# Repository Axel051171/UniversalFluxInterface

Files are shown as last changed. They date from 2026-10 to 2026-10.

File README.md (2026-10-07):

# UFI – Universal Flux Interface (Headless)

Flux-Lese-/Schreibgerät für Disketten: STM32H723 (550 MHz) misst jede Flusswechsel-Zeit mit
275 MHz (3,6 ns) und streamt sie per USB an den PC. Kein Raspberry Pi, kein Betriebssystem auf
dem Gerät – das frühere CM5-/Modul-Konzept ist aufgegeben (steht in der Git-Historie).

| | |
|---|---|
| MCU | STM32H723ZGT6, 550 MHz |
| Auflösung | 275 MHz Timer-Capture (3,6 ns), Index auf derselben Zeitbasis |
| Puffer | 8 MB QSPI-PSRAM (Ringpuffer beim Streamen, bis 200 Umdrehungen) |
| USB | USB-C, Full Speed, Datenstrom ~2 Byte je Flusswechsel, sendet während die Diskette dreht |
| Laufwerke | 34-pol PC/Shugart (DENSITY, DRATE, bis 4 Laufwerke), Amiga DB23 (Header, 2 Laufwerke), Apple Disk II (20-pol, 2 Laufwerke), Commodore IEC (1541) |
| Schreiben | Timer + DMA, Precompensation, Verify, WRITE-LOCK-Jumper |
| Platine v0.7 | 110 × 97 mm, 4 Lagen, geschaltete und gemessene Laufwerksversorgung, 4 GB SD-NAND fest verbaut, Erweiterungsheader, Apple-Disk-II-Port, zweites Amiga-Laufwerk (JP3) |
| Ohne PC | Taster: ganze Diskette als SCP auf den internen Speicher (mit Qualitätsbericht) oder Disk-zu-Disk-Kopie, danach als USB-Laufwerk am PC abholen |
| Greaseweazle-kompatibel | `UFI.CFG protocol=gw`: die Greaseweazle-Werkzeuge (`gw read`, `gw write`, …) erkennen das Board direkt |
| USB-Floppy | Betriebsart-Schalter: PC-Disketten (360K–2,88 MB, DMF) erscheinen am PC als normales USB-Diskettenlaufwerk, ohne Treiber; Atari ST, Commodore 1581 und Amiga 880K als Block-Laufwerk (Sektorabbild wie ST/D81/ADF) |

## Aufbau des Repos

| Ordner | Inhalt |
|---|---|
| [`kicad/UFI_Headless/`](kicad/UFI_Headless/README.md) | Schaltplan, Layout, Fertigungsdaten (`fertigung/`), Build- und ECO-Skripte |
| [`firmware/`](firmware/) | STM32H723-Firmware (CMake, STM32Cube HAL) |
| [`software/ufi_host/`](software/ufi_host/README.md) | Python-Host (`ufi`): Lesen/Schreiben, SCP-Export, Protokollbeschreibung |
| [`docs/`](docs/) | Amiga-DB23-Adapterkabel |

## Firmware bauen

```bash
cmake -S firmware -B firmware/build -G Ninja
cmake --build firmware/build        # -> ufi_firmware.bin
```

Erwartet arm-none-eabi-gcc und STM32Cube H7 V1.11.0 unter `~/STM32Cube/Repository/STM32Cube_FW_H7_V1.11.0`
(Pfad in `firmware/CMakeLists.txt`).

Flashen per SWD oder USB-DFU (Taster A beim Einschalten halten bzw. `ufi bootloader`).

## Status

Platine v0.6 ist fertig für die Bestellung (ERC/DRC sauber, JLC-Daten in `kicad/UFI_Headless/fertigung/`) – [Bestell-Anleitung JLC](kicad/UFI_Headless/docs/Bestellung_JLC.md).
Hardware und Firmware sind noch nicht am echten Gerät getestet – Ablauf für den Prototyp: [Inbetriebnahme-Checkliste](kicad/UFI_Headless/docs/Inbetriebnahme.md).

Lizenz: siehe [LICENSE](LICENSE).

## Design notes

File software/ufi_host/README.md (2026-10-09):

# ufi – PC-Tool für die UFI Flux Engine (UFI Headless)

Kommandozeilen-Tool (Protokoll UFI v2, Rückfall auf v1) über den USB-CDC-Port (unter Windows ohne Treiber, COM-Port wird per VID/PID `1209:4F54` gefunden).
Alternativ (Firmware ≥ 1.10, `UFI.CFG` `protocol=gw`): das Gerät spricht das Greaseweazle-Protokoll (PID `1209:4F57`, „gw-compat“) und wird mit den Greaseweazle-Werkzeugen (`gw read`, `gw write`, …) benutzt – dann nicht mit `ufi`.
Liest Spuren als Flux und speichert sie als **SCP** (SuperCard Pro) – Dekodierung/Konvertierung mit vorhandenen Werkzeugen (HxC, Greaseweazle `gw convert`, FluxEngine). Schreibt SCP-Images zurück.

```bash
pip install -e software/ufi_host[dev]
ufi info
ufi select a && ufi motor on && ufi recal
ufi read 0 0 -r 3                         # Zusammenfassung (Flux-Anzahl, RPM je Umdrehung)
ufi read-disk -o disk.scp --tracks 80 --sides 2 -r 3 --drive a
ufi write-disk disk.scp --verify --drive amiga
ufi iec-reset && ufi iec-send 0x28 && ufi iec-recv
ufi bootloader                            # danach: dfu-util -a 0 -s 0x08000000:leave -D ufi_firmware.bin
```

Nur mit UFI v2 (Firmware ≥ 1.12):

```bash
ufi caps                                  # Board-Revision, Firmware, caps-Bits im Klartext
ufi files [PFAD]                          # Verzeichnis auf dem SD-NAND
ufi get DUMP0001.SCP [-o d.scp]           # Datei herunterladen (READ_FILE in 4-KB-Stücken)
ufi put lokal.bin NAME.BIN                # Datei hochladen
ufi rm NAME.BIN
ufi cfg                                   # UFI.CFG anzeigen
ufi cfg drive=amiga revs=5                # Zeilen setzen/anhängen, zurückschreiben, CFG_RELOAD
ufi events                                # alle Ereignisse einschalten und ausgeben bis Strg+C
ufi mode flux|sd|floppy|gw                # USB-Betriebsart (Gerät meldet sich neu an)
ufi dump [--drive a --tracks 80 --sides 2 -r 3] | dump-status | dump-abort | copy
ufi power [MASKE]                         # Board-Status; Maske Bit0 FDD_5V, Bit1 FDD_12V
```

Laufwerksdiagnose (Firmware ≥ 1.13, caps-Bit 11):

```bash
ufi rpm [UMDREHUNGEN]                     # Drehzahl aus den Indeximpulsen: min/mittel/max, Impulsbreite
ufi scan [pc|ds]                          # welche Laufwerke antworten (a/b/amiga/amiga2 bzw. ds0-ds3): TRK0, Diskette dreht, Schreibschutz
ufi index-sim 300|360|off [--pulse 2000]  # Indeximpulse auf J9 Pin 6 (Flippy-Disketten), ohne Argument: Abfrage
ufi index-sim 300 --internal [--no-pin]   # Firmware ≥ 1.14: Impulse gelten intern als Index (Lesen/Schreiben ohne Draht)
ufi read-disk -o d.scp --hard-sectors 16  # Firmware ≥ 1.14: hartsektoriert (10/16/32 Löcher), auch bei read/write/write-disk
ufi read 17 0 --quarter 2                 # Firmware ≥ 1.14: Apple-Viertelspur (17,5); auch seek/write --quarter 1-3
ufi read 17 0 --steps 50:17.1,100:17.2    # Firmware ≥ 1.14: Kopfschritte nach Zeitplan während des Lesens (Spiradisc); auch write
ufi analyze 0 0 -r 5                      # Firmware ≥ 1.14: Drehzahl, Abstands-Spitzen, Kodierung/Bitzelle, Spurlänge, schwache Bits, Index→erster Sektor
ufi dump --tracks 0                       # Firmware ≥ 1.14: Spurzahl automatisch (höchste erreichbare Spur); UFI.CFG track_search=1 für 40-Spur-Disketten
ufi rpm-select 360                        # Firmware ≥ 1.14: 3-Mode-Laufwerk 300/360 U/min (UFI.CFG rpm_line, rpm_360); Kontrolle: ufi rpm
ufi dump --drive iec --tracks 35          # Firmware ≥ 1.14: 1541 an J8 über den Laufwerkscontroller nach DUMPnnnn.D64 (+ .LOG mit Fehlerblöcken)
ufi iec-nib -o disk.g64 [--halftracks] [--tracks 41]   # Firmware ≥ 1.14: Rohspuren (GCR) per Laufwerkscode in eine G64, Kopierschutz/Halbspuren
```

## Protokoll UFI v2 (Standard)

`ufi` spricht **UFI v2** – Spezifikation: [docs/USB_Protokoll.md](../../docs/USB_Protokoll.md), Abschnitt 3 (Rahmen `55 AA`, type/cmd/seq/status/len, CRC-16/CCITT-FALSE, Daten-/Ende-Rahmen für Lesen und Schreiben, Ereignisse, Dateien). Implementierung: `ufi_host/protocol2.py` (`Device2`, `FrameParser`, `connect`).

- Beim Öffnen: Kanal-Reset (10000 Baud), dann `PING` als v2-Rahmen. Antwortet das Gerät nicht in v2 (alte Firmware), nimmt `ufi` das v1-Protokoll (unten) und weist auf ein Firmware-Update hin; v2-Befehle (`caps`, `files`, `cfg`, …) melden dann einen Fehler.
- Lesen: `READ` → Annahme, Daten-Rahmen mit dem Flusscode (275 MHz, wie v1-Stream), Ende-Rahmen mit Umdrehungszahl. SCP-Ausgabe identisch zum v1-Weg.
- Schreiben: `WRITE` mit `flux_count`/`byte_count`, dann Daten-Rahmen im Flusscode (≤ 4096 Byte je Rahmen), Ende-Rahmen nach dem Schreiben (bzw. Prüflesen mit `--verify`).
- `selftest` gibt es in v2 nicht (PSRAM-Test steht in `ufi info`); `rpm` nutzt ab Firmware 1.13 `DIAG_RPM` (Indeximpulse, Motor wird gestartet), davor liest es eine Umdrehung der aktuellen Spur (Motor muss laufen).

## Protokoll UFI v1 (alt, Firmware < 1.12; Stream-Lesen braucht eine Firmware mit `ufi_stream.c`)

- Host → Gerät: ein Paket ≤ 64 Byte je Befehl, `[cmd, args...]` (Codes in `ufi_host/protocol.py` = `ufi_command_t`).
- Gerät → Host: jede Nachricht beginnt mit `{u8 command, u8 status, u16 length}` + Payload. Status = Fehlercode aus `ufi_fixes.h` (Klartext in `protocol.ERRORS`).
- Lesen (`READ_TRACK` 0x20, Standard): Antwort, dann **während die Diskette dreht** `{0x2C, 0, len}`-Nachrichten mit einem fortlaufenden Bytestrom (verlustfrei, 275 MHz, ~2 Byte je Flusswechsel): `01–EF` = Delta 1 Byte, `F0–FC b` = Delta 240 + ((x−F0)<<8) + b, `FD u32` = Indexpuls (Ticks nach dem letzten Wechsel), `FE u32` = langes Delta. Zeit 0 = erster Index; Format in `firmware/src/ufi_stream.c`, Decoder `protocol.decode_stream`. Abschluss `{0x2D, status, 1}` + `[Umdrehungen]`.
- Lesen roh (`READ_TRACK_RAW` 0x21, `Device.read_track_raw`): erst nach der Aufnahme je Umdrehung `{0x2E, 0, 12}` + `{track, side, rev, flags, index_ticks, count}` + `count × u32` Zeitstempel (relativ zum Index), gleicher Abschluss.
- Lesen-Optionen (beide Lesebefehle): `[cmd, track, side, revs, flags, period_ms u16]`. `flags` Bit0 = **ohne Indexpuls** (Laufwerk/Diskette ohne Index, Flippy-Seite, hart sektoriert): Umdrehungsgrenzen alle `period_ms` (0 = 200 ms). `READ_TRACK` erlaubt bis 200 Umdrehungen (Ringpuffer), `READ_TRACK_RAW` bis 20.
- Schreiben: Antwort abwarten, dann `count × u32` Deltas als Rohdaten, Fertig-Meldung mit demselben Befehlscode.
- Schreiben kompakt (`WRITE_TRACK_C` 0x33): `[cmd, track, side, count u32, bytes u32, verify]`, dann `bytes` Bytes im Stream-Code von oben (ohne `FD`-Indexmarken), Fertig-Meldung `0x33`. Etwa halbe Upload-Menge.
- `DRIVE_TIMING` (0x17): 10 × u16 – `step_pulse_us, step_rate_us, settle_us, dir_change_us, side_settle_us, spinup_ms, select_settle_us, motor_off_s` (Motor aus nach Leerlauf, 0 = nie, Standard 30), `double_step` (1 = 40-Spur-Diskette im 80-Spur-Laufwerk), `precomp_ns` (0xFFFF = nach Datenrate, 0 = aus). Kürzere Nutzdaten überschreiben nur die vorderen Felder.
- Board v0.5: `BOARD_STATUS` (0x1B, optional `[maske]` Bit0 FDD_5V, Bit1 FDD_12V) → `{power u8, flags u8, i5_mA u16, i12_mA u16, board_id_mV u16}`, Flags: Bit0 WRITE-LOCK-Jumper, Bit1/2 Überstrom-Abschaltung 5 V/12 V, Bit3 SD-Speicher bereit, Bit4/5 Taster A/B. `PROBE_TRACKS` (0x1C) → höchste erreichbare Spur (fährt an den Endanschlag). `SD_INFO` (0x1D) → `{ready, status, card_type, bus_width, capacity_MB u32}`.
- Laufwerke (`SELECT_DRIVE` 0x10, `ufi select`): 1 `a` / 2 `b` (PC-Kabel mit Twist), 4 `amiga` (J7), 5 `iec`, ab Firmware 1.5 Shugart-Bus 6–9 `ds0`–`ds3` (gerades Kabel, Pin 10/12/14/6 – `ds3` nur mit JP1; Motor Pin 16 gemeinsam), ab Firmware 1.9 10 `amiga2` (zweites Amiga-Laufwerk an J7 Pin 9, Board v0.7 mit JP3), ab Firmware 1.11 3 `apple` / 11 `apple2` (Disk-II-Port J14/J15, Board v0.7; kein Index: Umdrehungen = 200-ms-Abschnitte). Laufwerk für Dump/USB-Floppy: `UFI.CFG` auf dem SD-NAND (`drive=…`, `tracks=`, `sides=`, `revs=`).
- Board v0.6, SD-NAND (4 GB, FAT32): `DUMP_START` (0x50, optional `[drive, tracks, sides, revs]`, Standard Laufwerk A, 80, 2, 3) liest die ganze Diskette ohne PC nach `DUMPnnnn.SCP` – dasselbe Dateiformat wie `ufi read-disk`. `DUMP_STATUS` (0x51) → `{state, error, track, side, file_no u16, fs_result, storage_ready}` (state 6 = fertig, 7 = Fehler; error 1 Speicher, 2 Laufwerk, 3 voll, 4 abgebrochen). `DUMP_ABORT` (0x52). `COPY_START` (0x54): Disk-zu-Disk-Kopie laut `UFI.CFG` (`copy_from`, `copy_to`, `tracks`, `sides`), Status über `DUMP_STATUS`. Zu jedem Dump entsteht `DUMPnnnn.LOG` (Qualitätsbericht). Während eines Dumps beantwortet das Gerät nur Status-Befehle, alles andere mit BUSY. `USB_MSC` (0x53, optional `[mode]`: 1 = SD-Laufwerk (Standard, PID 0x4F55), 2 = **USB-Floppy** (PID 0x4F56: Diskette in Laufwerk A als USB-Laufwerk, Formate: PC 360K/720K/1.2M/1.44M, DMF 1.68M, ED 2.88M (nur lesen), Atari ST 9/10 Sektoren (11: nur lesen), Commodore 1581, Amiga 880K – Nicht-PC-Formate als Sektorabbild in ST-/D81-/ADF-Reihenfolge; Spurpuffer mit Rückschreiben nach 1 s und Prüflesen)): Antwort, dann meldet sich das Gerät neu – zurück per Betriebsart-Schalter, Taster B ≥ 2 s (SD) oder Neustart. Am Gerät: Taster A ≥ 1 s = Dump, Taster B kurz = Abbruch, B ≥ 2 s = SD-Laufwerk an/aus (nur Schalter in Mitte); Betriebsart-Schalter an J13 (Pin 1 = USB-Floppy, Pin 2 = Mittelkontakt 3V3, Pin 3 = SD-Laufwerk, Mitte = Flux).
- `GET_INFO`: Firmware-Version mit Git-Revision und Build-Datum, Board inkl. Revision (BOARD_ID), MCU, PSRAM-Selbsttest.
- Diagnose: `SEEK_TEST` (0x1E) `[spur_a, spur_b, zyklen ≤ 50]` pendelt zwischen zwei Spuren (Schrittmotor/Kopf); `WRITE_PATTERN` (0x34) `[track, side, interval_ns u16, dauer_ms u16 ≤ 5000]` schreibt ein konstantes Flussintervall (Schreibkette am Oszilloskop) – nur bei laufendem Motor, ohne WRITE-LOCK-Jumper und ohne Schreibschutz. Beide antworten erst am Ende.
- Startmodi (Taster beim Einschalten halten): A = ROM-DFU-Bootloader (Rettung ohne funktionierende Firmware), B = Sicherheitsmodus, Laufwerksversorgung bleibt aus (ERR-LED an, `BOARD_STATUS` Flag Bit6), einschalten per `BOARD_STATUS [maske]`.
- Sicherheit in der Firmware: USB weg > 300 ms → Transfers abbrechen, Motor aus, Laufwerk abwählen, WGATE frei; Laufwerksversorgung > 1,5 A für 50 ms → Schiene aus.

Tests ohne Hardware (simuliertes v1- und v2-Gerät auf Byte-Ebene, inkl. geteilter Rahmen, CRC-Fehler, Dateien, Rückfall auf v1): `python -m pytest software/ufi_host/tests`.

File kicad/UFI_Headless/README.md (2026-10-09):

# UFI Headless – STM32H723 Flux Engine (ohne CM5)

Status: **Schaltplan + Layout v0.6** – ERC 0 Verstöße, alle Netze per Netlist-Export geprüft; PCB-DRC 0 Fehler, 0 Warnungen (Details unten).

| Sheet | Inhalt | Status |
|---|---|---|
| Power | USB-C (5V + Daten), 12V-Hohlstecker, TPS54202 Buck 12→5V, TPS2116 Power-Mux, AP7361C 3V3-LDO, FDD-Power-Ausgang über Polyfuses F2 (+5V, 1,1 A) / F3 (+12V, 1,1 A), Messpunkte TP1–TP4 (3V3, 5V, 12V, GND) | ✅ |
| MCU_Core | STM32H723ZGT6 (LQFP144), Entkopplung, VCAP, VDDA-Filter, HSE 25 MHz, Reset/Boot, SWD, Debug-UART, LEDs, **8 MB QSPI-PSRAM** APS6404L (U11) an OCTOSPI1 | ✅ |
| Flux_Interface | 2× SN74LS07 Open-Collector (40 mA) für 10 Ausgänge, 74LVC14A Schmitt-Inverter für 6 Eingänge, 1k Pull-ups auf 5V, Messpunkte TP5 (RDATA) / TP6 (INDEX) | ✅ |
| FDD_Connectors | 34-pol IBM-PC/Shugart, Amiga 2×12-Header (Pin n = DB23 Pin n), ESD-Arrays D9–D11 (ESDA6V1-5SC6) auf 15 Busleitungen | ✅ |
| IEC_Bus | SN74LS07 + 74LVC14A, 1k Pull-ups, 1×6-Stiftleiste J8 (Pin n = DIN-6 Pin n: 1 SRQ, 2 GND, 3 ATN, 4 CLK, 5 DATA, 6 RESET), DIN-6-Buchse extern per Kabel, ESD-Array D12 | ✅ |

v0.2 (gegenüber v0.1): PSRAM, ESD-Schutz an den externen Ports, Polyfuses in der Laufwerksversorgung, Messpunkte. Neue Teile haben feste Referenzen oberhalb der v0.1-Maxima (U11, C46, R16, F2/F3, D9–D12, TP1–TP6), alle bestehenden Referenzen sind unverändert.

v0.4: J6 Pin 6 = DRATE über den freien LS07-Kanal U7.11→U7.10 (PF11, Pull-up RN3.3) und Lötbrücke **JP1** (offen ab Werk), J6 Pin 3 über 3-fach-Lötbrücke **JP2** (ab Werk 1-2 = GND). JP1/JP2 sind Kupfer-Jumper, keine Bestückung; Funktion steht im Bestückungsdruck auf der Rückseite, vorne markiert „5V“ die +5V-Seite von JP2 (`scripts/add_silk_label.py`).

v0.5 (neue Teile mit festen Referenzen ab Q1, U12, R17, C47, D13, J9, SW3, TP7):

| Funktion | Teile | Bedienung / Firmware |
|---|---|---|
| Laufwerksversorgung schaltbar | Q1/Q3 AO3401A (High-Side), Q2/Q4 2N7002, 100k-Pull-downs | FDD_5V/FDD_12V aus, solange die MCU im Reset ist; Firmware schaltet 5 V, dann 12 V ein (`BOARD_STATUS` 0x1B) |
| Strommessung | R26/R29 0,1 Ω + U12/U13 INA180A1 (2 V/A) → PC0/PC1 | > 1,5 A für 50 ms → Schiene aus, ERR-LED |
| TVS an den Laufwerksausgängen | D13 SMF5.0CA (FDD_5V), D14 SMAJ15CA (FDD_12V) | – |
| WRITE LOCK | J11 (Jumper), U14 74LVC1G32, R33 | Jumper gesteckt = WGATE in Hardware gesperrt, Firmware meldet „write protected“ |
| Erweiterung | J9 2×5: 3V3, 5V, I²C1 (PB6/PB7, 2,2k), GPIO PE0/PE1, Taster-Leitungen | z. B. OLED-Display + Taster für Betrieb ohne PC; Pin 6 (PE1) ab Firmware 1.13 wahlweise Index-Simulation (Open-Drain, `ufi index-sim 300`/`UFI.CFG index_sim=300`) → Draht an den Indexsensor-Ausgang eines PC-Laufwerks für Flippy-Disketten; dann kein Betriebsart-Schalter an J13 |
| Taster | SW3/SW4 (PB8/PB9, aktiv low) | frei für Firmware-Funktionen |
| ~~microSD~~ | in v0.6 durch SD-NAND U15 ersetzt (s. u.) | – |
| Board-ID | R17/R18 an PA4 | 10k/10k = 1,65 V = v0.5, 10k/4,7k = 1,06 V = v0.6; steht in `GET_INFO` |
| Messpunkte | TP7 WDATA, TP8 WGATE (MCU-Seite) | – |

v0.6 (Gerät kommt in ein geschlossenes Gehäuse): microSD-Slot J10 entfällt, dafür **SD-NAND U15** fest eingelötet an denselben SDMMC2-Leitungen (Pull-ups R21–R25, C47/C48 bleiben).

| Funktion | Teile | Bedienung / Firmware |
|---|---|---|
| Speicher 4 GB | U15 CSNP32GCR01-AOW (C2841139), LGA-8 8×6,2 mm; derselbe Footprint passt für MKDV8GIL-AST (1 GB, C26159627, günstiger) | FAT32, beim ersten Start formatiert (Volume „UFI“) |
| Dump ohne PC | Taster A ≥ 1 s | ganze Diskette → `DUMPnnnn.SCP` (byte-gleich mit `ufi read-disk`); Taster B kurz = Abbruch |
| Betriebsart-Schalter (optional, extern) | Kippschalter EIN-AUS-EIN an **J13** (1×3, Belegung wie der Schalter): Pin 1 → EXP_IO1/PE0, Pin 2 = 3V3 (Mittelkontakt), Pin 3 → EXP_IO2/PE1 (parallel zu J9 Pin 5/6, die dann nicht anders belegt werden dürfen) | Mitte = Flux (Host-Tool), Pin 1 = **USB-Floppy** (Diskette in Laufwerk A als USB-Laufwerk, PC-Formate 360K/720K/1.2M/1.44M, PID 0x4F56), Pin 3 = SD-Laufwerk. Nach jedem Wechsel blinkt ACT 1×/2×/3× = Flux/Floppy/SD |
| USB-Laufwerk | Taster B ≥ 2 s (nur Schalter in Mitte; oder `USB_MSC` 0x53) | Gerät meldet sich als Massenspeicher „UFI Flux Storage“ (PID 0x4F55), USB-LED an; Taster B ≥ 2 s zurück |
| Board-ID | R18 4,7k | 1,06 V = v0.6 |
| Einstellungen ohne PC | Datei `UFI.CFG` auf dem SD-NAND (wird beim ersten Start angelegt, im SD-Laufwerk-Modus am PC bearbeiten) | `drive=a\|b\|amiga\|amiga2\|ds0…ds3` (Laufwerk für Dump und USB-Floppy), `tracks=80`, `sides=2`, `revs=3`, `button_a=dump\|copy`, `copy_from=`/`copy_to=` (Laufwerksnamen wie bei `drive`), `protocol=ufi\|gw`; Schlüssel klein schreiben |
| Greaseweazle-Modus | Firmware 1.10, `UFI.CFG` `protocol=gw`, Schalter in Mitte (ACT blinkt 4×) | Gerät meldet sich als „UFI Flux Engine (gw-compat)“ (eigene PID 0x4F57); die Greaseweazle-Werkzeuge finden es ohne `--device`: `gw info`, `gw read --drive A disk.scp`, `gw write`, `gw erase`, `gw seek`, `gw delays`. Bus IBM PC (Laufwerk A/B) und Shugart (0–3); Abtastrate 68,75 MHz. Nicht möglich: Amiga-Port J7, IEC, Firmware-Update per `gw update`, `gw bandwidth`, Flippy-Laufwerke, hartsektorierte Disketten. Das UFI-Host-Tool `ufi` braucht `protocol=ufi` |
| Qualitätsbericht | Firmware 1.8 | Zu jedem Dump `DUMPnnnn.LOG`: pro Spur gute/erwartete Sektoren, Drehzahl, Leseversuche (schwache Spuren bis zu 3× gelesen), am Ende Anzahl schlechter Spuren. Format wird auf Spur 0.0 erkannt (PC, DMF, ED, Atari, 1581, Amiga); sonst nur Drehzahl |
| Diskette kopieren | Firmware 1.8, `button_a=copy` + Taster A ≥ 1 s (oder `COPY_START` 0x54) | Flux-Kopie Spur für Spur von `copy_from` nach `copy_to` (z. B. A → B oder ds0 → ds1), mit Prüflesen; Fortschritt/Fehler über `DUMP_STATUS` und ERR-Blinkcode (2 Lesen, 3 Schreiben/Schreibschutz). Kopiergeschützte Disketten mit Spurlängen-Tricks werden nicht garantiert kopiert |
| Front-LEDs (Gehäuse) | J12 2×4 + R34–R37 330 Ω (≈ 4 mA), je LED eine Reihe: 1+/2− PWR, 3+/4− ACT, 5+/6− FDD, 7+/8− ERR | parallel zu den Board-LEDs, keine Firmware-Änderung |

Projektbibliothek für U15: `lib/UFI_Headless.kicad_sym` und `lib/UFI_Headless.pretty` (in `sym-lib-table`/`fp-lib-table`); `kisch.py` und `add_parts.py` suchen dort zuerst.

A8 (Verpolschutz 12 V) war schon vorhanden: SS54 in Reihe + SMAJ15CA. A10 (50-pol 8"-Anschluss) passt nicht auf 110×85 mm – 8"-Laufwerke über externen Adapter.

Bestellung: [docs/Bestellung_JLC.md](docs/Bestellung_JLC.md) · Inbetriebnahme des Prototyps: [docs/Inbetriebnahme.md](docs/Inbetriebnahme.md).

## Signalpolarität (wichtig für Firmware)

- **Ausgänge** (FDD_*, IEC_*_OUT): MCU **low** = Busleitung aktiv (low). MCU high bzw. Reset/High-Z = losgelassen (TTL-Eingang des LS07 floatet high).
- **Eingänge** (FDD_INDEX/TRK0/WPROT/RDATA/DSKCHG/READY, IEC_*_IN): durch den 74LVC14A **invertiert** – MCU **high** = Busleitung aktiv (low). RDATA/INDEX-Capture daher auf **steigende** Flanke.

## 34-pol Stecker (J6)

Ungerade Pins GND (Pin 3 über JP2). 2 DENSITY · 6 DRATE (nur mit JP1) · 8 INDEX · 10 MOTOR_A · 12 DRVSEL_B · 14 DRVSEL_A · 16 MOTOR_B · 18 DIR · 20 STEP · 22 WDATA · 24 WGATE · 26 TRK0 · 28 WPROT · 30 RDATA · 32 SIDE · 34 DSKCHG/READY · 4 frei.

| Lötbrücke | Ab Werk | Umbau |
|---|---|---|
| JP1 (Pin 6) | offen – Pin 6 unbeschaltet | brücken für 3-Mode-Laufwerke (DRATE, Firmware `SET_LINES` 0x1A) |
| JP2 (Pin 3) | 1-2 gebrückt = GND | Leiterbahn 1-2 auftrennen, 2-3 brücken = +5V (FDD_5V, über F2) – **nur** für PS/2-Laufwerke mit Versorgung an Pin 3; ein normales Laufwerk hat dort GND → Kurzschluss (F2 löst aus) |
**Shugart-Bus** (Firmware 1.5, gerades Kabel, Laufwerke per Jumper DS0–DS3): Pin 10 = DS0, 12 = DS1, 14 = DS2, **6 = DS3 (nur mit JP1)**, Pin 16 = MOTOR ON für alle → bis zu **4 Laufwerke**. Auswahl `ufi select ds0…ds3` bzw. `UFI.CFG` `drive=ds0…ds3`. Alle Motoren laufen gemeinsam (Strom beim Anlauf beachten); JP1 als DS3 schließt DRATE aus; ein Amiga-Laufwerk an J7 belegt DS1 (Pin 12). PC-Belegung (A/B mit Twist) und Shugart-Bus nicht an einem Kabel mischen.
Abweichungen der Shugart-Belegung (abgeglichen mit pinouts.ru „Floppy Diskdrive pinout“): **Pin 34 = READY** statt DSKCHG – die Firmware (ab 1.6) wertet ihn bei DS0–DS3 als READY; **Pin 2 = /DCD, ein Ausgang des Laufwerks** – bei uns der DENSITY-Ausgang, beide Open-Collector, also harmlos, aber nicht lesbar. Folge: am Shugart-Bus gibt es **keine Diskettenwechsel-Erkennung**. Im USB-Floppy-Modus wird der Spurpuffer verworfen, sobald der Motor stoppt (nie Daten einer Diskette auf eine andere schreiben); nach einem Diskettenwechsel den Betriebsart-Schalter kurz auf Flux und zurück, damit der PC die neue Diskette einliest.

## Amiga-Header (J7) – gegen Amiga HRM verifiziert

Belegung nach Amiga Hardware Reference Manual, Header-Pin n = DB23-Pin n:
1 /RDY · 2 /DKRD · 3–7 GND · 8 /MTRXD · 9 /SEL2B · 10 /DRESB · 11 /CHNG · 12 +5V · 13 /SIDEB · 14 /WPRO · 15 /TK0 · 16 /DKWEB · 17 /DKWDB · 18 /STEPB · 19 /DIRB · 20 /SEL3B · 21 /SEL1B · 22 /INDEX · 23 +12V · 24 GND.
SEL1B teilt sich DRVSEL_B, MTRXD teilt sich MOTOR_B mit dem 34-pol Bus → nur ein Laufwerk gleichzeitig betreiben. SEL2B/SEL3B/DRESB per 1k auf +5V inaktiv.

**v0.7: zweites Amiga-Laufwerk (DF2)** über Lötbrücke **JP3** (offen ab Werk): gebrückt treibt DRVSEL_A den Pin 9 /SEL2B (ESD über D11). Zwei externe Amiga-Laufwerke hintereinander (z. B. A1010 mit Durchschleif-Port, Pin 9 → Pin 21 des zweiten); Firmware 1.9 `ufi select amiga2` bzw. `UFI.CFG` `drive=amiga2`, Kopie `copy_from=amiga`/`copy_to=amiga2`. Jedes Amiga-Laufwerk übernimmt /MTRXD bei der fallenden Flanke seines SEL (Flipflop im Laufwerk, primrosebank.net „Floppy Disk Connection“) – die Firmware legt beim Anwählen den gespeicherten Motorzustand an, Umschalten DF1↔DF2 hält die Motoren. Mit JP3 gebrückt kein Laufwerk an J6 Pin 14 (PC-Laufwerk A / DS2) gleichzeitig betreiben.

Belegung bestätigt gegen Amiga Hardware Reference Manual, Appendix E „External Disk Interface Specification“ (alle 23 Pins). `docs/Amiga_DB23_Adapter_Cable.md` wurde entsprechend korrigiert (vorher GND auf DB23 12/15/20/23 und falsches Steckergeschlecht).

## Apple-Disk-II-Port (J14, J15) – ab v0.7

Platine dafür unten um 12 mm verlängert (110 × 97 mm, zusätzliche Befestigungslöcher H5/H6). J14 = 2×10-Wannenstecker mit der Belegung des Laufwerkssteckers der Disk-II-Controllerkarte – ein Disk-II-Laufwerk wird mit seinem Originalkabel direkt angesteckt:

1/3/5/7 GND · 2/4/6/8 PH0–PH3 · 9 −12 V · 10 /WRREQ · 11/12 +5 V · 13/15/17/19 +12 V · 14 /ENABLE · 16 RDDATA · 18 WRDATA · 20 WRPROT

- Ausgänge über SN74AHCT244 (U16) an FDD_5V: TTL-Pegel, ohne Laufwerksversorgung stromlos (keine Rückspeisung). Phasen aktiv high, /ENABLE und /WRREQ aktiv low, WRDATA wechselt je Flusswechsel den Pegel (TIM3_CH2 im Toggle-Modus). 10k auf der MCU-Seite halten beim Reset alles inaktiv (RN9/RN10).
- Eingänge RDDATA/WRPROT: 10k nach FDD_5V, 74LVC2G17 (U17) an 3V3. RDDATA auf TIM2_CH3 – gleicher Zähler wie die 34-pol Flusserfassung. Ohne Laufwerk meldet WRPROT „geschützt“.
- −12 V (Pin 9) aus FDD_12V mit ICL7662 (U18), Innenwiderstand ≈ 100 Ω – nur für die Disk-II-Analogkarte (wenige mA). Das „Apple 5.25 Drive“ (DB19) braucht keine −12 V.
- **J15** (1×2): /ENABLE eines zweiten Laufwerks (U16 Ausgang 2Y1) + GND – für ein Adapterkabel auf einen zweiten Disk-II-Stecker oder DB19 Pin 9 (/DRIVE2, Daisy-Chain wie am Apple-5.25-Controller).
- DB19-Laufwerke (Apple 5.25 Drive, UniDisk 5.25) über Adapterkabel 20-pol → DB19. **Nicht** unterstützt: Apple 3.5 Drive / UniDisk 3.5 (/EN3.5, SmartPort; DB19 Pin 4 bleibt GND), Macintosh-Laufwerke.
- ESD auf allen Signalleitungen am Stecker (D15, D16).
- **J19 Sync-Sensor** (1 +5 V FDD_5V, 2 GND, 3 SYNC; Bestückungsdruck „+5V GND SYNC“ an den Pins): für einen Sync-Sensor nach Applesauce-Art (Magnet an der Spindel, Hall-Sensor A3144, Open-Collector mit 10k Pull-up, aktiv low, ≥ 500 µs je Umdrehung; wiki.applesaucefdc.com „Sync Sensor“). SYNC liegt direkt auf der INDEX-Leitung des 34-pol Busses (Wired-OR, 1k Pull-up, ESD D11, LVC14 → TIM2_CH2) – elektrisch verhält sich der Sensor wie der Index-Ausgang eines Laufwerks. 34-pol Laufwerke treiben INDEX nur, solange sie angewählt sind. Mit `UFI.CFG apple_sync=1` liest die Firmware Apple-Laufwerke indexbasiert (echte Umdrehungen, SCP mit Index-Flag) und schreibt ab dem Sensorimpuls – Spuren bleiben zueinander ausgerichtet (Kopierschutz mit Spur-Synchronisation). Applesauce-Sensoren haben ein 3,5-mm-Klinkenkabel: Adapter auf J19, Belegung der Klinke vor dem Anschluss am Sensor durchmessen.
- **Schreibschutz**: Der WRITE-LOCK-Jumper J11 sperrt in Hardware nur WGATE des 34-pol Busses; für den Apple-Port prüft die Firmware den Jumper (kein Schreiben mit gestecktem Jumper), die Hardware nicht.
- Firmware 1.11: Laufwerke `apple` (J14) und `apple2` (J15), `ufi select apple`, `UFI.CFG drive=apple` (`tracks=35`, `sides=1`). Kein Indexloch: Umdrehungen = 200-ms-Abschnitte, SCP mit Disk-Typ Apple II ohne Index-Flag. Kopf: 4-Phasen-Schrittmotor, 2 Halbschritte je Spur, Rekalibrieren = 80 Halbschritte gegen den Anschlag (Klackern, wie beim Original). Schreiben startet sofort (kein Index), Löschen = /WRREQ ohne Pegelwechsel. Board-ID 10k/2,2k = 0,6 V → „v0.7“, nur dann sind die Apple-Laufwerke wählbar.

## Stromaufnahme +5V (Abschätzung)

3× LS07 ≈ 0,12 A · Pull-ups worst case ≈ 0,1 A · MCU über LDO ≈ 0,35 A · 3,5"-Laufwerk ≈ 0,5–1 A Spitze → ≈ 1,5 A. TPS2116 (2,5 A) und Buck (2 A) reichen; an USB-only über dem 500-mA-Default.

## Erzeugen / Prüfen

Die Schaltpläne werden per Skript generiert – **nicht** von Hand in Eeschema bearbeiten, solange das Design noch im Fluss ist (Änderungen gehen beim nächsten Lauf verloren).

```bash
PY="C:/Program Files/KiCad/10.0/bin/python.exe"
CLI="C:/Program Files/KiCad/10.0/bin/kicad-cli.exe"
cd kicad/UFI_Headless
"$PY" scripts/build_schematic.py                       # schreibt *.kicad_sch + netlist_summary.txt
"$CLI" sch erc --severity-all -o erc.rpt UFI_Headless.kicad_sch
"$CLI" sch export netlist -o headless.net UFI_Headless.kicad_sch
"$PY" scripts/verify_netlist.py headless.net           # Soll/Ist-Vergleich aller Netze
```

## Layout (v0.2, v0.1 automatisch erzeugt + inkrementelle ECO)

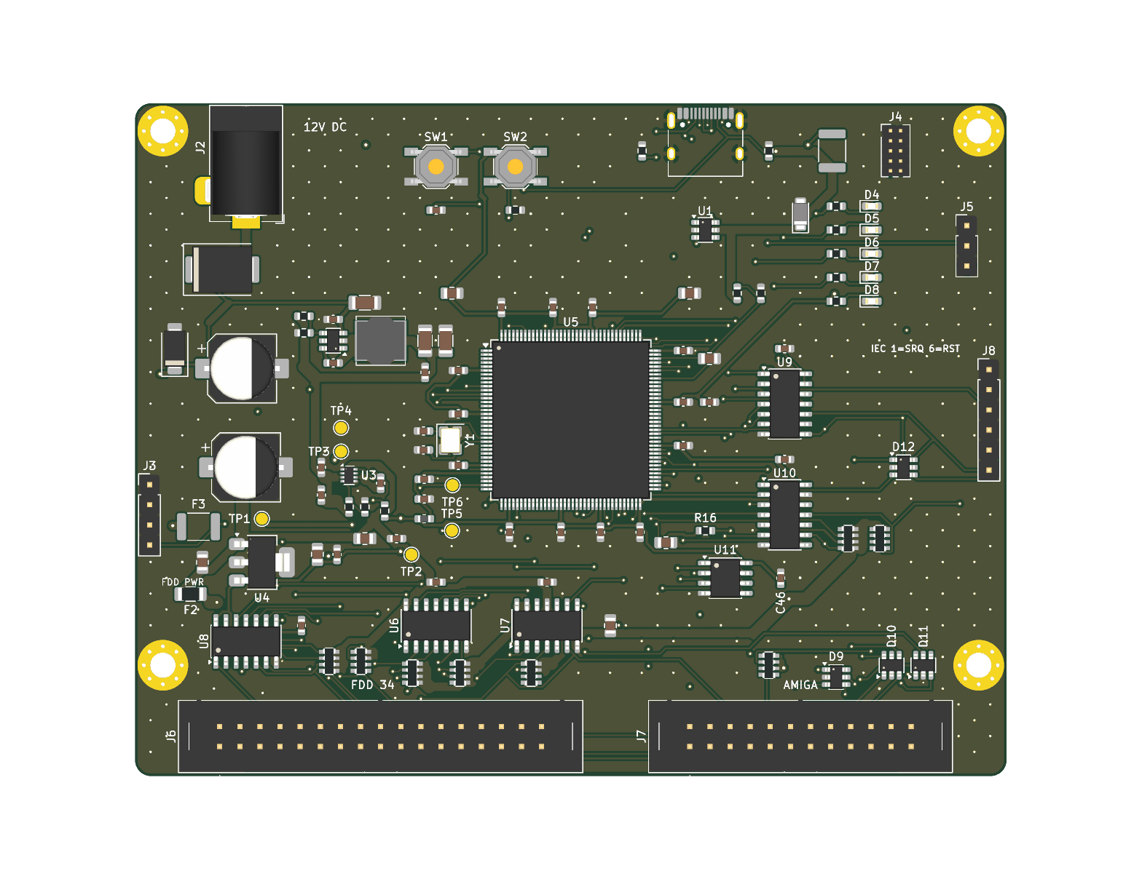
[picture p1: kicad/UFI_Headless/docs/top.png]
top


- 110 × 85 mm (v0.1–v0.6; ab v0.7 110 × 97 mm, 6× M3), 4 Lagen, 115 Bauteile (inkl. 6 Messpunkt-Pads), 4× M3
- DRC: **0 Fehler, 0 Warnungen, 0 unverbundene Elemente, Schaltplan-Parität ok**, kein Via-in-Pad. IDC-Konturen von J6/J7 ragen absichtlich über den Rand: per Regel `idc_edge_silk` in `UFI_Headless.kicad_dru` ausgenommen (Fertiger clippt), Bibliotheks-Footprints unverändert
- Fertigungsdaten in `fertigung/`: `UFI_Headless_gerber.zip` (Gerber + Excellon), `UFI_Headless-bom.csv`, `UFI_Headless-pos.csv` (KiCad) und `UFI_Headless-cpl-jlc.csv` (JLC-Spaltennamen + Gehäuse-Rotationsoffsets, `scripts/jlc_cpl.py`), `JLC_Rotation_Check.md` (Pin-1-Checkliste für den JLC-Viewer)

### Layout-Review (gemessen mit `scripts/layout_metrics.py`)

| Bereich | Ergebnis |
|---|---|
| Quarz Y1 | HSE_IN/HSE_OUT je 9,0 mm inkl. Lastkondensatoren, **keine Vias**, symmetrisch (vorgeroutet) |
| Buck TPS54202 | Eingangs-C 100 nF 1,8 mm an VIN, SW-Knoten 2,8 mm gerade zu L1 (0,6 mm), FB-Teiler direkt an Pin 4 (vorgeroutet) |
| Versorgung | Supply-Pours entlang der Routen (`power_pours.py`): +5V/+12V/VBUS ~0,85–1,8 mm effektiv, VBUS_F über In2 ~1,5 mm |
| MCU | 100 nF ~2,8 mm vor jedem VDD-Pin, alle VSS-Pins per Stich + Via direkt auf die GND-Lage |
| USB | D+/D− 43/44 mm (USB FS: Länge/Impedanz unkritisch), ESD U1 zwischen Buchse und MCU |

Handkorrekturen nach dem Autorouting (einmalig auf diesem Board, nicht Teil von `make_pcb.sh`): IEC_RESET-Sackgasse an RN8 ersetzt, PWR_SRC auf B.Cu nach y = 48 mm verlegt, GND-Vias an C33 (VDDA) und am Buck-GND (U2.1/C3.2); nach dem Tausch J8 DIN-6 → Stiftleiste (`scripts/swap_footprint.py` + inkrementelles Freerouting) IEC_SRQ U9↔U10 auf In2 bei x = 87,07 mm; CC2 an J1 links am VBUS-Via vorbei; v0.2-ECO: FD_DRVSEL_B unter D11 auf y = 74 mm verlegt (Platz für das GND-Via von D11.2), TP2/TP6 per `scripts/fix_connections.py` auf ihre Netz-Leiterbahnen gesetzt, Referenztexte per `scripts/place_refs.py`; v0.4-ECO: JP1/JP2 mit `ECO_SEARCH=4` in die Lücke U8/J6 gesetzt, die +5V-Verteilung (lief in v0.3 über U7.11) aus v0.3 übernommen bzw. per B.Cu-Brücke C40↔C41 ergänzt, zwei GND-Stitching-Vias für die Diagonale C43→RN6 entfernt, FD_DRATE U7.10→RN3.3 auf In2 von Hand verlegt; v0.5-ECO: Laufwerksversorgung rechts unten (x 85–106), J10 (microSD) mit Kartenöffnung zur Oberkante, R1 unter die USB-C-Buchse, TP8 misst WGATE hinter dem Sperr-Gatter (alte v0.4-WGATE-Kette dafür umgenetzt), +5V zu RN7/RN8 auf B.Cu, I_FDD5/SD_D1/SD_D3/+3V3/GND(J10.6) mit `scripts/eco/` von Hand bzw. per Labyrinth-Router (`maze_route.py`) verlegt, DRU-Regel für J9 Pin 1 (ein Thermal-Steg + Bahn). Ein neuer Pipeline-Lauf routet anders und kann andere Nacharbeit brauchen – **dieses Board ist der geprüfte Stand**.

### Vor einer Bestellung noch offen

1. **Bestelloptionen**: kein Via-in-Pad mehr (VBUS-Vias neben A4/A9, 0,5/0,25 mm) → „Via Covering: Tented“ reicht; kleine Vias 0,48/0,23 bzw. 0,5/0,25 mm – Aufpreis für < 0,3 mm Bohrung möglich. Alle Vias Restring ≥ 0,125 mm (DRC-Regel `min_via_annular_width`)
2. **Rotationen im JLC-Bestückungsviewer** gegen `fertigung/JLC_Rotation_Check.md` prüfen (22 gepolte Teile; Offsets nach kicad-jlcpcb-tools sind schon eingerechnet, SOT-583 U3, Y1, Dioden und J1 ohne Offset – dort besonders genau hinsehen)
3. **Handbestückung**: J2 (Hohlbuchse 5,5/2,1) und J7 (2×12 Wannenstecker) haben keine LCSC-Nummer
4. **IEC-Kabel**: J8 (1×6, 2,54 mm) auf DIN-6-Buchse, 1:1 nach Pinnummer (Lötseite der Buchse beachten)

## Layout-Pipeline (`scripts/make_pcb.sh`)

```bash
export TOOLS=<dir mit jdk-25*-jre + freerouting-2.4.1.jar>
bash scripts/make_pcb.sh eco U11:68:54 C46:77.5:57.5 ...   # Änderung am geprüften Board (Normalfall)
bash scripts/make_pcb.sh all                               # Neu-Layout von Null (place | route | all)
```

**Das geprüfte Board ist die Layout-Quelle.** Schaltplanänderungen kommen per `eco` hinein: `add_parts.py` setzt alle Pad-Netze aus der Netzliste neu, platziert neue Referenzen nahe dem angegebenen Punkt (frei von Courtyards, Löchern und gesperrten Leiterbahnen, möglichst wenige Bahnen im Weg), entfernt nur die Bahnen darunter; danach Pours entfernen, inkrementell routen (Schritte 2–6), Pours neu. Handkorrekturen bleiben dabei erhalten. `all` erzeugt ein neues Layout, das ein neues Review braucht. Netzklassen (Power/Supply) stehen in `.kicad_pro` und `build_pcb.py`.

1. `build_pcb.py` – Footprints aus der Schaltplan-Netlist (mit KIID-Pfaden → Schaltplan-Parität), Platzierung, Outline (seit v0.7 110×97 mm), M3-Löcher, In1-GND-Plane, vorgeroutete USB-C-Auffächerung (gesperrt)
2. Freerouting 2.4.1 (Java 25) – F.Cu / In2.Cu / B.Cu als Signallagen, In1.Cu GND-Plane
3. `drop_violations.py` – Freerouting-Leiterbahnen mit DRC-Verstoß löschen und neu routen (bis sauber)
4. `widen_power.py` – Versorgungsnetze auf 0,8 mm (GND/3V3 0,5 mm) verbreitern, wo DRC es erlaubt
5. `finish_pcb.py` – GND-Pours F/B, +3V3-Pour In2, GND-Stitching-Vias, Inseln anbinden, Zonen füllen, Via-Bohrungen auf Restring ≥ 0,125 mm verkleinern
6. `power_pours.py` – Versorgungs-Pours entlang der Routen

Lagenaufbau: F.Cu Signal + GND-Pour · In1.Cu GND-Plane · In2.Cu Signal + 3V3-Pour · B.Cu Signal + GND-Pour.
Hinweis Fertigung: kein Via-in-Pad. VBUS-Vias sitzen neben den A4/A9-Pads (die NPTH-Stifte direkt darunter erzwingen den Versatz nach innen), CC2 läuft links am A9-Via vorbei. D−-Vias an J1 sind 0,48/0,23 mm.

## Stromversorgung

```
USB-C / J16 VBUS ──Polyfuse 1.5A──► VBUS_F ──────────────────────────┐ VIN2 (Fallback)
12V Jack / J17 Pin 4 ──SS54──► +12V ──TPS54202──► +5V_DRV ── J18 1-2 ─┤ VIN1 = +5V_PRI
J17 Pin 1 (PSU +5V) ──F4 1.5A──► +5V_PSU_F ──────────────── J18 2-3 ─┘ (Priorität, Schwelle ≈4.3V)
                     │                             TPS2116 ──► +5V ──► AP7361C ──► +3V3
                     └─F3 1.1A─► FDD_12V           (2.5A)      └─F2 1.1A─► FDD_5V
                                 (J3 Pin 4, J7 Pin 23)                     (J3 Pin 1, J7 Pin 12)
```

**v0.7 – Einbau im PC-Gehäuse:**
- **J16** interner USB-2.0-Header (2×5, **Stift 9 nicht bestücken** = Kodierung, Pad 9 bleibt frei), Belegung wie der Mainboard-Header (Port 1): 1 +5 V, 3 D−, 5 D+, 7/8 GND, 2/4/6/10 frei → 1:1-Kabel 9-pol Buchse–Buchse zum Mainboard. **Steckrichtung:** Bestückungsdruck „1“ = Pin 1 (+5 V), darunter „5V D- D+ GND“ an der Stiftreihe 1/3/5/7, „X“ = Kodierstelle Pin 9. Das zugestopfte Loch der Kabelbuchse kommt auf „X“ – genau wie am Mainboard, wo an derselben Stelle der Stift fehlt. Liegt parallel zur USB-C-Buchse: **immer nur einen Host anschließen** (USB-C oder J16).
- **J17** Stromeingang vom PC-Netzteil, Floppy-(Berg-)Stecker: 1 +5 V, 2/3 GND, 4 +12 V. Die 12 V laufen wie die der Hohlbuchse über SS54/TVS: **J2 oder J17, nicht beide**. +5 V über eigene Polyfuse F4 und TVS D17.
- **J18** Jumper für die 5-V-Vorrangquelle des TPS2116: **1-2 = 12-V-Wandler** (ab Werk, Hohlbuchse oder Netzteil-12 V), **2-3 = Netzteil-5 V direkt** (Bestückungsdruck: „BUCK“ / „EXT“). USB bleibt in beiden Stellungen die automatische Ausweichquelle (fehlt die Vorrangquelle, übernimmt USB). Ohne Jumper läuft das Board nur über USB.

Ein Kurzschluss im Laufwerkskabel löst nur F2/F3 aus; +5V/+3V3 der Logik bleiben stehen.

- Nur USB: Logik + 3,5"-Laufwerk aus USB-C. Ohne CC-Auswertung ist offiziell nur der USB-Default-Strom (500 mA) zugesichert; 3,5"-Laufwerke laufen damit in der Praxis meist (wie bei Greaseweazle), für Spec-Konformität später CC-Spannung per ADC auswerten.
- 12V gesteckt: Laufwerks-5V aus dem Buck, 12V für 5,25"-Laufwerke.
- `PWR_SRC` (TPS2116 ST, open-drain, Pull-up auf 3V3) → PG4, Firmware kann die aktive Quelle lesen.

## GPIO-Belegung (Referenz für Firmware)

| Signal | Pin | Funktion |
|---|---|---|
| FDD_RDATA | PA5 | TIM2_CH1 (AF1) Input Capture, 32 bit |
| FDD_INDEX | PA1 | TIM2_CH2 (AF1) Input Capture, gleiche Zeitbasis wie RDATA |
| FDD_WDATA | PA6 | TIM3_CH1 (AF2) Output |
| FDD_MOTOR_A / _B | PE7 / PE8 | GPIO out |
| FDD_DRVSEL_A / _B | PE9 / PE10 | GPIO out |
| FDD_STEP / DIR / SIDE | PE11 / PE12 / PE13 | GPIO out |
| FDD_WGATE / DENSITY | PE14 / PE15 | GPIO out |
| FDD_DRATE | PF11 | GPIO out → U7.11, J6 Pin 6 nur über JP1 (v0.4) |
| APL_PH0 / PH1 / PH2 / PH3 | PF12 / PF13 / PG6 / PF15 | GPIO out → U16 (AHCT244) → J14 Pin 2/4/6/8, high = Phase an (v0.7) |
| APL_EN1 / APL_EN2 | PG5 / PB12 | GPIO out, low = /ENABLE J14 Pin 14 / J15 Pin 1 (v0.7) |
| APL_WRREQ | PB14 | GPIO out, low = /WRREQ J14 Pin 10 (v0.7) |
| APL_WRDATA | PA7 | TIM3_CH2 (AF2) Toggle → J14 Pin 18 (v0.7) |
| APL_RDDATA | PA2 | TIM2_CH3 (AF1) Input Capture ← U17 ← J14 Pin 16 (v0.7) |
| APL_WRPROT | PB15 | GPIO in ← U17 ← J14 Pin 20, high = geschützt (v0.7) |
| FDD5_EN / FDD12_EN | PE2 / PE3 | GPIO out, high = Laufwerksversorgung an (v0.5) |
| I_FDD5 / I_FDD12 | PC0 / PC1 | ADC1 INP10/INP11, INA180A1 2 V/A (v0.5) |
| WLOCK | PE4 | GPIO in, high = WRITE-LOCK-Jumper gesteckt (v0.5) |
| BOARD_ID | PA4 | ADC1 INP18, Teiler = Board-Revision (v0.5) |
| I2C_SCL / I2C_SDA | PB6 / PB7 | I2C1 (AF4) auf J9 (v0.5) |
| EXP_IO1 / EXP_IO2 | PE0 / PE1 | GPIO auf J9 (v0.5) |
| BTN_A / BTN_B | PB8 / PB9 | GPIO in, Pull-up, low = gedrückt (SW3/SW4, J9) (v0.5) |
| SD CK / CMD / D0–D3 | PD6 / PD7 / PG9–PG12 | SDMMC2 (AF11, D2/D3 AF10) (v0.5) |
| (frei) | PG13 | v0.5 Card-Detect, ab v0.6 unbenutzt |
| FDD_TRK0 / WPROT / DSKCHG / READY | PF0 / PF1 / PF2 / PF3 | GPIO in |
| IEC_{ATN,CLK,DATA,SRQ,RESET}_OUT | PD0–PD4 | GPIO out → OC-Treiber |
| IEC_{ATN,CLK,DATA,SRQ,RESET}_IN | PF4–PF8 | GPIO in |
| USB D− / D+ | PA11 / PA12 | OTG_HS mit internem FS-PHY |
| VBUS_SENSE | PA9 | Teiler 22k/33k (5V → 3,0V) |
| CC1 / CC2 | PA0 / PA3 | ADC1 INP16/INP15: Spannung an Rd 5,1k → USB-C-Quellenstrom 0,5/1,5/3 A (`ufi usb-power`), v0.3 |
| (Atari SIO, optional) | PD1 / PF6 / PD0 | UART4_TX → DATA OUT (über IEC_CLK_OUT), UART7_RX ← DATA IN (IEC_DATA_IN, RXINV wegen LVC14), COMMAND = IEC_ATN_OUT – nur Firmware + DIN-6→SIO-13-Kabel, keine Platinenänderung |
| SWDIO / SWCLK / SWO | PA13 / PA14 / PB3 | Debug |
| DBG_TX / DBG_RX | PD8 / PD9 | USART3 (AF7) |
| LED_ACT / FDD / USB / ERR | PG0–PG3 | High = an |
| PWR_SRC | PG4 | TPS2116 Status |
| HSE | PH0 / PH1 | 25 MHz |

### Firmware (`firmware/`) – an dieses Board angepasst

- Pintabelle + Polarität zentral in `firmware/include/board.h` / `src/board_headless.c`; alle Module nutzen `bus_out()` / `bus_in()` (logisch: true = Busleitung aktiv)
- Flux lesen: RDATA TIM2_CH1 (PA5) + INDEX TIM2_CH2 (PA1), steigende Flanke, gleiche 32-bit-Zeitbasis; DMA (Double-Buffer, 128-KB-Blöcke) schreibt linear in den Flux-Speicher, Umdrehungen sind Ausschnitte (Grenzen exakt per Zeitstempel)
- Flux-Speicher: 8 MB QSPI-PSRAM U11 (`ufi_psram.c`, OCTOSPI1 memory-mapped bei 0x90000000, 68,75 MHz, bis 20 Umdrehungen); antwortet das PSRAM nicht (ID-/Mustertest), Rückfall auf 224 KB AXI-SRAM
- Flux schreiben: WDATA = TIM3_CH1 (PA6), abwärtszählende PWM, ARR per DMA je Flux-Intervall, gleicher 275-MHz-Takt wie beim Lesen, Präkompensation, Schreibschutz-Prüfung
- IEC getrennt OUT (PD0–4) / IN (PF4–8), Protokoll mit Timeouts, EOI und Turnaround nach Butterfield; Amiga J7: Motor per Select-Latch (MTRXD = MOTOR_B, SEL1B = DRV_SEL_B); Apple-Code hinter `BOARD_HAS_APPLE` (hier 0)
- Build: `cmake -S firmware -B firmware/build -G Ninja -DSTM32CUBE_PATH=<STM32Cube_FW_H7_V1.11.0>` + `cmake --build firmware/build` → 0 Fehler, 0 Warnungen (Compiler + Linker, 41 KB Flash). **Auf Hardware ungetestet.**

## Sourcing-Notizen

- LCSC-Nummern: per JLCPCB-API (05.10.2026, Lagerbestand geprüft) zugeordnet, Tabelle `LCSC` in `scripts/build_schematic.py`. Extended-Teile kosten bei JLC je ~3 $ Rüstgebühr; Spule SRN6045TA-150M (C1330797) hatte nur 189 Stück Lager
- Quarz: YXC X322525MOB4SI (C9006, Basic), 25 MHz, CL 12 pF → Lastkondensatoren 2× 18 pF C0G (C1647); gm_crit ≈ 0,97 mA/V < 1,5 mA/V (H723 HSE)
- IEC: Stiftleiste 1×6 (C37208) statt DIN-6 auf der Platine; DIN-6-Buchse sitzt extern (Gehäuse)

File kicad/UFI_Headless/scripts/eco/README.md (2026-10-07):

# ECO-Handwerkzeuge (KiCad-Python, `"C:/Program Files/KiCad/10.0/bin/python.exe"`)

Für das, was Freerouting nach einer ECO offen lässt. Alle arbeiten direkt auf dem Board; vorher eine Kopie ziehen.
Netznamen mit `/` (z. B. `/MCU_Core/SD_D3`) unter Git Bash mit `MSYS_NO_PATHCONV=1` und Windows-Pfaden aufrufen.

| Skript | Zweck |
|---|---|
| `net_clusters.py board NET` | zusammenhängende Pad-Gruppen eines Netzes (Zonen werden vorher gefüllt) |
| `occupancy.py board` | ASCII-Belegungskarte 1 mm (Courtyards, Leiterbahndichte) – freien Platz finden |
| `free_map.py board NET W LAYER x0 y0 x1 y1 [step]` | wo eine Bahn der Breite W verlaufen darf (`.` frei, `v` Via passt, `+` eigenes Kupfer) |
| `maze_route.py board NET W x0 y0 x1 y1 sx,sy,L tx,ty,L [step] [via_cost]` | A*-Router F/In2/B für eine Verbindung, keine Vias in Pads; gibt eine Punktliste für `route_try.py` aus |
| `route_try.py board NET W check\|apply x,y,L ...` | Polylinie prüfen/einsetzen, Via bei Lagenwechsel (`L` = F, I2, B) |
| `via_scan.py board NET x0 y0 x1 y1` | freie Via-Punkte auf den F.Cu-Bahnen eines Netzes |
| `who_blocks.py board NET LAYER x y r` | welches Fremdkupfer einen Punkt blockiert |
| `copy_tracks.py old new NET x0 y0 x1 y1 check\|apply` | Bahnen eines Netzes aus einem früheren Board übernehmen (z. B. Versorgung nach einer ECO) |
| `drop_seg.py`, `drop_box.py`, `renet_box.py`, `move_fp.py` | Segmente/Bereiche löschen, Kupfer umnetzen, Bauteil versetzen und darunter freiräumen |
| `remove_part.py board REF[,REF] [NET ...]` | im Schaltplan entfernte Bauteile vom Board nehmen und Netze komplett aufreißen (vor `make_pcb.sh eco`) |
| `set_value.py board REF VALUE [FELD=WERT ...]` | geänderten Bauteilwert ins Layout übernehmen (Schaltplan-Parität) |
| `hide_ref.py board REF [REF ...]` | Referenz kleiner Bauteile im Bestückungsdruck ausblenden (Platzmangel), F.Fab behält sie |
| `extend_outline.py board Y_FROM DY [SRC:NEU:x:y ...]` | Platine nach unten verlängern: Umriss und flächige Ebenen unterhalb Y_FROM um DY schieben, Befestigungslöcher kopieren (v0.7: `80 12 H3:H5:3.5:93.5 H4:H6:106.5:93.5`) |
| `probe_region.py board x0 y0 x1 y1` | Courtyards und Kupfer in einem Fenster auflisten |
| `check_via_in_pad.py board` | Vias, die ein SMD-Pad berühren (muss 0 sein) |

Abstand: `ROUTE_CLR` (mm, Standard 0.2; Regel ist 0.15 – an 0,5-mm-QFP-Pads mit 0.15 routen, die DRC prüft danach).
Nach Handrouten: `scripts/route.py import <board> none` (Zonen füllen), `scripts/finish_pcb.py` (Insel-Vias), DRC.

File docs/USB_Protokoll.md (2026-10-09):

# USB-Protokoll der UFI Flux Engine (UFI Headless)

Stand: Firmware 1.12, Board v0.7. Alle Mehrbyte-Werte **little endian**.

## 1 USB-Personalitäten

| Modus | VID:PID | Produktname | Klasse | Auswahl |
|---|---|---|---|---|
| UFI-Flux | 1209:4F54 | UFI Flux Engine | CDC (virtueller COM-Port) | Schalter J13 Mitte, `UFI.CFG protocol=ufi` (Standard) |
| Greaseweazle | 1209:4F57 | UFI Flux Engine (gw-compat) | CDC | Schalter Mitte, `UFI.CFG protocol=gw` |
| SD-Laufwerk | 1209:4F55 | UFI Flux Storage | Mass Storage | Schalter Pin 3, Taster B ≥ 2 s, Befehl `USB_MODE 1` |
| USB-Floppy | 1209:4F56 | UFI USB Floppy | Mass Storage | Schalter Pin 1, Befehl `USB_MODE 2` |

Nach jedem Wechsel meldet sich das Gerät neu an (ca. 200 ms getrennt). ACT blinkt die Betriebsart: 1× Flux, 2× SD, 3× Floppy, 4× Greaseweazle. Die Baudrate des COM-Ports ist bedeutungslos, außer **10000 Baud = Kanal zurücksetzen** (Greaseweazle-Konvention, gilt auch für UFI v2).

Im UFI-Flux-Modus versteht das Gerät zwei Protokolle: das alte **UFI v1** (ein Befehl je USB-Paket, siehe `software/ufi_host/README.md`) und **UFI v2** (Abschnitt 3). Ein USB-Paket, das mit `0x55 0xAA` beginnt (also der erste v2-Rahmen in einem Schreibaufruf; nicht innerhalb laufender v1-Schreibdaten), schaltet die Sitzung auf v2 um; sie bleibt v2 bis zum Kanal-Reset (10000 Baud) oder zur Neuanmeldung. Neue Software sollte nur v2 benutzen.

---

## 2 Greaseweazle-Modus (`protocol=gw`)

Unabhängige Umsetzung des Greaseweazle-Protokolls (Keir Fraser, `cdc_acm_protocol.h`, public domain). Die Greaseweazle-Werkzeuge (`gw info`, `gw read`, `gw write`, `gw erase`, `gw seek`, `gw delays`, `gw reset`) erkennen das Gerät am Produktnamen „gw-compat“ auch ohne `--device`.

### 2.1 Rahmen
- Befehl: `[cmd, len, args…]`, `len` = Gesamtlänge inkl. der zwei Kopfbytes. Befehle dürfen beliebig über USB-Pakete verteilt sein; nicht pipelinen.
- Antwort: `[cmd, ack]` + befehlsabhängige Daten. `ack` 0 = OK.
- Kanal-Reset: SET_LINE_CODING mit 10000 Baud verwirft Teilbefehle und bricht einen laufenden Lesevorgang ab.

| ack | Bedeutung |
|---|---|
| 0 | OK |
| 1 | unbekannter/ungültiger Befehl |
| 2 | kein Indeximpuls |
| 3 | Spur 0 nicht gefunden |
| 4 | Flux-Überlauf (Lesen) |
| 5 | Flux-Unterlauf (Schreiben) |
| 6 | schreibgeschützt (Diskette oder WRITE-LOCK-Jumper) |
| 7 | kein Laufwerk angewählt |
| 8 | kein Bus-Typ gesetzt |
| 9 | ungültige Laufwerksnummer |
| 10 | ungültiger Pin |
| 11 | ungültiger Zylinder |
| 12 | Speicher voll |

### 2.2 Befehle

| Code | Name | Argumente | Antwortdaten |
|---|---|---|---|
| 0 | GET_INFO | `idx` u8 | 32 Byte (siehe unten) |
| 2 | SEEK | `cyl` s8 oder s16 | – (Zylinder 0…83, negativ = ungültig) |
| 3 | HEAD | `head` u8 (0/1) | – |
| 4 | SET_PARAMS | `idx`=0, bis 8 × u16 | – |
| 5 | GET_PARAMS | `idx`=0, `n` u8 | `n` Byte |
| 6 | MOTOR | `unit` u8, `on` u8 | – |
| 7 | READ_FLUX | `ticks` u32, `max_index` u16, [`linger` u32] | Flussdaten bis Byte 0 |
| 8 | WRITE_FLUX | `cue_at_index` u8, `terminate_at_index` u8, [`hard_sector_ticks` u32 = 0] | nach den Daten: 1 Statusbyte |
| 9 | GET_FLUX_STATUS | – | (Status steht im ack) |
| 12 | SELECT | `unit` u8 | – |
| 13 | DESELECT | – | – |
| 14 | SET_BUS_TYPE | 0 keiner, 1 IBM-PC, 2 Shugart | – |
| 15 | SET_PIN | `pin` u8 (nur 2 = DENSITY), `level` u8 | – |
| 16 | RESET | – | – (Einschaltzustand) |
| 17 | ERASE_FLUX | `ticks` u32 | nach dem Löschen: 1 Statusbyte |
| 20 | GET_PIN | `pin` u8 (8 INDEX, 26 TRK0, 28 WRPROT, 34 DSKCHG/READY) | `level` u8 (0 = low = aktiv) |

Nicht unterstützt (ack 1): 1 UPDATE, 11 SWITCH_FW_MODE, 18/19 SOURCE/SINK_BYTES (`gw bandwidth`), 21 TEST_MODE, 22 NOCLICK_STEP (Flippy).

**GET_INFO idx 0:** `fw_major, fw_minor` (= UFI-Firmware, z. B. 1.12), `is_main=1`, `max_cmd=22`, `sample_freq` u32 = **68 750 000**, `hw_model=0x55`, `hw_submodel=1` (gw zeigt „Unknown (0x5501)“), `usb_speed=0` (Full Speed), `mcu_id=0`, `mcu_mhz` u16 = 550, `sram_kb` u16 = 564, `usb_buf_kb` u16 = 8, Rest 0. **idx 1:** Bandbreite (fester Nennwert). **idx 7 / 8+n:** Laufwerk aktuell / Einheit n: `flags` u32 (Bit0 Zylinder gültig, Bit1 Motor an), `cyl` s32.

**Bus/Einheiten:** IBM-PC: 0 = Laufwerk A, 1 = B (Kabel mit Twist). Shugart: 0–3 = DS0–DS3 (gerades Kabel, DS3 nur mit JP1). Amiga-Port, IEC und Apple-Port sind im Greaseweazle-Modus nicht erreichbar.

**Parameter (idx 0, je u16):** select_delay µs, step_delay µs, seek_settle ms, motor_delay ms, watchdog ms (Standard 10000: ohne Befehl Motoren aus, abwählen), pre_write µs, post_write µs, index_mask µs (die letzten drei werden gespeichert, nicht ausgewertet).

### 2.3 Flusscode (Abtastrate 68,75 MHz = 275 MHz / 4)
| Bytes | Bedeutung |
|---|---|
| `1…249` | Flusswechsel, Abstand = Wert |
| `250…254, b` | Abstand = 250 + (Wert − 250) × 255 + b − 1 |
| `0xFF 1 N28` | Indeximpuls, N = Ticks ab dem letzten Wechsel (Cursor unverändert) |
| `0xFF 2 N28` | Lücke: N Ticks zum nächsten Wechsel addieren |
| `0xFF 3 N28` | (nur Schreiben) Lücke vorher mit Wechseln im Abstand N füllen |
| `0` | Ende des Datenstroms |

N28 = 4 Byte: `1|(N<<1)`, `1|(N>>6)`, `1|(N>>13)`, `1|(N>>20)`.

Lesen liefert `max_index − 1` volle Umdrehungen ab einem Indeximpuls (der erste Impuls kommt als Index mit N = 0). Schreiben beginnt immer am Index und endet am nächsten; die Vorkompensation macht `gw` selbst.

---

## 3 UFI v2

### 3.1 Rahmen (beide Richtungen)

```
Offset 0  0x55
       1  0xAA
       2  type     1 = Anfrage (Host)   2 = Antwort   3 = Ereignis   4 = Daten   5 = Ende
       3  cmd      Befehlscode (Antwort/Daten/Ende tragen den Code der Anfrage)
       4  seq      Laufnummer: Antwort/Daten/Ende wiederholen die seq der Anfrage; Ereignisse zählen selbst
       5  status   Anfrage: 0; sonst Statuscode (3.3)
       6  len      u16, Länge der Nutzdaten (0…4096)
       8  payload  len Byte
   8+len  crc      u16, CRC-16/CCITT-FALSE (Polynom 0x1021, Start 0xFFFF) über Byte 2 … 7+len
```

- Rahmen sind unabhängig von USB-Paketgrenzen. Der Empfänger sucht `55 AA`, liest den Kopf und prüft die CRC; bei Fehler verwirft er bis zum nächsten `55 AA`.
- Fehlerhafte Anfrage (CRC, Länge): Antwort `type=2, cmd=0xFF, seq=0, status=14`.
- Pro Anfrage genau **eine Antwort**. Lang laufende Befehle (Lesen, Schreiben) antworten sofort mit dem Annahmestatus und schließen mit einem **Ende-Rahmen** (type 5) ab; dazwischen kommen **Daten-Rahmen** (type 4).
- Flusskontrolle: Das Gerät hält den USB-Endpunkt an, wenn sein Empfangspuffer voll ist (NAK) – der Host schreibt einfach weiter.
- Ereignisse (type 3) kommen nur nach `EVENTS` und nie mitten in einem Rahmen.

### 3.2 Befehle

Laufwerksnummern (`drive`): 0 keins, 1 A, 2 B (PC-Kabel mit Twist), 3 apple (J14), 4 amiga (J7 DF1), 5 iec, 6–9 ds0–ds3 (Shugart), 10 amiga2 (J7 DF2, JP3), 11 apple2 (J15). Spuren immer physisch.

| Code | Name | Anfrage | Antwort-Nutzdaten |
|---|---|---|---|
| **System** | | | |
| 0x00 | PING | beliebig | dieselben Bytes |
| 0x01 | INFO | – | `proto` u8 = 2, `fw_major` u8, `fw_minor` u8, `board_rev` u8 (5/6/7, 0 = unbekannt), `caps` u32, `sample_hz` u32 = 275 000 000, `store_bytes` u32, `max_payload` u16 = 4096, dann ASCII-Text (Firmware, Git-Rev., Datum, PSRAM-Test) |
| 0x02 | STATUS | – | `drive, motor, wprot, track0, disk_changed, ready, track, side` (je u8), dann `board_status` (8 Byte, wie v1 0x1B) |
| 0x03 | RESET | – | Antwort, danach Neustart |
| 0x04 | BOOTLOADER | – | Antwort, danach ROM-DFU |
| 0x05 | USB_MODE | `mode` u8 (0 Flux, 1 SD-Laufwerk, 2 USB-Floppy, 3 Greaseweazle) | Antwort, danach Neuanmeldung |
| 0x06 | EVENTS | `mask` u32 (Bits = Ereigniscodes − 0x80) | – |
| **Laufwerk** | | | |
| 0x10 | SELECT | `drive` u8 | – |
| 0x11 | MOTOR | `on` u8 | – (wartet die Anlaufzeit ab) |
| 0x12 | SEEK | `track` u8 [, `quarter` u8 0–3 (Apple-Viertelspur, 1.14)] | – |
| 0x13 | RECAL | – | – |
| 0x14 | SIDE | `side` u8 | – |
| 0x15 | TIMING | – oder 10 × u16 (wie v1 0x17) | aktuelle 10 × u16 |
| 0x16 | LINES | `density` u8, `drate` u8 | – |
| 0x17 | CHECK_DISK | – | `changed` u8, `present` u8 |
| 0x18 | PROBE_TRACKS | – | höchste erreichbare Spur u8 |
| 0x19 | SEEK_TEST | `a` u8, `b` u8, `cycles` u8 | – |
| 0x1A | AMIGA_ID | – | ID u32 |
| 0x1B | DIAG_RPM (1.13) | `revs` u8 (0 = 5, max 50) | `revs` u8, `period_min` u32, `period_avg` u32, `period_max` u32, `pulse` u32 (Ticks 275 MHz), `rpm_x100` u16 |
| 0x1C | DRIVE_SCAN (1.13) | `flags` u8 (Bit0 = Shugart-Bus DS0–DS3 statt a/b/amiga/amiga2) | 4 × (`drive` u8, `found` u8: Bit0 TRK0 gefunden, Bit1 Indeximpulse, Bit2 schreibgeschützt) |
| 0x1D | INDEX_SIM (1.13) | – (Abfrage) oder `rpm` u16 (0 = aus, 200–400), `pulse_us` u16 (0 = 2000), `mode` u8 (1.14: Bit0 Ausgang J9 Pin 6, Bit1 intern; 0 = Bit0) | `rpm` u16, `mode` u8 (1.14) aktueller Zustand |
| 0x1E | SET_RPM (1.14) | – (Abfrage) oder `rpm` u16 (300/360, 0 = Abfrage) | `rpm` u16 (0 = nicht gesetzt), `line` u8 (0 keine, 1 DENSITY, 2 DRATE) |
| 0x25 | ANALYZE (1.14) | `track, side` u8, `revs` u8 (0 = 3, max 8) | `revs` u8, `encoding` u8 (0 ?, 1 FM, 2 MFM, 3 GCR), `bitcell_ns` u16, `rpm_x100` u16, `peak_ns` 4 × u16, `index_ticks` u32, `transitions` u32, `bitcells` u32, `sectors` u8, `weak_count` u8, `first_sector_us` u32, `weak_mask` u64 (40 Byte) |
| 0x1F | STEP_SCHEDULE (1.14) | `flags` u8 (Bit0 Positionen in Viertelspuren), `n` u8 (≤ 32), n × (`at_ms` u16, `pos` u8) | – |
| **Fluss** | | | |
| 0x20 | READ | `track, side, revs` u8, `flags` u8 (Bit0 ohne Index, Bit1 hartsektoriert, Bit2 `track` in Viertelspuren), `period_ms` u16, bei Bit1 `sectors` u8 (1.14) | Annahme; dann Daten-Rahmen, Ende-Rahmen mit `revs` u8 |
| 0x21 | ABORT | – | – (bricht Lesen/Schreiben ab; der laufende Vorgang endet mit Ende-Rahmen Status 4) |
| 0x22 | WRITE | `track, side` u8, `flags` u8 (Bit0 Prüflesen, Bit1 hartsektoriert, Bit2 `track` in Viertelspuren), `flux_count` u32, `byte_count` u32, bei Bit1 `sectors` u8 (1.14) | Annahme; dann sendet der Host Daten-Rahmen (type 4, cmd 0x22) mit zusammen `byte_count` Byte; Ende-Rahmen nach dem Schreiben |
| 0x23 | ERASE | `track, side` u8 | – (eine Umdrehung) |
| 0x24 | PATTERN | `track, side` u8, `interval_ns` u16, `duration_ms` u16 | – |
| **Commodore IEC** | | | |
| 0x30 | IEC_RESET | – | – |
| 0x31 | IEC_SEND | `byte` u8, `eoi` u8 | – |
| 0x32 | IEC_RECV | – | `byte` u8, `eoi` u8 |
| 0x33 | IEC_MEM (1.14) | `op` u8 (0 M-W, 1 M-R, 2 M-E, 3 DOS-Befehl), `addr` u16, dann Daten (M-W ≤ 32 Byte, DOS-Befehl: Text) bzw. `n` u8 (M-R) | M-R: `n` Byte |
| 0x34 | IEC_NIB (1.14) | `halftrack` u8 (2–84), `sync` u8, `mode` u8 (0 Stück ab Sync, 1 roh, 2 nur positionieren), `flags` u8 (Bit0 Laufwerkscode neu laden, Bit1 Stepper-Richtung umgekehrt), `device` u8 (0 = `iec_device`) | `status` u8 (0 ok, 1 kein Sync/keine Bytes, 2 Ursprung nicht gefunden, 3 roh), `synclen` u8 (≈ 11 µs), `maxlen` u16, `halftrack` u8, 512 Rohbytes |
| **Board** | | | |
| 0x40 | POWER | – oder `mask` u8 (Bit0 FDD_5V, Bit1 FDD_12V) | `board_status` 8 Byte |
| 0x41 | USB_POWER | – | `cc1_mv` u16, `cc2_mv` u16, `current_ma` u16 |
| 0x42 | SD_INFO | – | `present, status, card_type, bus_width` u8, `capacity_mb` u32 |
| **Dateien (SD-NAND, FAT32)** | | | |
| 0x50 | DIR | `start` u16, Pfad (ASCII, leer = Wurzel) | `count` u8, `more` u8, dann je Eintrag `size` u32, `attr` u8 (0x10 = Ordner), `nlen` u8, Name |
| 0x51 | READ_FILE | `offset` u32, `len` u16 (≤ 4096), Name | Dateiinhalt (kürzer am Dateiende) |
| 0x52 | WRITE_FILE | `offset` u32, `flags` u8 (Bit0 neu anlegen/kürzen), `nlen` u8, Name, Daten | geschriebene Bytes u16 |
| 0x53 | DELETE | Name | – |
| 0x54 | CFG_RELOAD | – | – (UFI.CFG neu einlesen) |
| **Ohne PC** | | | |
| 0x60 | DUMP_START | – oder `drive, tracks, sides, revs` u8 | – |
| 0x61 | DUMP_STATUS | – | `state, error, track, side` u8, `file_no` u16, `fs_result` u8, `storage_ready` u8 |
| 0x62 | DUMP_ABORT | – | – |
| 0x63 | COPY_START | – | – |

**caps (INFO):** Bit0 PSRAM ok, Bit1 SD-NAND bereit, Bit2 IEC, Bit3 Amiga, Bit4 Amiga2/JP3-fähig (v0.7), Bit5 Shugart-Bus, Bit6 Apple-Port (v0.7), Bit7 Sync-Sensor aktiviert (`apple_sync=1`), Bit8 Greaseweazle-Modus verfügbar, Bit9 Dateizugriff, Bit10 Ereignisse, Bit11 Laufwerksdiagnose und Indexsimulation (DIAG_RPM, DRIVE_SCAN, INDEX_SIM; Firmware 1.13).

**Beschäftigt (Status 1):** Während eines Dumps/einer Kopie werden nur PING, INFO, STATUS, EVENTS, POWER, USB_POWER, SD_INFO, DUMP_STATUS und DUMP_ABORT ausgeführt; während READ/WRITE (bis zum Ende-Rahmen) werden Laufwerks- und Flussbefehle (0x10–0x1C, 0x1E, 0x20, 0x22–0x24, DUMP_START, COPY_START) abgewiesen; INDEX_SIM (0x1D) ist jederzeit erlaubt. WRITE wartet höchstens 1 s auf den Indeximpuls (sonst Ende-Status 4); schlägt das Positionieren vor dem Schreiben fehl, endet WRITE mit Status 3.

### 3.3 Statuscodes

| Status | Bedeutung |
|---|---|
| 0 | OK |
| 1 | beschäftigt (Dump läuft, Vorgang aktiv) |
| 2 | kein Laufwerk angewählt / Laufwerk fehlt |
| 3 | Positionieren fehlgeschlagen (Spur 0) |
| 4 | kein Indeximpuls / abgebrochen |
| 5 | Zeitüberschreitung |
| 6 | DMA-/Prüflese-Fehler |
| 7 | USB-Fehler |
| 8 | IEC: kein Gerät |
| 9 | IEC: keine Quittung |
| 10 | Puffer voll / Überlauf |
| 11 | nicht unterstützt (auf diesem Board) |
| 12 | schreibgeschützt |
| 13 | Speicher (SD-NAND/Dateisystem) |
| 14 | Rahmenfehler (CRC/Länge) |
| 15 | unbekannter Befehl |
| 16 | ungültige Argumente |
| 17 | Datei nicht gefunden |

### 3.4 Flusscode (READ-Daten, WRITE-Daten), 275 MHz
Gleich dem v1-Stream (`ufi_stream.c`): Zeit 0 = erster Indeximpuls (bzw. Start ohne Index).

| Bytes | Bedeutung |
|---|---|
| `01…EF` | Flusswechsel, Abstand = Wert (Ticks à 3,64 ns) |
| `F0…FC b` | Abstand = 240 + ((Wert − 0xF0) << 8) + b |
| `FD u32` | Indeximpuls, u32 = Ticks nach dem letzten Wechsel (nur Lesen) |
| `FE u32` | Abstand = u32 |
| `00`, `FF` | reserviert |

Lesen endet nach `revs` Indeximpulsen (bzw. Zeitabschnitten); der Ende-Rahmen meldet die Zahl der gesendeten vollen Umdrehungen. Ohne Index (Apple ohne Sync-Sensor, `flags` Bit0) markieren `FD`-Einträge die Abschnittsgrenzen (`period_ms`, 0 = 200 ms).

**Apple mit Sync-Sensor** (J19, Hall-Sensor nach Applesauce-Art, `UFI.CFG apple_sync=1`, caps Bit7): Der Sensor liegt auf der INDEX-Leitung; READ liefert dann echte Umdrehungen ab dem Sensorimpuls (`FD` = Sensorimpuls), WRITE beginnt am Sensorimpuls – Spuren bleiben zueinander ausgerichtet. Ohne `apple_sync=1` arbeitet das Apple-Laufwerk mit Zeitabschnitten, auch wenn ein Sensor steckt.

### 3.5 Ereignisse (type 3, nach EVENTS)

| cmd | Ereignis | Nutzdaten |
|---|---|---|
| 0x80 | Diskette gewechselt | `drive` u8 |
| 0x81 | Taster | `button` u8 (0 A, 1 B), `long` u8 |
| 0x82 | Dump/Kopie-Fortschritt | wie DUMP_STATUS |
| 0x83 | Laufwerksversorgung abgeschaltet (Überstrom) | `board_status` |
| 0x84 | Betriebsart-Schalter bewegt | neuer `mode` u8 (vor der Neuanmeldung) |

### 3.6 Festlegungen im Detail

- **seq:** Der Host nummeriert Anfragen 1…255 (danach wieder 1); 0 ist der Rahmenfehler-Antwort vorbehalten. Höchstens **eine Anfrage gleichzeitig** offen. Ereignisse zählen ihre eigene seq ab 0 (Überlauf 255 → 0).
- **Zeitüberschreitung:** Kommt eine Antwort nicht (z. B. wegen CRC-Fehler verworfen), wartet der Host 1 s (Lesen/Schreiben: bis zum Ende-Rahmen, Zeitlimit großzügig) und setzt dann den Kanal zurück (10000 Baud). Eine Antwort mit `cmd=0xFF, seq=0, status=14` gehört zur gerade offenen Anfrage.
- **INFO:** `store_bytes` = Größe des Flussspeichers (8 MB PSRAM, sonst interner Ersatzpuffer), nicht der SD-NAND (dafür SD_INFO). Der Text danach ist ASCII, Zeilen durch `\n` getrennt, ohne abschließendes Nullbyte.
- **board_status (8 Byte):** `power` u8 (Bit0 FDD_5V an, Bit1 FDD_12V an), `flags` u8 (Bit0 WRITE-LOCK gesteckt, Bit1/2 Überstrom 5 V/12 V ausgelöst, Bit3 SD-NAND bereit, Bit4/5 Taster A/B gedrückt, Bit6 Sicherheitsmodus), `i5_ma` u16, `i12_ma` u16, `board_id_mv` u16.
- **READ:** `revs` 1…200. Der Ende-Rahmen ist maßgeblich: Nur so viele Umdrehungen gelten, wie er meldet (bei Überlauf können `FD`-Marken fehlen oder überzählig sein). Ende-Status 4 = kein Index **oder** per ABORT abgebrochen; 10 = Überlauf (Host las zu langsam).
- **WRITE:** Der Host wartet die Annahme-Antwort ab und sendet erst dann die Daten-Rahmen (je ≤ 4096 Byte Nutzdaten, beliebig aufgeteilt, zusammen genau `byte_count`). Ende-Status: 0 OK, 12 schreibgeschützt, 4 kein Index (Laufwerk mit Index), 6 Prüflesen fehlgeschlagen (`flags` Bit0), 10 Daten fehlerhaft/zu viele Wechsel.
- **Dateinamen:** FAT 8.3 (keine langen Namen), Großbuchstaben, Pfadtrenner `/` erlaubt (z. B. `DUMPS/DUMP0001.SCP`), höchstens 64 Zeichen.
- **READ_FILE:** Weniger Bytes als angefordert (auch 0) = Dateiende.
- **WRITE_FILE:** `flags` Bit0 legt die Datei neu an bzw. kürzt sie auf 0 (auch mit 0 Datenbytes). Weniger geschriebene als gesendete Bytes = Speicher voll; die Antwort trägt dann Status 13.
- **EVENTS:** Unbekannte Bits in `mask` werden ignoriert; `mask = 0` schaltet alle Ereignisse ab.
- **DUMP_START:** Nutzdaten leer (Werte aus UFI.CFG) oder genau 4 Byte.
- **UFI.CFG:** Textdatei, Zeilen `schlüssel=wert` (Schlüssel klein), `#` beginnt einen Kommentar, CRLF; unbekannte Schlüssel werden ignoriert. Schlüssel: `drive, tracks, sides, revs, button_a, copy_from, copy_to, protocol, apple_sync, index_sim, index_sim_mode` (`index_sim=300|360` schaltet die Indexsimulation beim Start ein, 1.13; `index_sim_mode=pin|internal|both`, 1.14), `rpm_line, rpm_360, rpm` (3-Mode-Laufwerke, 1.14), `iec_device`, `track_search` (1.14); `tracks=0` = automatisch.
- **IEC_NIB (1.14, 1541-Rohspuren):** Die Firmware lädt beim ersten Aufruf (oder mit Bit0) ein 6502-Programm (`firmware/tools/iec_nib.s`, 6 + 32 Byte je M-W) nach $0310 im Laufwerk, schreibt die Parameter nach $0300 (Halbspur, Sync-Index, Modus, Phasenrichtung), startet es mit M-E und wartet bis zu 6 s, bis das Laufwerk wieder auf ATN antwortet (es läuft mit gesperrten Interrupts). Das Programm fährt den Kopf in Halbschritten (eigener Positionszähler $0308, den der Host nach der Kalibrierung setzt; 0 = nicht bewegen), setzt die Dichte-Bits der Spur, sucht den Spurursprung (Sync nach der längsten Strecke ohne Sync, also der Header-Sync von Sektor 0), überspringt `sync` Syncs, misst die Sync-Länge und liest 512 Bytes; während eines Syncs liefert es je Bytezeit ein $FF, Syncs erscheinen also als $FF-Folgen mit ungefährer Länge. Modus 1 liest 512 Bytes ohne Bezug (unformatierte Spuren), Modus 2 positioniert nur. Die Antwort kommt aus $0304 (Status, Sync-Länge, längste Strecke, Zähler) und $0600–$07FF; $0700 ist der BAM-Puffer des DOS, der Host sendet zum Schluss `I0`. Das Zusammensetzen der Stücke (alle 2 Syncs eines, Ausrichtung an den $FF-Folgen, Ende beim Wiederauftauchen des Ursprungs) und die G64-Ausgabe macht `ufi iec-nib`; Dauer etwa 10–20 s je Spur. Kein Bitzellen-Timing, schwache Bits nur über Mehrfachlesen.
- **IEC-Dump (1.14):** DUMP_START mit `drive` = 5 (iec), per UFI.CFG `drive=iec` oder Taster A, liest eine 1541/1571-Diskette über den Laufwerkscontroller (Kanal 2 „#“, `U1`-Blocklesen, Gerät `iec_device`, Standard 8) nach `DUMPnnnn.D64`: `tracks` 35 (683 Blöcke, 174 848 Byte) oder 40 (768 Blöcke); andere Werte gelten als 35, `sides`/`revs` werden ignoriert. Nicht lesbare Blöcke stehen als Nullen in der Datei und mit Spur/Sektor in `DUMPnnnn.LOG`. DUMP_STATUS meldet in `track` die 1541-Spur (1–40), `side` 0. Dauer einige Minuten (seriell, etwa 0,3–0,6 s je Block); Abbruch wie gewohnt (DUMP_ABORT, Taster B). Kein Flux: Kopierschutz und schwache Bits sind so nicht erfassbar.
- **ANALYZE (1.14):** liest `revs` Umdrehungen blockierend (kein Datenstrom, bis 4 s) und wertet aus: Umdrehungszeit/Drehzahl, Flusswechsel, Histogramm der Abstände in 100-ns-Klassen mit bis zu vier Spitzen (lokale Maxima über 2 % der Wechsel), daraus Kodierung und Bitzelle: Verhältnis 1:1,5 (4/6/8 µs) = MFM bzw. an Apple-Laufwerken GCR, Bitzelle = halbe erste Spitze; 1:2 mit dritter Spitze ≈ 3 = C64-GCR, Bitzelle = erste Spitze; 1:2 ohne = FM, Bitzelle = doppelte erste Spitze. `bitcells` = Umdrehungszeit / Bitzelle (Long-Track-Erkennung). Schwache Bits: die Umdrehung wird in 64 Zeitfenster geteilt; weicht die Zahl der Flusswechsel eines Fensters zwischen den Umdrehungen um ≥ 3 ab, gilt es als schwach (`weak_mask` Bit w). Für MFM werden die Sektoren von Umdrehung 0 dekodiert (`sectors` = gültige CRC) und die Zeit vom Index bis zur ersten gültigen Sektor-ID gemeldet (Spurausrichtung, radialer Versatz des Laufwerks). Status 2 ohne Laufwerk, 4 ohne Index, 5 bei Zeitüberschreitung. `ufi analyze 0 0 -r 5`.
- **Dump (1.14):** `tracks=0` ermittelt vor dem Dump die höchste erreichbare Spur (PROBE_TRACKS) und liest bis dahin (max. 84); `UFI.CFG track_search=1` liest bei `double_step` (40-Spur-Diskette im 80-Spur-Laufwerk) eine schwache Spur zusätzlich eine physische Spur weiter außen und innen und behält die beste Position.
- **STEP_SCHEDULE (1.14, Spiradisc-artige Spuren):** Kopfbewegungen während des nächsten READ oder WRITE: `at_ms` zählt ab dem Startereignis der Operation (Indeximpuls, der Umdrehung 0 bzw. das Schreiben beginnt; ohne Index der Beginn der Aufnahme), `pos` ist die Zielposition in Spuren oder, mit Bit0, in Viertelspuren (Spur × 4 + Viertel, Apple). Die Einträge müssen zeitlich geordnet sein (sonst Status 16), die Hauptschleife führt sie bei Fälligkeit mit dem normalen Positionieren aus (Shugart: Schritt + Einschwingzeit, Apple: Phasen; Genauigkeit etwa 1–2 ms, die Aufnahme läuft dabei weiter). Der Plan gilt einmalig für die nächste Operation und verfällt, wenn sie vorher endet. `ufi read 17 0 --steps 50:17.1,100:17.2,150:17.3`.
- **SET_RPM (1.14, 3-Mode-Laufwerke mit 300/360 U/min):** Die Firmware schaltet die in `UFI.CFG rpm_line=density|drate` gewählte Busleitung (DENSITY = Pin 2, DRATE = Pin 6 über JP1 – dort auch DS3 des Shugart-Busses) auf den Pegel, der laut `rpm_360=low|high` 360 U/min bedeutet (Laufwerksjumper beachten), und wartet bei laufendem Motor die Hochlaufzeit (`spinup_ms`) ab. Ohne konfigurierte Leitung Status 11, andere Werte als 300/360 Status 16; die Antwort enthält immer den aktuellen Zustand. `rpm=300|360` setzt die Drehzahl beim Start. Mit `rpm_line=density` überschreibt LINES (0x16) die Wahl. Kontrolle mit DIAG_RPM.
- **Hartsektoriert (READ/WRITE Bit1, 1.14):** `sectors` = Zahl der Sektorlöcher (10, 16, 32; ≥ 2, sonst Status 16, ebenso ohne das Byte). Die Firmware zählt alle Löcher auf INDEX und nimmt nur das Indexloch als Index: den Impuls, der nach weniger als ¾ des vorigen Abstands kommt (das Indexloch liegt in der Mitte zwischen zwei Sektorlöchern; das folgende Sektorloch hat denselben kurzen Abstand, davor war der Abstand aber bereits kurz). Umdrehungen und `FD`-Marken zählen also von Indexloch zu Indexloch, WRITE beginnt und endet am Indexloch. Bis zur Erkennung vergehen bis zu einer Umdrehung plus zwei Löcher; die Einstellung gilt nur für den jeweiligen Befehl (Dump, Kopie und Greaseweazle-Modus arbeiten weichsektoriert).
- **Viertelspuren (Apple Disk II, 1.14):** SEEK mit `quarter` 1–3 bzw. READ/WRITE mit Bit2 (`track` = Spur × 4 + Viertel, 0–156) setzen den Kopf zwischen die Halbspuren: gerade Viertel = eine Phase, ungerade Viertel = beide Nachbarphasen gleichzeitig bestromt (bleiben bis zum nächsten Positionieren an). Bei anderen Laufwerken antwortet die Firmware mit Status 16; Spur × 4 + Viertel > 156 mit Status 3. Nach Abwahl des Laufwerks (Phasen stromlos) gilt eine Viertelposition als unbekannt, der nächste Seek rekalibriert. STATUS meldet weiterhin die ganze Spur. Kopierschutz-Spuren (z. B. Spur 17,5) liest man mit `ufi read 17 0 --quarter 2`.
- **DIAG_RPM (1.13):** misst am gewählten Laufwerk `revs` Umdrehungen über die INDEX-Leitung (Motor wird gestartet und läuft weiter); Status 2 ohne Laufwerk oder bei IEC, Status 4 ohne Indeximpuls (auch Apple ohne `apple_sync=1`), Status 5 bei Abbruch der Impulsfolge. `rpm_x100` = 6000 × 275 000 000 / `period_avg`, gerundet; `pulse` ist die mittlere Impulsbreite (Low-Zeit auf dem Kabel).
- **DRIVE_SCAN (1.13):** wählt nacheinander jedes der vier Laufwerke, startet den Motor, rekalibriert (TRK0 = Laufwerk antwortet), wartet bis 600 ms auf zwei Indeximpulse (= Diskette eingelegt und dreht) und liest den Schreibschutz; anschließend ist wieder das zuvor gewählte Laufwerk aktiv. Dauert bis zu einigen Sekunden je Laufwerk, bewegt die Köpfe.
- **INDEX_SIM (1.13):** Open-Drain-Ausgang auf J9 Pin 6 (PE1) mit `rpm` Impulsen je Minute, Impuls = Low für `pulse_us`. Für Flippy-Disketten: Draht an den Indexsensor-Ausgang eines PC-Laufwerks, das ohne Index nicht schreibt. Derselbe Pin ist die SD-Stellung des Betriebsart-Schalters an J13: steht der Schalter auf SD, antwortet INDEX_SIM mit Status 1; solange die Simulation läuft, wird der Schalter dort als „nicht SD“ gelesen. Die Antwort enthält immer den aktuellen Zustand (auch bei Status 16 für `rpm` außerhalb 200–400, `pulse_us` ≥ halbe Umdrehung oder unbekannte `mode`-Bits). **`mode` Bit1 intern (1.14):** Der Impulsbeginn gilt im Lese- und Schreibpfad als Indeximpuls (READ-Umdrehungen, WRITE-Start und -Ende, ERASE, DIAG_RPM); die INDEX-Leitung des Laufwerks wird solange ignoriert, damit ein über den Draht zurückgespiegelter Impuls nicht doppelt zählt. Ohne Bit0 bleibt J9 Pin 6 Eingang (Betriebsart-Schalter weiter nutzbar). `UFI.CFG index_sim_mode=pin|internal|both`.
- **Nicht in v2:** Selbsttest und Timer-/GPIO-Diagnose gibt es nur in v1; die Drehzahl berechnet der Host aus den Indexabständen eines READ.

### 3.7 Beispiel: Spur lesen

```
Host:  55 AA 01 10 01 00 01 00  01               crc   SELECT drive=1 (A)
Gerät: 55 AA 02 10 01 00 00 00                   crc   OK
Host:  55 AA 01 11 02 00 01 00  01               crc   MOTOR on
Gerät: 55 AA 02 11 02 00 00 00                   crc
Host:  55 AA 01 20 03 00 06 00  00 00 03 00 00 00 crc  READ track 0, side 0, 3 revs
Gerät: 55 AA 02 20 03 00 00 00                   crc   angenommen
Gerät: 55 AA 04 20 03 00 00 10  <4096 Byte Fluss> crc  Daten …
Gerät: 55 AA 05 20 03 00 01 00  03               crc   Ende, 3 Umdrehungen
```

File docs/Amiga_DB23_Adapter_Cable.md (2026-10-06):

# Amiga DB-23 Adapter-Kabel Spezifikation

## Übersicht

Adapterkabel zum Anschluss von Amiga-externen Laufwerken (A1010, A1011, Cumana CAX354) an UFI.

```
┌─────────────────────────────────────────────────────────────────────────────────────────┐
│                                                                                          │
│   UFI Board                              Amiga External Drive                            │
│   ┌─────────────┐                        ┌─────────────────────┐                        │
│   │             │                        │                     │                        │
│   │  J4         │     Adapter-Kabel      │        DB-23        │                        │
│   │  2x12 HDR   │◄────────────────────►│     DB-23 Male      │                        │
│   │             │                        │                     │                        │
│   └─────────────┘                        └─────────────────────┘                        │
│                                                                                          │
└─────────────────────────────────────────────────────────────────────────────────────────┘
```

---

## UFI J4 Pinout (2x12 Header, 2.54mm)

```
                  ┌──────────────────┐
         GND   1  │ ●              ● │  2   +5V
       RDATA   3  │ ●              ● │  4   +5V
        SIDE   5  │ ●              ● │  6   DKCHG
         DIR   7  │ ●              ● │  8   WPROT
        STEP   9  │ ●              ● │  10  TRK0
        WDAT  11  │ ●              ● │  12  WGATE
       INDEX  13  │ ●              ● │  14  READY
         SEL  15  │ ●              ● │  16  DKRD
        MTRX  17  │ ●              ● │  18  /SEL1
         GND  19  │ ●              ● │  20  GND
         +5V  21  │ ●              ● │  22  +5V
        N.C.  23  │ ●              ● │  24  +12V
                  └──────────────────┘
```

---

## Amiga DB-23 Pinout (Amiga Hardware Reference Manual, Appendix E)

Quelle: Amiga HRM, Appendix E „External Disk Interface Specification“, Pin Assignment (J7).
Am Amiga ist der Floppy-Port eine **DB-23-Buchse**; externe Laufwerke (A1010 …) haben einen **DB-23-Stecker** am Kabel.
Das Adapterkabel braucht daher eine **DB-23-Buchse** (wie der Amiga).

```
Pin  Signal        Dir*   Beschreibung
───────────────────────────────────────────────
 1   /RDY          ◄──    Ready (bzw. ID-Datenstrom im Identification Mode)
 2   /DKRD         ◄──    MFM Read Data
 3   GND           ───    Ground
 4   GND           ───    Ground
 5   GND           ───    Ground
 6   GND           ───    Ground
 7   GND           ───    Ground
 8   /MTRXD        ──►    Motor-on Data (wird mit /SELxB ins Laufwerk getaktet)
 9   /SEL2B        ──►    Select Drive 2
10   /DRESB        ──►    Reset (Laufwerk setzt Motor-FF zurück)
11   /CHNG         ◄──    Disk Change
12   +5V           ───    Power +5V (270 mA max, 410 mA Anlauf)
13   /SIDEB        ──►    Side Select
14   /WPRO         ◄──    Write Protect
15   /TK0          ◄──    Track 0
16   /DKWEB        ──►    Write Gate
17   /DKWDB        ──►    MFM Write Data
18   /STEPB        ──►    Step
19   DIRB          ──►    Direction (inaktiv = Richtung Mitte)
20   /SEL3B        ──►    Select Drive 3
21   /SEL1B        ──►    Select Drive 1 (erstes externes Laufwerk)
22   /INDEX        ◄──    Index
23   +12V          ───    Power +12V (160 mA max, 540 mA Anlauf)

* Richtung aus Sicht des Hosts (UFI): ──► Ausgang, ◄── Eingang
```

---

## Verdrahtung (UFI J4 ↔ DB-23)

| UFI J4 Pin | Signal | DB-23 Pin | Signal |
|---|---|---|---|
| 1, 19, 20 | GND | 3, 4, 5, 6, 7 | GND |
| 2, 4, 21, 22 | +5V | 12 | +5V |
| 3 | RDATA | 2 | /DKRD |
| 5 | SIDE | 13 | /SIDEB |
| 6 | DKCHG | 11 | /CHNG |
| 7 | DIR | 19 | DIRB |
| 8 | WPROT | 14 | /WPRO |
| 9 | STEP | 18 | /STEPB |
| 10 | TRK0 | 15 | /TK0 |
| 11 | WDAT | 17 | /DKWDB |
| 12 | WGATE | 16 | /DKWEB |
| 13 | INDEX | 22 | /INDEX |
| 14 | READY | 1 | /RDY |
| 15 | SEL | 21 | /SEL1B |
| 17 | MTRX | 8 | /MTRXD |
| 24 | +12V | 23 | +12V |
| – | – | 9, 10, 20 | /SEL2B, /DRESB, /SEL3B: im Stecker je 1 kΩ nach +5V (inaktiv) oder offen lassen |

> ⚠ Die J4-Belegung der Modular-Platine führt RDATA doppelt (Pin 3 und 16 „DKRD“) und SEL doppelt (Pin 15 und 18 „/SEL1“).
> Pin 16 und 18 hier **nicht** verdrahten, bis die J4-Belegung im Modular-Schaltplan geklärt ist.
>
> **UFI Headless (J7):** Header-Pin n = DB-23-Pin n (Pin 24 = GND), SEL2B/SEL3B/DRESB sind auf der Platine bereits per 1 kΩ inaktiv – das Kabel ist dort 1:1.

---

## Kabel-Konstruktion

### Benötigte Teile

| Teil | Bezeichnung | Menge |
|---|---|---|
| Stecker | 2x12 IDC Header Male | 1 |
| Buchse | DB-23 Female (wie am Amiga; Laufwerkskabel hat Stecker) | 1 |
| Kabel | 26-adriges Flachbandkabel | ~30cm |
| Gehäuse | DB-23 Kunststoffgehäuse | 1 |

### Aufbau

```
┌─────────────────────────────────────────────────────────────────────────────────────────┐
│                                                                                          │
│   IDC 2x12                    Flachbandkabel                    DB-23 Female            │
│   ┌─────┐                     ════════════════                  ┌─────────────┐         │
│   │█████│────────────────────────────────────────────────────►│             │         │
│   │█████│                     ~30cm                             │  ●●●●●●●●●  │         │
│   └─────┘                                                       │   ●●●●●●●●  │         │
│                                                                 │    ●●●●●●   │         │
│                                                                 └─────────────┘         │
│                                                                                          │
└─────────────────────────────────────────────────────────────────────────────────────────┘
```

### Lötplan DB-23

```
          ┌─────────────────────────────────────┐
          │  1   2   3   4   5   6   7   8   9  │
          │  RDY RD GND GND GND GND GND MTR S2  │
          │                                     │
          │   10  11  12  13  14  15  16  17    │
          │   RES CHG +5V SID WPR TK0 WG  WD    │
          │                                     │
          │     18  19  20  21  22  23          │
          │     STP DIR S3  S1  IDX +12         │
          └─────────────────────────────────────┘
```

---

## Signalpegel

Alle Signale sind Active-Low (0V = Aktiv, 5V = Inaktiv).

UFI Headless: Ausgänge über SN74LS07 (Open Collector, 40 mA), Eingänge über 74LVC14A mit 1 kΩ Pull-ups auf +5V (siehe `kicad/UFI_Headless/README.md`).

---

## Kompatible Laufwerke

| Laufwerk | Typ | getestet |
|---|-----|---|
| A1010 | 3.5" 880K | ☐ |
| A1011 | 3.5" 880K | ☐ |
| Cumana CAX354 | 3.5" 880K | ☐ |
| Externe PC-Laufwerke (mit Adapter) | 3.5" | ☐ |

---

## Hinweise

1. **Stromversorgung:** Das Laufwerk wird über das Kabel mit +5V und +12V versorgt. Sicherstellen dass das UFI-Netzteil ausreichend Leistung liefert. UFI Headless v0.2: J7 Pin 12/23 sind über Polyfuses (1,1 A) abgesichert, die Busleitungen per ESD-Arrays geschützt.

2. **Drive Select:** Standard ist /SEL1 (Pin 13). Bei mehreren Laufwerken /SEL2 oder /SEL3 verwenden.

3. **Kein Daisy-Chain:** Im Gegensatz zum Original-Amiga kein Daisy-Chain möglich. Ein Kabel pro Laufwerk.

4. **Motor Control:** /MTRX muss LOW sein damit der Motor dreht.

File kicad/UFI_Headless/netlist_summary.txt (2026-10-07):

== Power
+12V             C1.1 C2.1 C3.1 D2.1 D3.1 F3.1 TP3.1 U2.3
+12V_IN          D2.2 J17.4 J2.1
+3V3             C15.1 C16.1 C49.1 C50.1 R7.1 TP1.1 U12.5 U13.5 U4.3
+5V              C11.1 C12.1 C13.1 C14.1 F2.1 TP2.1 U3.2 U3.7 U4.1
+5V_DRV          C5.1 C6.1 C7.1 J18.1 L1.2 R3.1
+5V_PRI          C8.1 C9.1 J18.2 R5.1 U3.3 U3.5
+5V_PSU          F4.1 J17.1
+5V_PSU_F        D17.1 F4.2 J18.3
BUCK_BST         C4.1 U2.6
BUCK_FB          R3.2 R4.1 U2.4
BUCK_SW          C4.2 L1.1 U2.2
CC1              J1.A5 R1.1
CC2              J1.B5 R2.1
FDD12_EN         Q4.1 R31.1
FDD12_F          F3.2 R29.1 U13.3
FDD12_G          Q3.1 R30.2 R32.1
FDD12_GD         Q4.3 R32.2
FDD12_S          Q3.2 R29.2 R30.1 U13.4
FDD5_EN          Q2.1 R28.1
FDD5_F           F2.2 R26.1 U12.3
FDD5_G           Q1.1 Q2.3 R27.2
FDD5_S           Q1.2 R26.2 R27.1 U12.4
FDD_12V          D14.1 J3.4 Q3.3
FDD_5V           D13.1 J3.1 Q1.3
GND              C1.2 C10.2 C11.2 C12.2 C13.2 C14.2 C15.2 C16.2 C2.2 C3.2 C49.2 C5.2 C50.2 C6.2 C7.2 C8.2 C9.2 D1.2 D13.2 D14.2 D17.2 D3.2 J1.A1 J1.A12 J1.B1 J1.B12 J1.SH J16.7 J16.8 J17.2 J17.3 J2.2 J3.2 J3.3 Q2.2 Q4.2 R1.2 R2.2 R28.2 R31.2 R4.2 R6.2 TP4.1 U1.2 U12.2 U13.2 U2.1 U3.1 U4.2
I_FDD12          U13.1
I_FDD5           U12.1
MUX_PR1          R5.2 R6.1 U3.4
PWR_SRC          R7.2 U3.8
USB_DM           J1.A7 J1.B7 J16.3 U1.3 U1.4
USB_DP           J1.A6 J1.B6 J16.5 U1.1 U1.6
VBUS             D1.1 F1.1 J1.A4 J1.A9 J1.B4 J1.B9 J16.1 U1.5
VBUS_F           C10.1 F1.2 U3.6
== MCU_Core
+3V3             C17.1 C18.1 C19.1 C20.1 C21.1 C22.1 C23.1 C24.1 C25.1 C26.1 C27.1 C28.1 C29.1 C30.1 C31.1 C32.1 C46.1 C47.1 C48.1 FB1.1 J13.2 J4.1 J9.1 R15.1 R16.1 R17.1 R19.1 R20.1 R21.1 R22.1 R23.1 R24.1 R25.1 R34.1 SW2.1 U11.8 U15.8 U5.108 U5.121 U5.131 U5.143 U5.144 U5.17 U5.30 U5.39 U5.52 U5.6 U5.62 U5.72 U5.84 U5.95
+5V              J9.2
APL_EN1          U5.90
APL_EN2          U5.73
APL_PH0          U5.50
APL_PH1          U5.53
APL_PH2          U5.91
APL_PH3          U5.55
APL_RDDATA       U5.36
APL_WRDATA       U5.43
APL_WRPROT       U5.76
APL_WRREQ        U5.75
BOARD_ID         R17.2 R18.1 U5.40
BOOT0            R8.1 SW2.2 U5.138
BTN_A            J9.7 SW3.1 U5.139
BTN_B            J9.8 SW4.1 U5.140
CC1              U5.34
CC2              U5.37
DBG_RX           J5.2 U5.78
DBG_TX           J5.1 U5.77
EXP_IO1          J13.1 J9.5 U5.141
EXP_IO2          J13.3 J9.6 U5.142
FDD12_EN         U5.2
FDD5_EN          U5.1
FDD_DENSITY      U5.68
FDD_DIR          U5.65
FDD_DRATE        U5.49
FDD_DRVSEL_A     U5.60
FDD_DRVSEL_B     U5.63
FDD_DSKCHG       U5.12
FDD_INDEX        U5.35
FDD_MOTOR_A      U5.58
FDD_MOTOR_B      U5.59
FDD_RDATA        U5.41
FDD_READY        U5.13
FDD_SIDE         U5.66
FDD_STEP         U5.64
FDD_TRK0         U5.10
FDD_WDATA        U5.42
FDD_WGATE        U5.67
FDD_WPROT        U5.11
FRONT_ACT        J12.3 R35.2
FRONT_ERR        J12.7 R37.2
FRONT_FDD        J12.5 R36.2
FRONT_PWR        J12.1 R34.2
GND              C17.2 C18.2 C19.2 C20.2 C21.2 C22.2 C23.2 C24.2 C25.2 C26.2 C27.2 C28.2 C29.2 C30.2 C31.2 C32.2 C33.2 C34.2 C35.2 C36.2 C37.2 C38.2 C39.2 C46.2 C47.2 C48.2 D4.1 D5.1 D6.1 D7.1 D8.1 J12.2 J12.4 J12.6 J12.8 J4.3 J4.5 J4.9 J5.3 J9.10 J9.9 R10.2 R18.2 R8.2 SW1.2 SW3.2 SW4.2 U11.4 U15.4 U5.107 U5.120 U5.130 U5.16 U5.31 U5.38 U5.51 U5.61 U5.83 U5.94 Y1.2 Y1.4
HSE_IN           C38.1 U5.23 Y1.1
HSE_OUT          C39.1 U5.24 Y1.3
I2C_SCL          J9.3 R19.2 U5.136
I2C_SDA          J9.4 R20.2 U5.137
IEC_ATN_IN       U5.14
IEC_ATN_OUT      U5.114
IEC_CLK_IN       U5.15
IEC_CLK_OUT      U5.115
IEC_DATA_IN      U5.18
IEC_DATA_OUT     U5.116
IEC_RESET_IN     U5.20
IEC_RESET_OUT    U5.118
IEC_SRQ_IN       U5.19
IEC_SRQ_OUT      U5.117
I_FDD12          U5.27
I_FDD5           U5.26
LED_ACT          R11.1 R35.1 U5.56
LED_ACT_A        D4.2 R11.2
LED_ERR          R14.1 R37.1 U5.88
LED_ERR_A        D7.2 R14.2
LED_FDD          R12.1 R36.1 U5.57
LED_FDD_A        D5.2 R12.2
LED_PWR_A        D8.2 R15.2
LED_USB          R13.1 U5.87
LED_USB_A        D6.2 R13.2
NRST             C37.1 J4.10 SW1.1 U5.25
PSRAM_CLK        U11.6 U5.48
PSRAM_CS         R16.2 U11.1 U5.69
PSRAM_IO0        U11.5 U5.80
PSRAM_IO1        U11.2 U5.81
PSRAM_IO2        U11.3 U5.74
PSRAM_IO3        U11.7 U5.82
PWR_SRC          U5.89
SD_CLK           U15.3 U5.122
SD_CMD           R21.2 U15.5 U5.123
SD_D0            R22.2 U15.6 U5.124
SD_D1            R23.2 U15.7 U5.125
SD_D2            R24.2 U15.1 U5.126
SD_D3            R25.2 U15.2 U5.127
SWCLK            J4.4 U5.109
SWDIO            J4.2 U5.105
SWO              J4.6 U5.133
USB_DM           U5.103
USB_DP           U5.104
VBUS             R9.1
VBUS_SENSE       R10.1 R9.2 U5.101
VCAP1            C35.1 U5.71
VCAP2            C36.1 U5.106
VDDA             C33.1 C34.1 FB1.2 U5.32 U5.33
WLOCK            U5.3
== Flux_Interface
+3V3             C42.1 C51.1 J11.1 U14.5 U8.14
+5V              C40.1 C41.1 C43.1 RN1.5 RN1.6 RN1.7 RN1.8 RN2.5 RN2.6 RN2.7 RN2.8 RN3.6 RN3.7 RN3.8 RN4.5 RN4.6 RN4.7 RN4.8 RN5.7 RN5.8 U6.14 U7.13 U7.14
FDD_DENSITY      U7.9
FDD_DIR          U6.13
FDD_DRATE        U7.11
FDD_DRVSEL_A     U6.5
FDD_DRVSEL_B     U6.9
FDD_DSKCHG       U8.10
FDD_INDEX        TP6.1 U8.2
FDD_MOTOR_A      U6.1
FDD_MOTOR_B      U6.3
FDD_RDATA        TP5.1 U8.8
FDD_READY        U8.12
FDD_SIDE         U7.1
FDD_STEP         U6.11
FDD_TRK0         U8.4
FDD_WDATA        TP7.1 U7.5
FDD_WGATE        U14.1
FDD_WGATE_G      TP8.1 U14.4 U7.3
FDD_WPROT        U8.6
FD_DENSITY       RN3.2 U7.8
FD_DIR           RN2.2 U6.12
FD_DRATE         RN3.3 U7.10
FD_DRVSEL_A      RN1.3 U6.6
FD_DRVSEL_B      RN1.4 U6.8
FD_DSKCHG        RN5.1 U8.11
FD_INDEX         RN4.1 U8.1
FD_MOTOR_A       RN1.1 U6.2
FD_MOTOR_B       RN1.2 U6.4
FD_RDATA         RN4.4 U8.9
FD_READY         RN5.2 U8.13
FD_SIDE          RN2.3 U7.2
FD_STEP          RN2.1 U6.10
FD_TRK0          RN4.2 U8.3
FD_WDATA         RN3.1 U7.6
FD_WGATE         RN2.4 U7.4
FD_WPROT         RN4.3 U8.5
GND              C40.2 C41.2 C42.2 C43.2 C51.2 R33.2 U14.3 U6.7 U7.7 U8.7
WLOCK            J11.2 R33.1 U14.2
== FDD_Connectors
+5V              RN6.6 RN6.7 RN6.8
AMI_DRES         J7.10 RN6.3
AMI_SEL2         J7.9 JP3.2 RN6.1
AMI_SEL3         J7.20 RN6.2
FDD_12V          J7.23
FDD_5V           J7.12 JP2.3
FD_DENSITY       J6.2
FD_DIR           D11.1 J6.18 J7.19
FD_DRATE         JP1.1
FD_DRVSEL_A      D11.6 J6.14 JP3.1
FD_DRVSEL_B      D11.3 J6.12 J7.21
FD_DSKCHG        D9.5 J6.34 J7.11
FD_INDEX         D11.4 J6.8 J7.22
FD_MOTOR_A       D11.5 J6.10
FD_MOTOR_B       D9.4 J6.16 J7.8
FD_PIN3          J6.3 JP2.2
FD_PIN6          J6.6 JP1.2
FD_RDATA         D9.3 J6.30 J7.2
FD_READY         D9.1 J7.1
FD_SIDE          D9.6 J6.32 J7.13
FD_STEP          D10.6 J6.20 J7.18
FD_TRK0          D10.3 J6.26 J7.15
FD_WDATA         D10.5 J6.22 J7.17
FD_WGATE         D10.4 J6.24 J7.16
FD_WPROT         D10.1 J6.28 J7.14
GND              D10.2 D11.2 D9.2 J6.1 J6.11 J6.13 J6.15 J6.17 J6.19 J6.21 J6.23 J6.25 J6.27 J6.29 J6.31 J6.33 J6.5 J6.7 J6.9 J7.24 J7.3 J7.4 J7.5 J7.6 J7.7 JP2.1
== IEC_Bus
+3V3             C45.1 U10.14
+5V              C44.1 RN7.5 RN7.6 RN7.7 RN7.8 RN8.8 U9.13 U9.14
GND              C44.2 C45.2 D12.2 J8.2 U10.13 U10.7 U9.7
IEC_ATN          D12.1 J8.3 RN7.1 U10.1 U9.2
IEC_ATN_IN       U10.2
IEC_ATN_OUT      U9.1
IEC_CLK          D12.3 J8.4 RN7.2 U10.3 U9.4
IEC_CLK_IN       U10.4
IEC_CLK_OUT      U9.3
IEC_DATA         D12.4 J8.5 RN7.3 U10.5 U9.6
IEC_DATA_IN      U10.6
IEC_DATA_OUT     U9.5
IEC_RESET        D12.6 J8.6 RN8.1 U10.11 U9.10
IEC_RESET_IN     U10.10
IEC_RESET_OUT    U9.11
IEC_SRQ          D12.5 J8.1 RN7.4 U10.9 U9.8
IEC_SRQ_IN       U10.8
IEC_SRQ_OUT      U9.9
== Apple_Port
+3V3             C53.1 RN10.6 RN10.7 RN10.8 U17.5
APL_EN1          RN10.1 U16.17
APL_EN2          RN10.2 U16.15
APL_PH0          RN9.1 U16.2
APL_PH1          RN9.2 U16.4
APL_PH2          RN9.3 U16.6
APL_PH3          RN9.4 U16.8
APL_RDDATA       U17.6
APL_WRDATA       U16.11
APL_WRPROT       U17.4
APL_WRREQ        RN10.3 U16.13
AP_EN1           D15.6 J14.14 U16.3
AP_EN2           D16.1 J15.1 U16.5
AP_M12V          C56.2 J14.9 U18.5
AP_PH0           D15.1 J14.2 U16.18
AP_PH1           D15.3 J14.4 U16.16
AP_PH2           D15.4 J14.6 U16.14
AP_PH3           D15.5 J14.8 U16.12
AP_RDDATA        D16.5 J14.16 R38.2 U17.1
AP_WRDATA        D16.4 J14.18 U16.9
AP_WRPROT        D16.6 J14.20 R39.2 U17.3
AP_WRREQ         D16.3 J14.10 U16.7
FDD_12V          C54.1 J14.13 J14.15 J14.17 J14.19 U18.8
FDD_5V           C52.1 J14.11 J14.12 J19.1 R38.1 R39.1 U16.20
FD_INDEX         J19.3
GND              C52.2 C53.2 C54.2 C56.1 D15.2 D16.2 J14.1 J14.3 J14.5 J14.7 J15.2 J19.2 RN9.5 RN9.6 RN9.7 RN9.8 U16.1 U16.10 U16.19 U17.2 U18.3
M12_CN           C55.2 U18.4
M12_CP           C55.1 U18.2

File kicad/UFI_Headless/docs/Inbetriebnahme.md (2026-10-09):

# Inbetriebnahme UFI Headless v0.6

Reihenfolge einhalten: jede Stufe erst, wenn die vorige passt. Ergebnisse in die Spalte ✔ eintragen.
Messpunkte: **TP1** 3V3 · **TP2** 5V · **TP3** 12V · **TP4** GND · **TP5** RDATA · **TP6** INDEX · **TP7** WDATA · **TP8** WGATE (hinter der Schreibsperre).
LEDs: PWR (grün, 3V3) · ACT · FDD · USB · ERR (rot).

Werkzeug: Labornetzteil mit Strombegrenzung, Multimeter, Oszilloskop (≥ 50 MHz), ST-Link (SWD) oder USB-DFU,
ein **Schrott-Laufwerk** und **Schrott-Disketten** für alle Schreibtests.

## 1 Sichtprüfung (ohne Strom)

| # | Prüfung | Soll | ✔ |
|---|---|---|---|
| 1.1 | Pin-1-Markierungen U5 (MCU), U6/U7/U9 (LS07), U8/U10 (LVC14), U11 (PSRAM), U12/U13 (INA180), U14, U15 (SD-NAND) | Punkt am Pin 1 | |
| 1.2 | Polarität D-TVS/Schottky (SS54), Elkos, LEDs | laut Bestückungsdruck | |
| 1.3 | Lötbrücken, v. a. QFP-144 (U5) und SOT-353 (U14) | keine Brücken (Lupe) | |
| 1.4 | JP1 offen, JP2 auf 1-2 (GND), Jumper J11 (WRITE LOCK) **gesteckt** | Auslieferungszustand + Schreibschutz | |
| 1.5 | Widerstand gegen GND (TP4): TP1 3V3, TP2 5V, TP3 12V, FDD_5V/12V an J3 | > 100 Ω, kein Kurzschluss | |

## 2 Versorgung (ohne Firmware, ohne Laufwerk)

| # | Prüfung | Soll | ✔ |
|---|---|---|---|
| 2.1 | 12 V an J2, Netzteil auf **150 mA** begrenzt (J18 auf 1-2) | Strom < 100 mA, PWR-LED an | |
| 2.1a | v0.7 PC-Einbau: J17 am Labornetzteil (Pin 1 5 V, Pin 4 12 V, je 150 mA), J18 auf 2-3, J2 frei | TP2 ≈ 5 V; J18 auf 1-2 umstecken: 5 V weiter aus dem 12-V-Wandler | |
| 2.1b | v0.7: USB über J16 (Header-Kabel vom Mainboard), USB-C frei, kein 12 V | Gerät meldet sich am PC, läuft aus USB-5 V (PWR_SRC = USB) | |
| 2.2 | TP3 / TP2 / TP1 | 11,5–12,5 V / 4,9–5,2 V / 3,25–3,35 V | |
| 2.3 | Verpolung kurz testen (12 V falsch herum, 150 mA) | kein Strom (SS54), nichts warm | |
| 2.4 | Nur USB-C am PC (ohne 12 V) | TP2 ≈ 5 V über den TPS2116, TP1 3,3 V | |
| 2.5 | FDD_5V / FDD_12V an J3 (Pins 1 / 4) | **0 V** – Schalter aus, solange keine Firmware läuft | |
| 2.6 | Temperatur nach 2 min (Finger/IR): Buck U2, LDO U4, MCU | handwarm | |

## 3 Firmware flashen

| # | Schritt | Soll | ✔ |
|---|---|---|---|
| 3.1 | `cmake -S firmware -B firmware/build -G Ninja && cmake --build firmware/build` | `ufi_firmware.bin`, keine Warnungen | |
| 3.2 | Flashen: ST-Link an J4 (SWD) **oder** BOOT-Taster (SW2) halten + RESET (SW1) → `dfu-util -a 0 -s 0x08000000:leave -D ufi_firmware.bin` | erfolgreich | |
| 3.3 | Nach dem Start (12 V an, Netzteil 500 mA) | 3 ERR-Blinker = PSRAM-Fehler; sonst keine ERR-LED | |
| 3.4 | `ufi info` | `UFI Flux Engine v1.11 <rev> <datum>` · `UFI Headless v0.7` · `STM32H723` · `PSRAM 8 MB ok` | |
| 3.5 | Bei „rev ?“: Spannung an PA4 (R17/R18) messen | 0,60 V (v0.7, R18 = 2,2k) | |
| 3.6 | `ufi selftest`, `ufi status` | keine Fehler | |

Neue v0.5-Befehle (Host-Tool hat dafür noch keine Kommandos) – in Python:

```python
import struct
from ufi_host import protocol as P
d = P.Device(P.open_serial())
st = lambda: struct.unpack("<BBHHH", d.command(0x1B))   # power, flags, i5_mA, i12_mA, board_id_mV
print(st())                       # Laufwerksversorgung ein/aus: d.command(0x1B, maske)
print(d.command(0x1D))            # SD_INFO: ready, status, type, bus, capacity_MB (u32)
```

## 4 Board-Funktionen v0.5

| # | Prüfung | Soll | ✔ |
|---|---|---|---|
| 4.1 | `st()` nach dem Start | power = 3 (beide an), FDD_5V/12V an J3 ≈ 5 / 12 V | |
| 4.2 | Ohne Laufwerk: i5_mA / i12_mA | < 20 mA (Offset INA180) | |
| 4.3 | Taster **B** beim Einschalten halten | ERR-LED an, power = 0, Flag Bit6; `d.command(0x1B, 3)` schaltet ein | |
| 4.4 | J11 gesteckt / gezogen | Flag Bit0 = 1 / 0 | |
| 4.5 | Taster A/B während des Betriebs gedrückt | Flag Bit4 / Bit5 | |
| 4.6 | Last 10 Ω/5 W an FDD_5V (≈ 0,5 A), dann 3,3 Ω (≈ 1,5 A) | i5_mA ≈ 500; bei > 1,5 A nach 50 ms aus, Flag Bit1, ERR-LED | |
| 4.6a | Front-LEDs an J12 (1+/2− PWR, 3+/4− ACT, 5+/6− FDD, 7+/8− ERR), LED-Test `d.command(0xD0, 2)` | grün dauerhaft, gelbe LEDs leuchten mit ACT/FDD/ERR mit; zu dunkel → R34–R37 kleiner (min. 150 Ω) | |
| 4.7 | `st()` Flag Bit3 | 1 = SD-NAND U15 initialisiert | |
| 4.8 | `SD_INFO` | ready 1, status 0, bus 4, capacity 3500–4000 MB (4 GB) bzw. 900–1000 MB (1 GB) | |
| 4.9 | Taster **A** beim Einschalten | DFU-Gerät erscheint (`dfu-util -l`) | |

## 5 Laufwerk lesen (nur lesen, J11 gesteckt lassen)

| # | Prüfung | Soll | ✔ |
|---|---|---|---|
| 5.1 | 3,5"-Laufwerk an J6 + Strom an J3, `ufi select a`, `ufi motor on` | Motor läuft, Strom i5/i12 plausibel (Anlauf kurz höher) | |
| 5.2 | `ufi recal`, `ufi seek 79`, `ufi seek 0` | Kopf fährt, TRK0 erkannt | |
| 5.3 | `ufi rpm` (Firmware ≥ 1.13: aus den Indeximpulsen, mit min/max und Impulsbreite) | 300 ± 3 (bzw. 360 bei HD-5,25"), Schwankung < ±1 ms, Impuls 1–8 ms | |
| 5.3a | `ufi scan` (Firmware ≥ 1.13; Köpfe bewegen sich) | Zeile `a`: answers yes, spins, Schreibschutz passend zur Diskette; b/amiga/amiga2 ohne Laufwerk `-` | |
| 5.4 | Oszi TP6 (INDEX) | ein Puls je Umdrehung, 200 ms, saubere Flanken | |
| 5.5 | Oszi TP5 (RDATA) während `ufi read 0 0 -r 3` | Abstände der Pulse 4/6/8 µs (DD) bzw. 2/3/4 µs (HD), keine Prellungen | |
| 5.6 | `ufi read 0 0 -r 3` mit bekannter Diskette | 3 Umdrehungen, Flusswechsel/Umdrehung plausibel (DD ≈ 35k, HD ≈ 70k) | |
| 5.7 | Ganze Diskette `ufi read-disk -o test.scp --tracks 80 --sides 2 -r 3`, Zeit stoppen | Image in HxC/Greaseweazle-Tools lesbar; **Dauer notieren** (USB-Durchsatz) | |
| 5.8 | Amiga-Laufwerk an J7: `ufi select amiga`, `ufi amiga-id` | ID wie im README | |
| 5.9 | USB-Kabel während `ufi motor on` ziehen | nach < 0,3 s Motor aus, Laufwerk abgewählt | |
| 5.10 | Motor an lassen, 30 s nichts tun | Motor geht selbst aus | |
| 5.11 | Dump ohne PC: USB ab, 12 V an, Diskette rein, Taster A ≥ 1 s | FDD-LED je Spur, ACT blinkt; danach ACT dauerhaft an. ERR-Blinkcode: 1 Speicher, 2 Laufwerk/Lesen, 3 voll/Schreibfehler, 4 abgebrochen | |
| 5.12 | Während eines Dumps Taster B kurz | Abbruch, ERR blinkt 4× | |
| 5.13 | Taster B ≥ 2 s (USB am PC) | USB-LED an, Laufwerk „UFI“ erscheint; `DUMP0001.SCP` kopieren und mit dem Image aus 5.7 vergleichen (gleiche Diskette: Spurdaten ähnlich, Format identisch) | |
| 5.14 | Taster B ≥ 2 s erneut | USB-LED aus, `ufi info` geht wieder | |
| 5.15 | Betriebsart-Schalter an J13 (Kabel 1:1, Mittelkontakt = Pin 2), auf „USB-Floppy“ (Pin 1) | ACT blinkt 2×, USB-LED an, am PC erscheint „UFI USB Floppy“ | |
| 5.16 | Formatierte 1,44-MB-Diskette rein, Explorer öffnen, Datei kopieren/lesen | Inhalt sichtbar, Datei lesbar; nach dem Schreiben läuft der Motor ~1 s nach (Rückschreiben + Prüflesen) | |
| 5.17 | Dasselbe mit 720K (und, falls 5,25"-Laufwerk, 1,2M / 360K) | Größe stimmt im Explorer | |
| 5.18 | Diskette wechseln, Explorer F5 | neuer Inhalt; ohne Diskette „kein Datenträger“ | |
| 5.19 | Schalter zurück in die Mitte | ACT blinkt 1×, `ufi info` geht wieder | |

## 6 Schreiben (Schrott-Diskette, J11 ziehen)

| # | Prüfung | Soll | ✔ |
|---|---|---|---|
| 6.1 | J11 gesteckt, Schreibversuch | Fehler „write protected“, TP8 bleibt high | |
| 6.2 | J11 gezogen, `WRITE_PATTERN` 2 µs, 1 s: `d.command(0x34, 0, 0, 0xD0, 0x07, 0xE8, 0x03)` (Motor an) | TP8 low für 1 s, TP7: 400-ns-Pulse alle 2 µs | |
| 6.3 | `ufi write` / `write-disk --verify` mit dem Image aus 5.7 | Verify ok, zurückgelesen identisch decodierbar | |
| 6.4 | Schreibgeschützte Diskette | Fehler „write protected“ | |

## 7 Sonstiges

| # | Prüfung | Soll | ✔ |
|---|---|---|---|
| 7.1 | 3-Mode-Laufwerk: JP1 brücken, `SET_LINES` DRATE an/aus, HD-Diskette lesen | **DRATE-Polarität festhalten** | |
| 7.2 | 1541 an J8 (DIN-6-Kabel): `ufi iec-reset`, `ufi iec-send 0x28`, `ufi iec-recv` | Laufwerk antwortet | |
| 7.2a | Shugart-Bus: gerades Kabel, Laufwerke auf DS0/DS1/DS2 (DS3 nur mit JP1) gejumpert; `ufi select ds0` … `ds3`, `ufi motor on`, `ufi recal`, `ufi read 0 0` | jeweils nur das gewählte Laufwerk reagiert (Kopf fährt, LED), alle Motoren laufen gemeinsam | |
| 7.2b | `UFI.CFG` im SD-Laufwerk-Modus auf `drive=ds1` ändern, Neustart, Dump mit Taster A | Dump läuft auf dem DS1-Laufwerk | |
| 7.2c | Nach einem Dump `DUMPnnnn.LOG` im SD-Laufwerk-Modus öffnen | Format erkannt, gute Disketten: alle Spuren voll, Drehzahl ≈ 300 | |
| 7.2d | Zwei Laufwerke, `button_a=copy`, `copy_from=a`, `copy_to=b`, Neustart, Schrott-Diskette in B, Taster A | Kopie läuft, ACT dauerhaft an; Kopie im PC lesbar | |
| 7.2e | `UFI.CFG` `protocol=gw`, Neustart (Schalter Mitte), Greaseweazle-Werkzeuge installiert: `gw info`, `gw read --drive A --revs 3 t.scp`, `gw write --drive B t.scp` auf eine Schrott-Diskette | ACT blinkt 4×; `gw info` zeigt Firmware 1.11, Modell „Unknown (0x5501)“; Lesen/Schreiben fehlerfrei, Kopie im PC lesbar | |
| 7.2f | Apple-Port **ohne** Laufwerk: Laufwerksversorgung an, J14 Pin 9 gegen GND, Pin 11/12 und 13 | −11…−12 V, +5 V, +12 V | |
| 7.2g | Oszi an J14 Pin 2/4/6/8 bei `ufi select apple`, `ufi motor on`, `ufi recal` | Phasen nacheinander 0→3 rückwärts (80 Halbschritte), danach alle low; Pin 14 (/ENABLE) low solange Motor an | |
| 7.2h | Disk II an J14 (Originalkabel, rote Ader = Pin 1), `ufi select apple`, `ufi motor on`, `ufi recal`, `ufi read 0 0 -r 2` (Firmware nimmt bei Apple automatisch 200-ms-Abschnitte statt Index) | Kopf klackert an Spur 0, Fluss 4-µs-Raster (GCR), ~50 000 Wechsel je 200 ms | |
| 7.2i | `UFI.CFG` `drive=apple`, `tracks=35`, `sides=1`, Dump mit Taster A, SCP am PC mit `a2r`/Applesauce-Tools bzw. HxC öffnen | DOS-3.3/ProDOS-Diskette dekodierbar | |
| 7.2j | Schreiben (J11 ziehen, Schrott-Diskette): eine gelesene Spur zurückschreiben, erneut lesen | gleiche Flussanzahl ±5 %; WRDATA an Pin 18 wechselt je Flusswechsel den Pegel | |
| 7.2k | Sync-Sensor an J19, Magnet an der Disk-II-Spindel, `UFI.CFG apple_sync=1`, `ufi select apple`, `ufi motor on`, `ufi read 0 0 -r 3` | Oszi TP6 (INDEX): ein Puls je Umdrehung ≥ 500 µs; `ufi read` zeigt ≈ 300 U/min je Umdrehung (echte Index-Umdrehungen) | |
| 7.3 | 40-Spur-Diskette im 80-Spur-Laufwerk: `ufi timing double_step=1` | Spuren lesbar | |
| 7.4 | `SEEK_TEST`: `d.command(0x1E, 0, 79, 5, timeout=60)` | Kopf pendelt 5×, kein Schrittverlust (danach `recal`) | |

## Ergebnisse, die zurück in Firmware/Doku müssen

- SD-NAND-Schreibrate (5.11: Dauer eines Dumps) → ggf. SDMMC-Takt 25 → 50 MHz in `firmware/src/ufi_sd.c`
- DRATE-Polarität (7.1) → Doku `SET_LINES`
- USB-Durchsatz (5.7) → entscheidet, ob USB High Speed (v0.7) nötig ist
- Strommessung: Offset/Steigung (4.2/4.6) → ggf. Kalibrierung in `ufi_board.c`

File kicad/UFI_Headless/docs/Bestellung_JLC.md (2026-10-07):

# Bestellung bei JLCPCB – UFI Headless v0.7

Dateien: `kicad/UFI_Headless/fertigung/` bzw. Anhang des GitHub-Release **v0.7** (dort mit `_v0.7` im Namen: `UFI_Headless_v0.7_gerber.zip`, `…_bom-jlc.csv`, `…_cpl-jlc.csv`).

## 1 Leiterplatte

Auf jlcpcb.com → *Order now* → `UFI_Headless_gerber.zip` hochladen. Größe (110 × 97 mm) und Lagen erkennt JLC selbst.

| Option | Einstellung | Warum |
|---|---|---|
| Layers | **4** | GND-Fläche In1, Signale/+3V3 In2 |
| Dimensions | 110 × 97 mm | aus Gerber |
| PCB Qty | 5 (Minimum) | |
| PCB Thickness | **1.6 mm** | Board-Aufbau in KiCad |
| Impedance Control | **No** / Standard-Lagenaufbau | USB Full Speed, keine kontrollierte Impedanz nötig |
| Via Covering | **Tented** | Vias liegen u. a. dicht an Bauteilen; Board ist so ausgelegt |
| Surface Finish | **ENIG** (empfohlen) | ebene Pads für QFP-144 (0,5 mm) und SOT-353; HASL geht, ist aber uneben |
| Min via hole / Track | Standard (0,3 mm / 0,2 mm genügen) | Board nutzt 0,3-mm-Bohrung, 0,2-mm-Bahnen, 0,15 mm Abstand |
| Mark on PCB / Order number | „Remove“ (Aufpreis) oder egal | Bestückungsdruck ist voll, Nummer landet sonst irgendwo |
| Gold fingers, Castellated | No | |

## 2 Bestückung (PCB Assembly)

| Option | Einstellung |
|---|---|
| PCBA Type | **Standard** (Economic geht nur, wenn für 4 Lagen angeboten; Standard ist sicher) |
| Assembly Side | **Top Side** (alle Bauteile oben) |
| PCBA Qty | 2 (reicht für Inbetriebnahme + Ersatz) |
| Tooling holes | Added by JLCPCB |
| Confirm Parts Placement | **Yes** – Platzierung im Viewer selbst prüfen |

Upload: **BOM** `UFI_Headless-bom-jlc.csv`, **CPL** `UFI_Headless-cpl-jlc.csv`.

### Teileprüfung (BOM-Schritt)
- Alle LCSC-Nummern sind gesetzt und wurden am 05.–07.10.2026 auf Lager geprüft. Bei „out of stock“: gleiches Bauteil mit anderer LCSC-Nummer wählen (Wert/Gehäuse identisch).
- **Extended Parts** kosten je ~3 $ Rüstgebühr (STM32H723, PSRAM, TPS54202, TPS2116, INA180, 74LVC1G32, SD-NAND u. a.) – normal.
- **U15 SD-NAND** ist das teuerste Einzelteil: CSNP32GCR01-AOW (4 GB, C2841139) ca. 45 $/Stück (Stand 07.10.2026). Günstiger auf demselben Footprint: **MKDV8GIL-AST** (1 GB, C26159627, ca. 29 $) – reicht für ~14 DD- bzw. ~7 HD-Images. Tausch im BOM-Schritt per „Change Part“.
- **Durchsteckteile (THT)** – günstiger von Hand löten, bei der Teileauswahl abwählen („do not place“):
  J3 (FDD-Power), J4 (SWD), J5 (Debug-UART), J6 (34-pol), J8 (IEC), ab v0.7 auch J14 (Disk II 2×10), J17 (Netzteil), J18 (5-V-Jumper), J19 (Sync-Sensor). Wer sie bestücken lassen will: THT-Assembly zuwählen (Aufpreis).
- **Ohne LCSC-Nummer – selbst besorgen und einlöten:**

| Ref | Teil | Hinweis |
|---|---|---|
| J2 | Hohlstecker 5,5/2,1 mm, liegend | Footprint `BarrelJack_Horizontal` |
| J7 | Wannenstecker 2×12, 2,54 mm | Amiga-Header (Adapterkabel: `docs/Amiga_DB23_Adapter_Cable.md` im Repo-Hauptordner) |
| J9 | Stiftleiste 2×5, 2,54 mm | Erweiterung, optional |
| J11 | Stiftleiste 1×2 + Jumper | WRITE LOCK |
| J12 | Stiftleiste 2×4, 2,54 mm | Front-LEDs im Gehäuse (je LED eine Reihe: ungerade Pin = +, gerade = −) |
| J13 | Stiftleiste 1×3, 2,54 mm | Betriebsart-Schalter im Gehäuse (Kippschalter EIN-AUS-EIN, Kabel 1:1, Mitte = Pin 2) |
| J15 | Stiftleiste 1×2, 2,54 mm | /ENABLE zweites Apple-Laufwerk, optional |
| J16 | Stiftleiste 2×5, 2,54 mm | interner USB-Header, **Stift 9 vor dem Einlöten herausziehen** (im Druck „X“) |

- Testpunkte TP1–TP8 und Lötbrücken JP1/JP2 sind blankes Kupfer – nichts zu bestücken.

### Platzierung prüfen (Viewer-Schritt)
Die Liste `JLC_Rotation_Check.md` nennt alle Teile, deren Drehung im JLC-Viewer kontrolliert werden muss (Pin-1-Punkt am Footprint-Pin-1). Besonders: U5 (MCU), U6–U10, U11 (PSRAM), U12–U14, Q1–Q4, D-Arrays D9–D12, U15 (SD-NAND, LGA-8: Pin-1-Punkt oben links), ab v0.7 U16 (AHCT244), U17, U18 (ICL7662) und D15/D16.
Falsch gedrehte Teile im Viewer per Klick drehen; nichts in KiCad ändern.

## 3 Danach

- Lieferung: [Inbetriebnahme.md](Inbetriebnahme.md) Schritt für Schritt.
- Für die ersten Tests: Schrott-Laufwerk und Schrott-Disketten bereithalten, Labornetzteil mit Strombegrenzung.

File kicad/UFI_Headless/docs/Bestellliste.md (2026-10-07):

# Bestellliste UFI Headless v0.7

Alles, was für ein fertiges Gerät bestellt werden muss. Preise und Lagerbestand: JLCPCB-Teileliste, abgefragt am **07.10.2026** für **2 bestückte Platinen** – vor der Bestellung im JLC-Konfigurator gegenprüfen.
Ablauf der JLC-Bestellung selbst: [Bestellung_JLC.md](Bestellung_JLC.md).

## 1 JLCPCB: Leiterplatte + SMD-Bestückung

Dateien aus dem Release **v0.7**: `UFI_Headless_gerber.zip`, `UFI_Headless-bom-jlc.csv`, `UFI_Headless-cpl-jlc.csv`.

| Posten | Menge | ca. Kosten |
|---|---|---|
| Leiterplatte 4 Lagen, 110 × 97 mm, 1,6 mm, ENIG | 5 (Minimum) | laut Konfigurator |
| SMD-Bestückung „Standard“, eine Seite (156 Bauteile je Platine) | 2 | Setup + Schablone + Lötstellen laut Konfigurator |
| SMD-Bauteile (57 Sorten, davon 32 „Extended“) | für 2 Platinen | **≈ 155 $** |
| Rüstgebühr Extended Parts (≈ 3 $ je Sorte) | 32 Sorten | **≈ 96 $** |

Die teuersten Bauteile (für 2 Platinen):

| Teil | Ref | LCSC | Stück | Einzelpreis | Summe | Lager |
|---|---|---|---|---|---|---|
| SD-NAND 4 GB CSNP32GCR01-AOW | U15 | C2841139 | 2 | 45,64 $ | 91,27 $ | 466 |
| STM32H723ZGT6 | U5 | C730146 | 2 | 11,03 $ | 22,05 $ | 353 |
| PSRAM APS6404L-3SQR-SN | U11 | C5333729 | 2 | 3,97 $ | 7,93 $ | 4573 |
| Taster TL3342F160QG | SW1–SW4 | C2886898 | 8 | 1,04 $ | 8,30 $ | 1786 |
| LDO AP7361C-33E | U4 | C500795 | 2 | 0,81 $ | 1,62 $ | 3492 |

**Sparoption:** U15 durch **MKDV8GIL-AST** (1 GB, C26159627, ≈ 29 $) ersetzen – gleicher Footprint, spart ≈ 33 $ für 2 Platinen, Platz für ≈ 14 DD- bzw. 7 HD-Images.

Knappe Lagerbestände (bei Bestellung prüfen): STM32H723ZGT6 (353), Spule SRN6045TA-150M L1 (189), SD-NAND (466), Elko C5337554 (791).

## 2 Durchsteckteile – bei LCSC mitbestellen, selbst einlöten

In der BOM vorhanden, beim JLC-BOM-Schritt aber **abwählen** („do not place“) und von Hand löten. Bei der Leiterplatte als LCSC-Bestellung mitordern (je 2–5 Stück Reserve).

| Ref | Teil | LCSC | je Platine | ca. Preis |
|---|---|---|---|---|
| J3 | Stiftleiste 1×4, 2,54 mm (Laufwerksstrom) | C32713270 | 1 | 0,03 $ |
| J4 | Stiftleiste 2×5, **1,27 mm** (SWD) | C22438120 | 1 | 0,08 $ |
| J5 | Stiftleiste 1×3, 2,54 mm (Debug-UART) | C49257 | 1 | 0,03 $ |
| J6 | Wannenstecker 2×17, 2,54 mm (34-pol Laufwerk) | C20920 | 1 | 0,28 $ |
| J8 | Stiftleiste 1×6, 2,54 mm (IEC) | C37208 | 1 | 0,04 $ |
| J14 | Wannenstecker 2×10, 2,54 mm (Apple Disk II, v0.7) | C2977593 | 1 | 0,12 $ |
| J17 | Stiftleiste 1×4, 2,54 mm (Netzteil-Eingang, v0.7) | C32713270 | 1 | 0,03 $ |
| J18 | Stiftleiste 1×3, 2,54 mm + **Jumper** (5-V-Quelle, v0.7) | C49257 | 1 | 0,03 $ |
| J19 | Stiftleiste 1×3, 2,54 mm (Disk-II-Sync-Sensor, v0.7) | C49257 | 1 | 0,03 $ |

## 3 Ohne LCSC-Nummer – selbst besorgen

| Ref | Teil | je Platine | Hinweis |
|---|---|---|---|
| J2 | Hohlbuchse 5,5/2,1 mm, liegend, Printmontage | 1 | Footprint `BarrelJack_Horizontal` (Bauform CUI PJ-102A) |
| J7 | Wannenstecker 2×12, 2,54 mm | 1 | Amiga-Anschluss |
| J9 | Stiftleiste 2×5, 2,54 mm | 1 | Erweiterung, optional |
| J11 | Stiftleiste 1×2, 2,54 mm + **Jumper** | 1 | WRITE LOCK – Jumper gesteckt = Schreibschutz |
| J12 | Stiftleiste 2×4, 2,54 mm | 1 | Front-LEDs |
| J13 | Stiftleiste 1×3, 2,54 mm | 1 | Betriebsart-Schalter |
| J15 | Stiftleiste 1×2, 2,54 mm | 1 | /ENABLE zweites Apple-Laufwerk, nur bei Bedarf |
| J16 | Stiftleiste 2×5, 2,54 mm, **Stift 9 vor dem Einlöten herausziehen** | 1 | interner USB-Header; Stift 9 ist die Kodierung des Mainboard-Kabels (Pad 9 bleibt frei) |

Am einfachsten: eine Leiste 2×40 und eine 1×40 (2,54 mm) zum Ablängen, dazu ein paar Jumper.
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

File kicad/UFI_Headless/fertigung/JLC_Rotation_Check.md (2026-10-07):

# JLC-Bestückungsviewer: Orientierung prüfen

Im JLC-Viewer (Schritt *Component Placement*) muss Pin 1 des Bauteilmodells dort liegen, wo er auf der Platine liegt (Draufsicht). Falls nicht: Rotation im Viewer korrigieren und den Offset unten in `scripts/jlc_cpl.py` nachtragen.

| Ref | Wert | Gehäuse | KiCad ° | Offset ° | JLC ° | Pin 1 auf der Platine |
|---|---|---|---|---|---|---|
| C1 | 100uF/25V | CP_Elec_8x10.5 | 0 | +180 | 180 | links |
| C13 | 100uF/25V | CP_Elec_8x10.5 | 0 | +180 | 180 | links |
| D1 | SMF5.0CA | D_SMF | 90 | +0 | 90 | unten |
| D2 | SS54 | D_SMC | 0 | +0 | 0 | links |
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

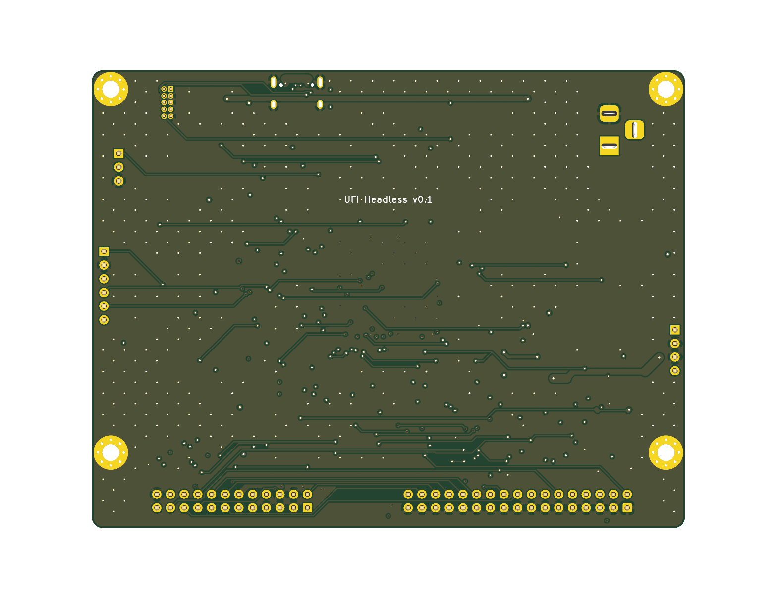
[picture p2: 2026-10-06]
kicad/UFI_Headless/docs/bottom.png

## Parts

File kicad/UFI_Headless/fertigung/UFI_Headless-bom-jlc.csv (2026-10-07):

Comment | Designator | Footprint | LCSC Part #
100uF/25V | C1,C13 | Capacitor_SMD:CP_Elec_8x10.5 | C5337554
10uF/35V | C2 | Capacitor_SMD:C_1206_3216Metric | C454102
100nF/50V | C3 | Capacitor_SMD:C_0603_1608Metric | C14663
100nF | C4,C7,C12,C16-C30,C34,C37,C40-C42,C44-C47,C49-C54 | Capacitor_SMD:C_0603_1608Metric | C14663
22uF/16V | C5,C6 | Capacitor_SMD:C_1206_3216Metric | C90146
1uF | C8-C10,C33 | Capacitor_SMD:C_0603_1608Metric | C15849
22uF/10V | C11 | Capacitor_SMD:C_0805_2012Metric | C45783
10uF | C14,C15,C43,C48 | Capacitor_SMD:C_0805_2012Metric | C15850
4.7uF | C31 | Capacitor_SMD:C_0805_2012Metric | C1779
1uF | C32 | Capacitor_SMD:C_0805_2012Metric | C28323
2.2uF | C35,C36 | Capacitor_SMD:C_0805_2012Metric | C87994
18pF C0G | C38,C39 | Capacitor_SMD:C_0603_1608Metric | C1647
10uF/25V | C55,C56 | Capacitor_SMD:C_1206_3216Metric | C14860
SMF5.0CA | D1,D13,D17 | Diode_SMD:D_SMF | C2980402
SS54 | D2 | Diode_SMD:D_SMC | C16103
SMAJ15CA | D3,D14 | Diode_SMD:D_SMA | C110044
green | D4-D6 | LED_SMD:LED_0603_1608Metric | C12624
red | D7 | LED_SMD:LED_0603_1608Metric | C2286
green PWR | D8 | LED_SMD:LED_0603_1608Metric | C12624
ESDA6V1-5SC6 | D9-D12,D15,D16 | Package_TO_SOT_SMD:SOT-23-6 | C6650
1.5A hold | F1,F4 | Fuse:Fuse_1812_4532Metric | C32404
1.1A hold 6V | F2 | Fuse:Fuse_1206_3216Metric | C20801
1.1A hold 24V | F3 | Fuse:Fuse_1812_4532Metric | C20999
600R@100MHz | FB1 | Inductor_SMD:L_0603_1608Metric | C1002
USB-C | J1 | Connector_USB:USB_C_Receptacle_HRO_TYPE-C-31-M-12 | C165948
12V DC 5.5/2.1 | J2 | Connector_BarrelJack:BarrelJack_Horizontal
FDD_PWR | J3 | Connector_PinHeader_2.54mm:PinHeader_1x04_P2.54mm_Vertical | C32713270
SWD | J4 | Connector_PinHeader_1.27mm:PinHeader_2x05_P1.27mm_Vertical | C22438120
DBG_UART | J5 | Connector_PinHeader_2.54mm:PinHeader_1x03_P2.54mm_Vertical | C49257
FDD_34PIN | J6 | Connector_IDC:IDC-Header_2x17_P2.54mm_Vertical | C20920
AMIGA_FDD | J7 | Connector_IDC:IDC-Header_2x12_P2.54mm_Vertical
IEC_HDR | J8 | Connector_PinHeader_2.54mm:PinHeader_1x06_P2.54mm_Vertical | C37208
EXPANSION | J9 | Connector_PinHeader_2.54mm:PinHeader_2x05_P2.54mm_Vertical
WRITE_LOCK | J11 | Connector_PinHeader_2.54mm:PinHeader_1x02_P2.54mm_Vertical
FRONT_LED | J12 | Connector_PinHeader_2.54mm:PinHeader_2x04_P2.54mm_Vertical
MODE_SW | J13 | Connector_PinHeader_2.54mm:PinHeader_1x03_P2.54mm_Vertical
DISK_II | J14 | UFI_Headless:IDC-Header_2x10_P2.54mm_Vertical_UFI | C2977593
APPLE_EN2 | J15 | Connector_PinHeader_2.54mm:PinHeader_1x02_P2.54mm_Vertical
USB_HDR | J16 | Connector_PinHeader_2.54mm:PinHeader_2x05_P2.54mm_Vertical
PSU_IN | J17 | Connector_PinHeader_2.54mm:PinHeader_1x04_P2.54mm_Vertical | C32713270
5V_SEL | J18 | Connector_PinHeader_2.54mm:PinHeader_1x03_P2.54mm_Vertical | C49257
SYNC_SENSOR | J19 | Connector_PinHeader_2.54mm:PinHeader_1x03_P2.54mm_Vertical | C49257
15uH 3A | L1 | Inductor_SMD:L_Bourns_SRN6045TA | C1330797
AO3401A | Q1,Q3 | Package_TO_SOT_SMD:SOT-23 | C15127
2N7002 | Q2,Q4 | Package_TO_SOT_SMD:SOT-23 | C8545
5.1k | R1,R2 | Resistor_SMD:R_0603_1608Metric | C23186
100k 1% | R3 | Resistor_SMD:R_0603_1608Metric | C25803
13.3k 1% | R4 | Resistor_SMD:R_0603_1608Metric | C25952
33k 1% | R5 | Resistor_SMD:R_0603_1608Metric | C4216
10k 1% | R6 | Resistor_SMD:R_0603_1608Metric | C25804
10k | R7,R8,R16,R17,R30,R32,R38,R39 | Resistor_SMD:R_0603_1608Metric | C25804
22k | R9 | Resistor_SMD:R_0603_1608Metric | C31850
33k | R10 | Resistor_SMD:R_0603_1608Metric | C4216
1k | R11-R14 | Resistor_SMD:R_0603_1608Metric | C21190
2.2k | R15,R18-R20 | Resistor_SMD:R_0603_1608Metric | C4190
47k | R21-R25 | Resistor_SMD:R_0603_1608Metric | C25819
0.1R 1% | R26,R29 | Resistor_SMD:R_1206_3216Metric | C25334
100k | R27,R28,R31,R33 | Resistor_SMD:R_0603_1608Metric | C25803
330 | R34-R37 | Resistor_SMD:R_0603_1608Metric | C23138
1k | RN1-RN8 | Resistor_SMD:R_Array_Convex_4x0603 | C20197
10k | RN9,RN10 | Resistor_SMD:R_Array_Convex_4x0603 | C29718
RESET | SW1 | Button_Switch_SMD:SW_SPST_TL3342 | C2886898
BOOT | SW2 | Button_Switch_SMD:SW_SPST_TL3342 | C2886898
BTN_A | SW3 | Button_Switch_SMD:SW_SPST_TL3342 | C2886898
BTN_B | SW4 | Button_Switch_SMD:SW_SPST_TL3342 | C2886898
USBLC6-2SC6 | U1 | Package_TO_SOT_SMD:SOT-23-6 | C7519
TPS54202DDC | U2 | Package_TO_SOT_SMD:SOT-23-6 | C191884
TPS2116DRL | U3 | Package_TO_SOT_SMD:SOT-583-8 | C3235557
AP7361C-33E | U4 | Package_TO_SOT_SMD:SOT-223-3_TabPin2 | C500795
STM32H723ZGT6 | U5 | Package_QFP:LQFP-144_20x20mm_P0.5mm | C730146
SN74LS07D | U6,U7,U9 | Package_SO:SOIC-14_3.9x8.7mm_P1.27mm | C371970
74LVC14AD | U8,U10 | Package_SO:SOIC-14_3.9x8.7mm_P1.27mm | C133541
APS6404L-3SQR-SN | U11 | Package_SO:SOIC-8_3.9x4.9mm_P1.27mm | C5333729
INA180A1 | U12,U13 | Package_TO_SOT_SMD:SOT-23-5 | C122228
74LVC1G32GW | U14 | Package_TO_SOT_SMD:SOT-353_SC-70-5 | C12516
CSNP32GCR01-AOW | U15 | UFI_Headless:SD_NAND_LGA-8_6x8mm_P1.27mm | C2841139
SN74AHCT244PWR | U16 | Package_SO:TSSOP-20_4.4x6.5mm_P0.65mm | C484743
74LVC2G17GW | U17 | Package_TO_SOT_SMD:SOT-363_SC-70-6 | C19829576
ICL7662EBA+T | U18 | Package_SO:SOIC-8_3.9x4.9mm_P1.27mm | C28595
25MHz CL=12pF | Y1 | Crystal:Crystal_SMD_3225-4Pin_3.2x2.5mm | C9006

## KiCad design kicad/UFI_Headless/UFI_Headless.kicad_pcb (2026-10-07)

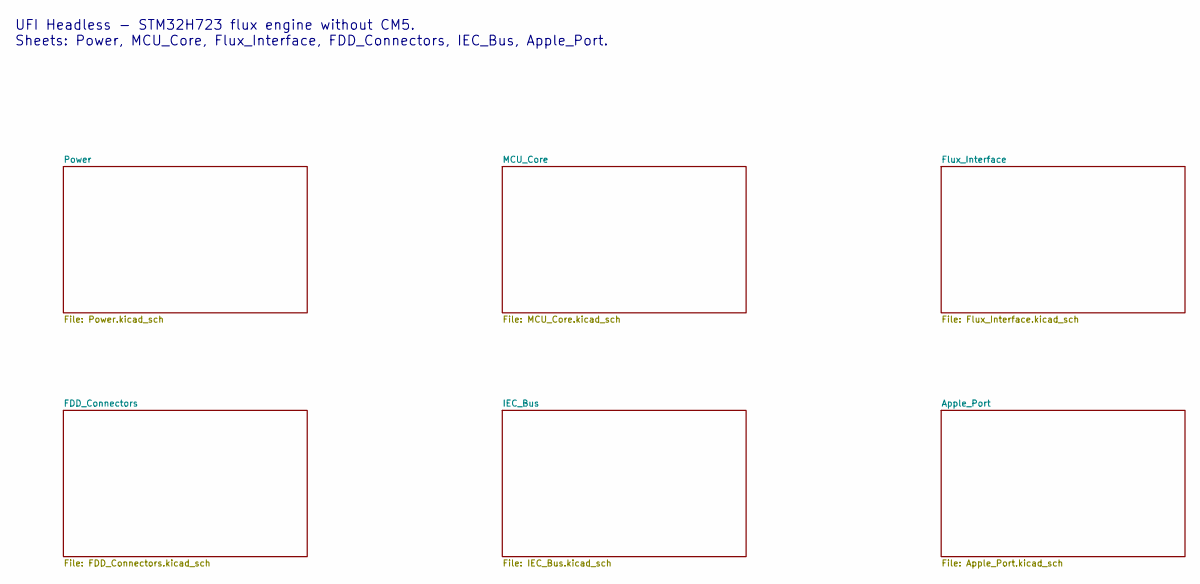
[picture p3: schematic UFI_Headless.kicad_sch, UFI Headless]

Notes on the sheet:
UFI Headless - STM32H723 flux engine without CM5. Sheets: Power, MCU_Core, Flux_Interface, FDD_Connectors, IEC_Bus, Apple_Port.

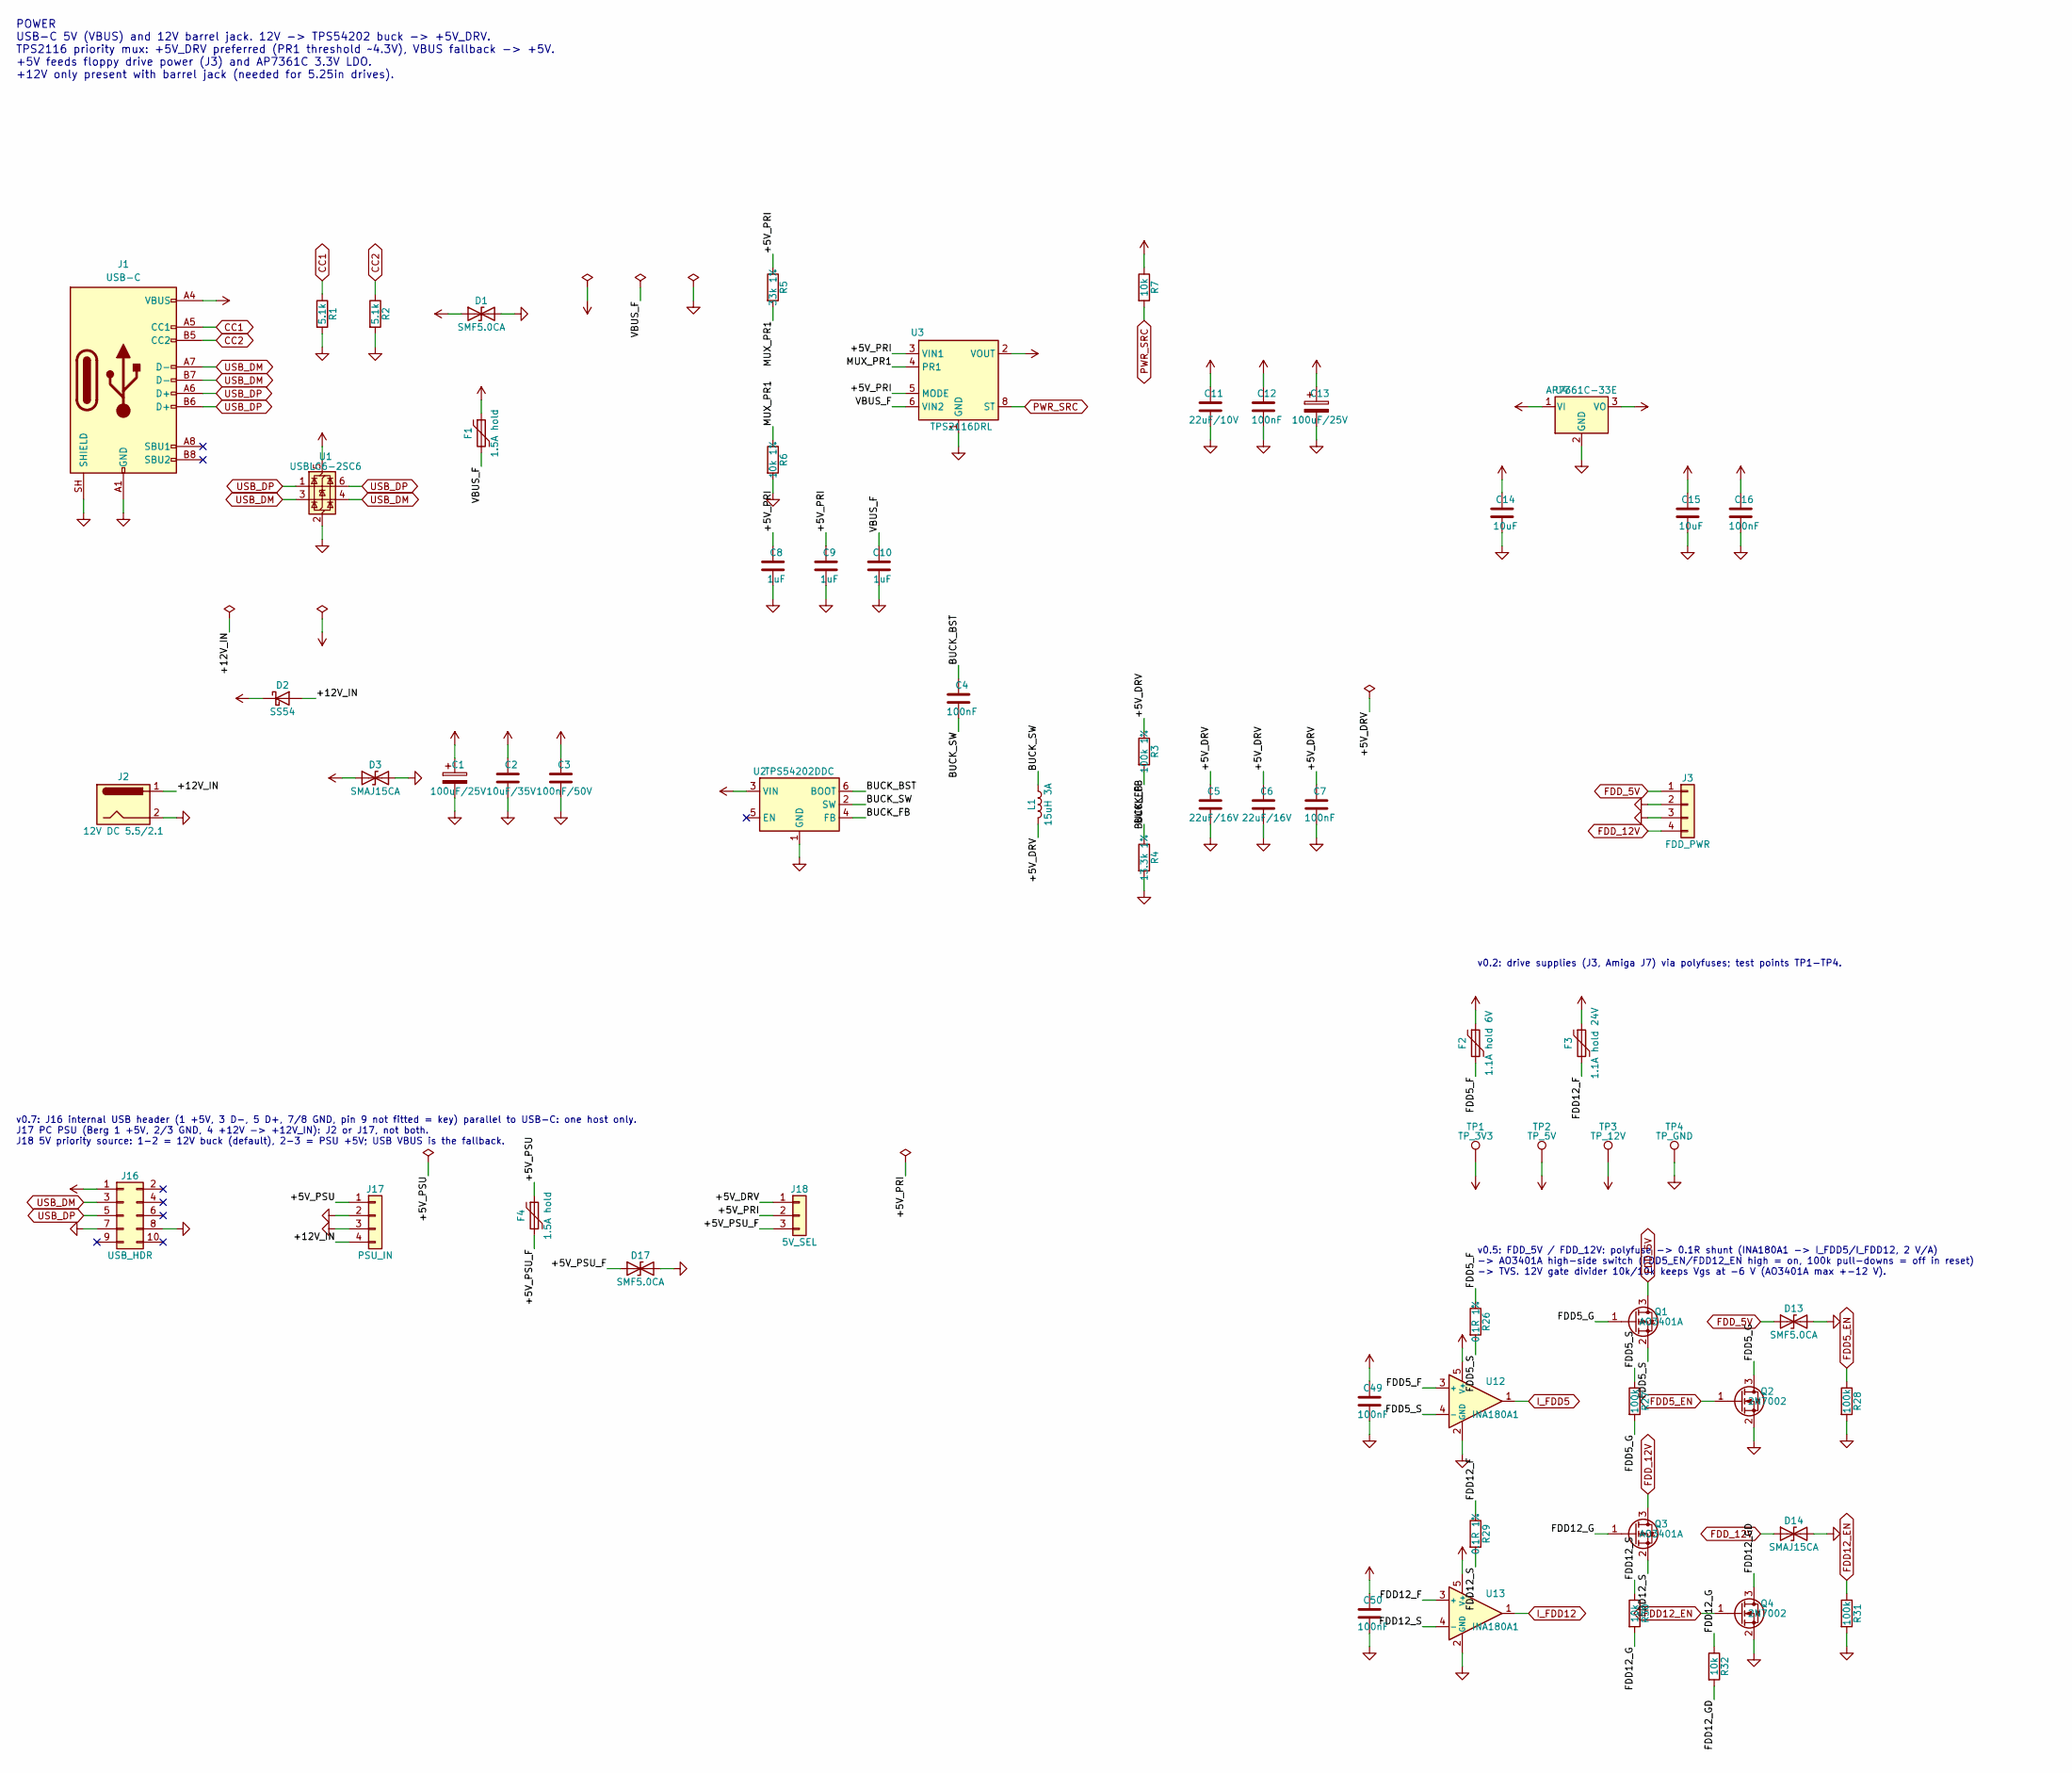
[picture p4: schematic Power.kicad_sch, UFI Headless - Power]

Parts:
C1, C13: 100uF/25V; CP_Elec_8x10.5; LCSC C5337554
C2: 10uF/35V; C_1206_3216Metric; LCSC C454102
C3: 100nF/50V; C_0603_1608Metric; LCSC C14663
C4, C7, C12, C16, C49, C50: 100nF; C_0603_1608Metric; LCSC C14663
C5, C6: 22uF/16V; C_1206_3216Metric; LCSC C90146
C8, C9, C10: 1uF; C_0603_1608Metric; LCSC C15849
C11: 22uF/10V; C_0805_2012Metric; LCSC C45783
C14, C15: 10uF; C_0805_2012Metric; LCSC C15850
D1, D13, D17: SMF5.0CA; D_SMF; MPN SMF5.0CA; LCSC C2980402
D2: SS54; D_SMC; MPN SS54C (40V/5A); LCSC C16103
D3, D14: SMAJ15CA; D_SMA; MPN SMAJ15CA; LCSC C110044
F1, F4: 1.5A hold; Fuse_1812_4532Metric; MPN SMD1812P150TF/24 (1.5A hold); LCSC C32404
F2: 1.1A hold 6V; Fuse_1206_3216Metric; MPN SMD1206P110TF (1.1A hold, 6V); LCSC C20801
F3: 1.1A hold 24V; Fuse_1812_4532Metric; MPN SMD1812P110TF/24 (1.1A hold, 24V); LCSC C20999
J1: USB-C; USB_C_Receptacle_HRO_TYPE-C-31-M-12; MPN HRO TYPE-C-31-M-12; LCSC C165948
J2: 12V DC 5.5/2.1; BarrelJack_Horizontal
J3: FDD_PWR; PinHeader_1x04_P2.54mm_Vertical; LCSC C32713270
J16: USB_HDR; PinHeader_2x05_P2.54mm_Vertical
J17: PSU_IN; PinHeader_1x04_P2.54mm_Vertical; LCSC C32713270
J18: 5V_SEL; PinHeader_1x03_P2.54mm_Vertical; LCSC C49257
L1: 15uH 3A; L_Bourns_SRN6045TA; MPN Bourns SRN6045TA-150M; LCSC C1330797
Q1, Q3: AO3401A; SOT-23; LCSC C15127
Q2, Q4: 2N7002; SOT-23; LCSC C8545
R1, R2: 5.1k; R_0603_1608Metric; LCSC C23186
R3: 100k 1%; R_0603_1608Metric; LCSC C25803
R4: 13.3k 1%; R_0603_1608Metric; LCSC C25952
R5: 33k 1%; R_0603_1608Metric; LCSC C4216
R6: 10k 1%; R_0603_1608Metric; LCSC C25804
R7, R30, R32: 10k; R_0603_1608Metric; LCSC C25804
R26, R29: 0.1R 1%; R_1206_3216Metric; MPN 1206W4F100LT5E (0.1R 1% 1/4W); LCSC C25334
R27, R28, R31: 100k; R_0603_1608Metric; LCSC C25803
TP1: TP_3V3; TestPoint_Pad_D1.5mm
TP2: TP_5V; TestPoint_Pad_D1.5mm
TP3: TP_12V; TestPoint_Pad_D1.5mm
TP4: TP_GND; TestPoint_Pad_D1.5mm
U1: USBLC6-2SC6; SOT-23-6; MPN USBLC6-2SC6; LCSC C7519
U2: TPS54202DDC; SOT-23-6; MPN TPS54202DDCR; LCSC C191884
U3: TPS2116DRL; SOT-583-8; MPN TPS2116DRLR; LCSC C3235557
U4: AP7361C-33E; SOT-223-3_TabPin2; MPN AP7361C-33E-13; LCSC C500795
U12, U13: INA180A1; SOT-23-5; MPN INA180A1IDBVR; LCSC C122228

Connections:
+3V3: C15.1, C16.1, C49.1, C50.1, R7.1, TP1.1, U4.3 (VO), U12.5 (V+), U13.5 (V+); also elsewhere on the board
+5V: C11.1, C12.1, C13.1, C14.1, F2.1, TP2.1, U3.2 (VOUT), U3.7 (VOUT), U4.1 (VI); also elsewhere on the board
+12V: C1.1, C2.1, C3.1, D2.1 (K), D3.1 (A1), F3.1, TP3.1, U2.3 (VIN)
/Power/+5V_DRV: C5.1, C6.1, C7.1, J18.1, L1.2, R3.1
/Power/+5V_PRI: C8.1, C9.1, J18.2, R5.1, U3.3 (VIN1), U3.5 (MODE)
/Power/+5V_PSU: F4.1, J17.1
/Power/+5V_PSU_F: D17.1 (A1), F4.2, J18.3
/Power/+12V_IN: D2.2 (A), J2.1, J17.4
/Power/BUCK_BST: C4.1, U2.6 (BOOT)
/Power/BUCK_FB: R3.2, R4.1, U2.4 (FB)
/Power/BUCK_SW: C4.2, L1.1, U2.2 (SW)
/Power/FDD5_F: F2.2, R26.1, U12.3 (+)
/Power/FDD5_G: Q1.1 (G), Q2.3 (D), R27.2
/Power/FDD5_S: Q1.2 (S), R26.2, R27.1, U12.4 (-)
/Power/FDD12_F: F3.2, R29.1, U13.3 (+)
/Power/FDD12_G: Q3.1 (G), R30.2, R32.1
/Power/FDD12_GD: Q4.3 (D), R32.2
/Power/FDD12_S: Q3.2 (S), R29.2, R30.1, U13.4 (-)
/Power/MUX_PR1: R5.2, R6.1, U3.4 (PR1)
/Power/VBUS_F: C10.1, F1.2, U3.6 (VIN2)
CC1: J1.A5 (CC1), R1.1; also elsewhere on the board
CC2: J1.B5 (CC2), R2.1; also elsewhere on the board
FDD5_EN: Q2.1 (G), R28.1; also elsewhere on the board
FDD12_EN: Q4.1 (G), R31.1; also elsewhere on the board
FDD_5V: D13.1 (A1), J3.1, Q1.3 (D); also elsewhere on the board
FDD_12V: D14.1 (A1), J3.4, Q3.3 (D); also elsewhere on the board
GND: C1.2, C2.2, C3.2, C5.2, C6.2, C7.2, C8.2, C9.2, C10.2, C11.2, C12.2, C13.2, C14.2, C15.2, C16.2, C49.2, C50.2, D1.2 (A2), D3.2 (A2), D13.2 (A2), D14.2 (A2), D17.2 (A2), J1.A1 (GND), J1.A12 (GND), J1.B1 (GND), J1.B12 (GND), J1.SH (SHIELD), J2.2, J3.2, J3.3, J16.7, J16.8, J17.2, J17.3, Q2.2 (S), Q4.2 (S), R1.2, R2.2, R4.2, R6.2, R28.2, R31.2, TP4.1, U1.2 (GND), U2.1 (GND), U3.1 (GND), U4.2 (GND), U12.2 (GND), U13.2 (GND); also elsewhere on the board
I_FDD5: U12.1; also elsewhere on the board
I_FDD12: U13.1; also elsewhere on the board
PWR_SRC: R7.2, U3.8 (ST); also elsewhere on the board
USB_DM: J1.A7 (D-), J1.B7 (D-), J16.3, U1.3 (I/O2), U1.4 (I/O2); also elsewhere on the board
USB_DP: J1.A6 (D+), J1.B6 (D+), J16.5, U1.1 (I/O1), U1.6 (I/O1); also elsewhere on the board
VBUS: D1.1 (A1), F1.1, J1.A4 (VBUS), J1.A9 (VBUS), J1.B4 (VBUS), J1.B9 (VBUS), J16.1, U1.5 (VBUS); also elsewhere on the board

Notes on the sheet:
POWER USB-C 5V (VBUS) and 12V barrel jack. 12V -> TPS54202 buck -> +5V_DRV. TPS2116 priority mux: +5V_DRV preferred (PR1 threshold ~4.3V), VBUS fallback -> +5V. +5V feeds floppy drive power (J3) and AP7361C 3.3V LDO. +12V only present with barrel jack (needed for 5.25in drives).
v0.7: J16 internal USB header (1 +5V, 3 D-, 5 D+, 7/8 GND, pin 9 not fitted = key) parallel to USB-C: one host only. J17 PC PSU (Berg 1 +5V, 2/3 GND, 4 +12V -> +12V_IN): J2 or J17, not both. J18 5V priority source: 1-2 = 12V buck (default), 2-3 = PSU +5V; USB VBUS is the fallback.
v0.2: drive supplies (J3, Amiga J7) via polyfuses; test points TP1-TP4.
v0.5: FDD_5V / FDD_12V: polyfuse -> 0.1R shunt (INA180A1 -> I_FDD5/I_FDD12, 2 V/A) -> AO3401A high-side switch (FDD5_EN/FDD12_EN high = on, 100k pull-downs = off in reset) -> TVS. 12V gate divider 10k/10k keeps Vgs at -6 V (AO3401A max +-12 V).

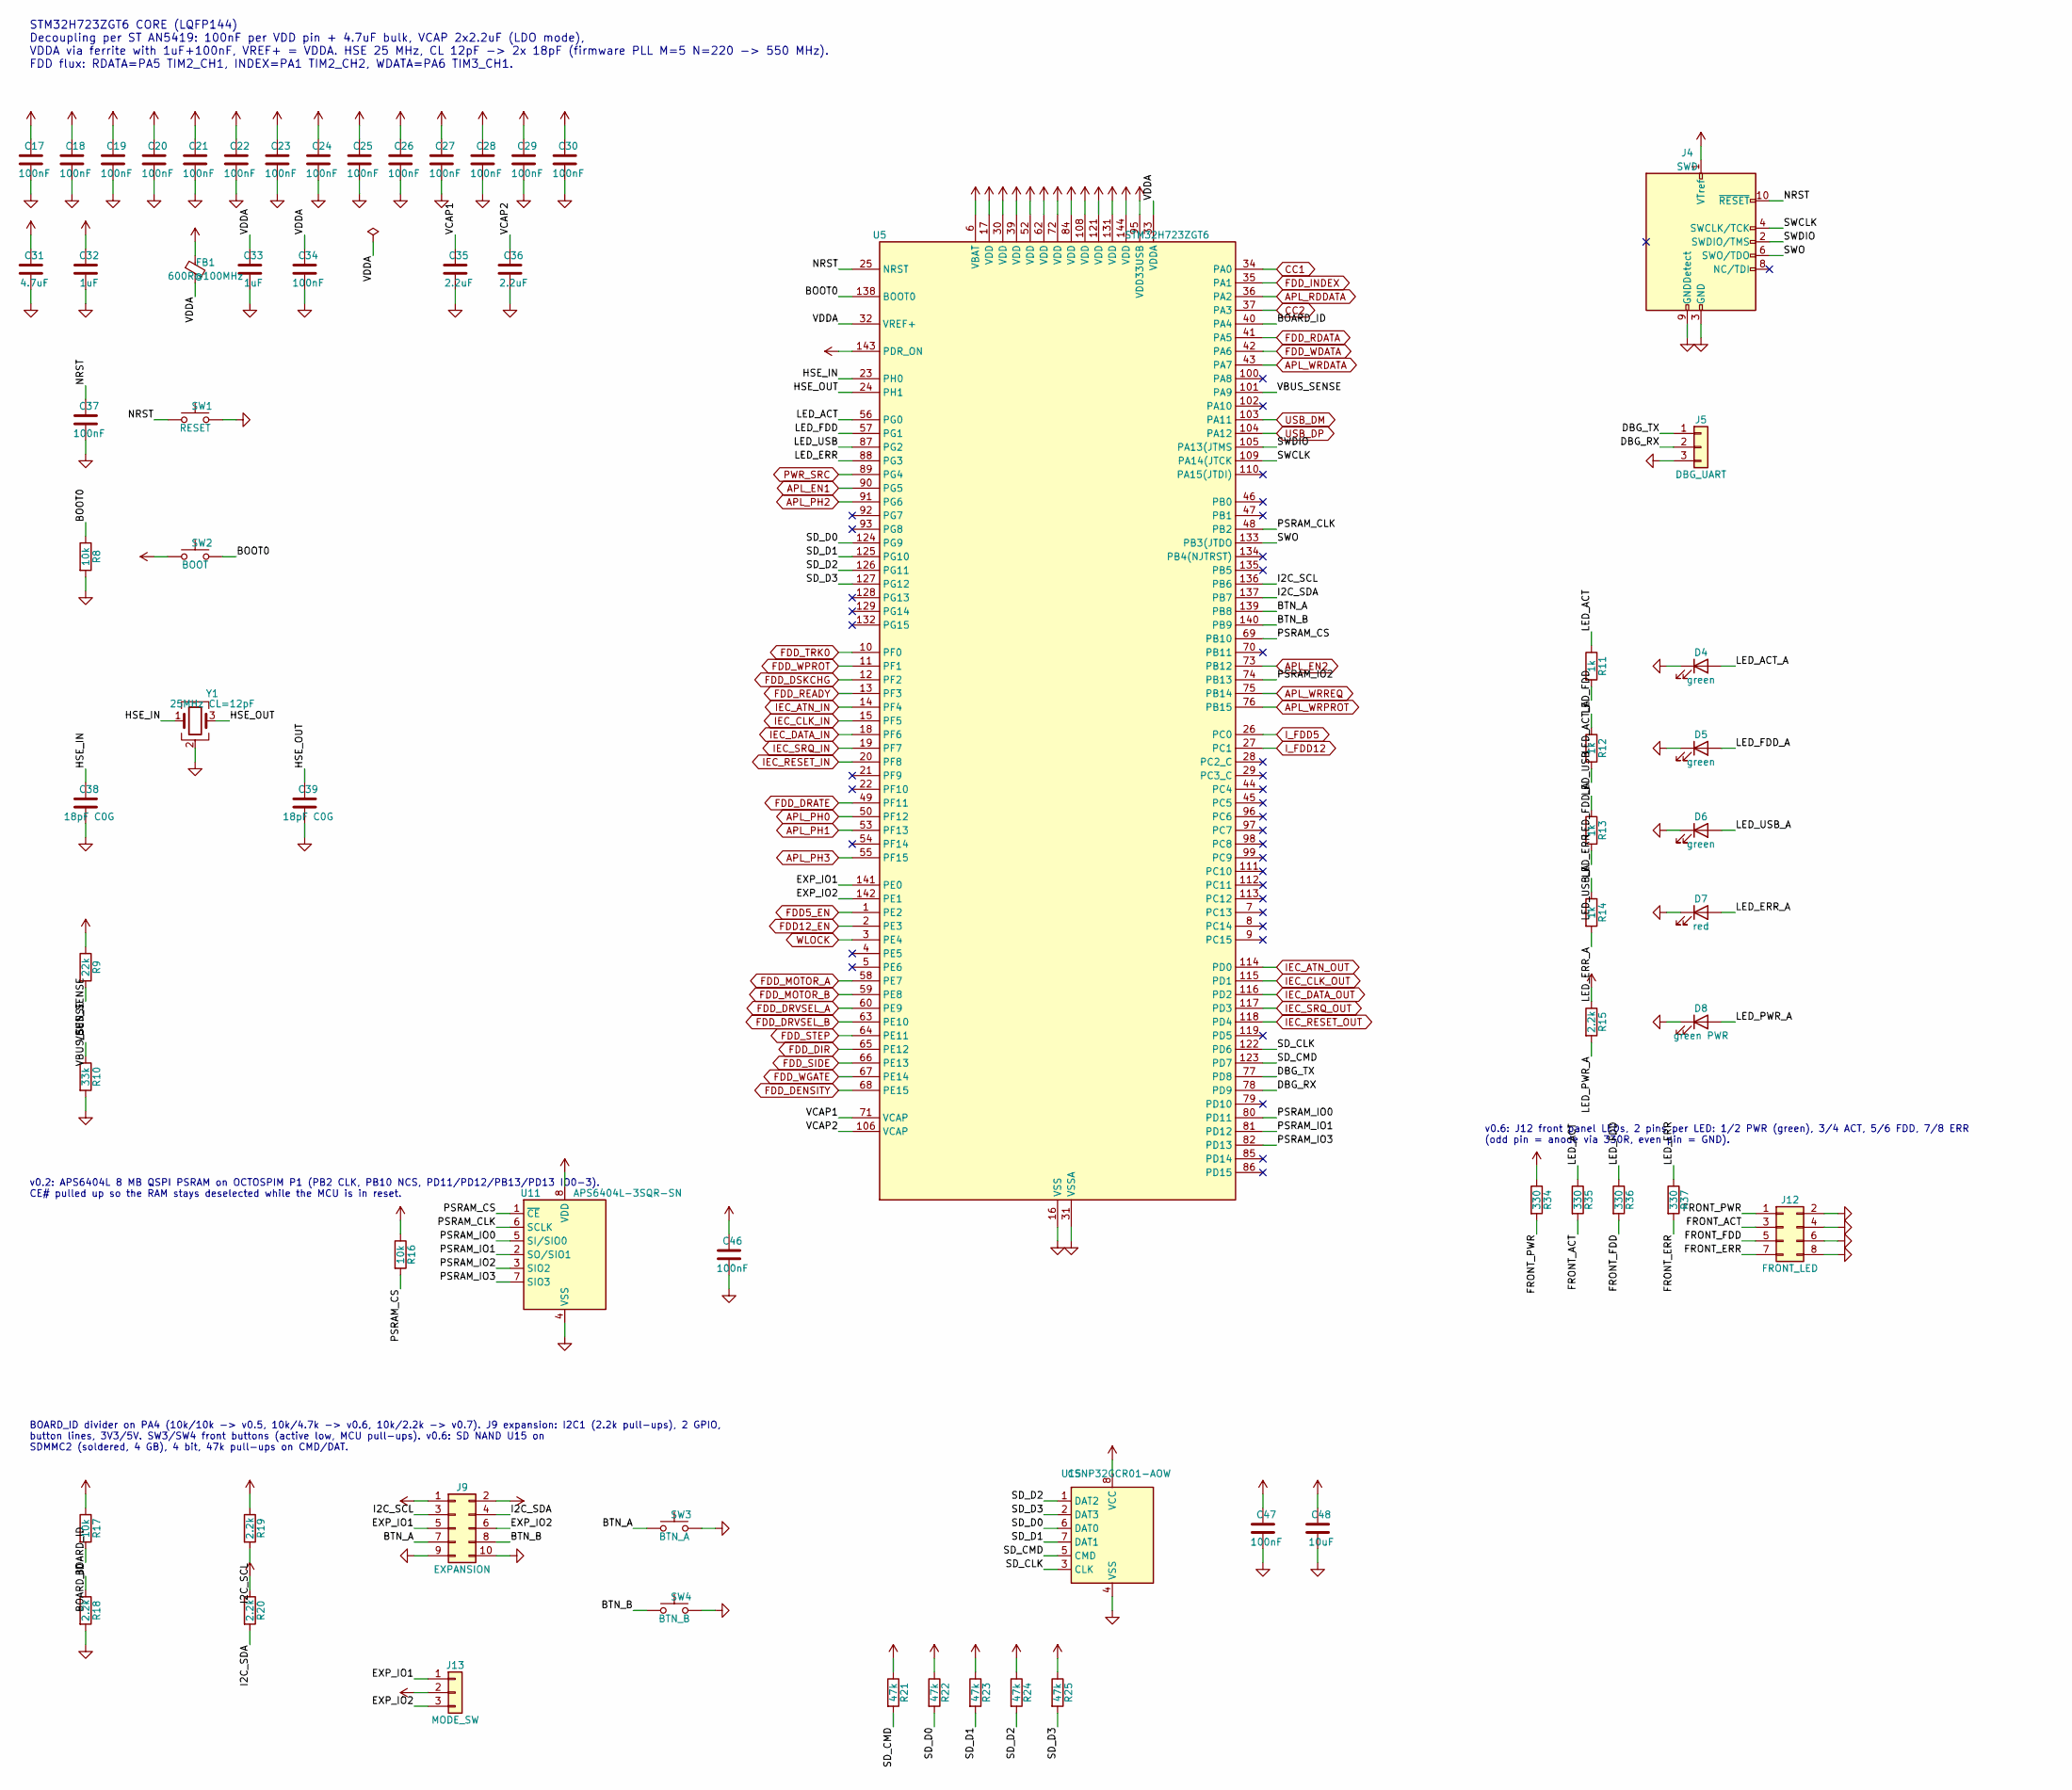
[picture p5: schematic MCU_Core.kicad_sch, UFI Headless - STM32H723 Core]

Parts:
C17, C18, C19, C20, C21, C22, C23, C24, C25, C26, C27, C28, C29, C30, C34, C37, C46, C47: 100nF; C_0603_1608Metric; LCSC C14663
C31: 4.7uF; C_0805_2012Metric; LCSC C1779
C32: 1uF; C_0805_2012Metric; LCSC C28323
C33: 1uF; C_0603_1608Metric; LCSC C15849
C35, C36: 2.2uF; C_0805_2012Metric; LCSC C87994
C38, C39: 18pF C0G; C_0603_1608Metric; LCSC C1647
C48: 10uF; C_0805_2012Metric; LCSC C15850
D4, D5, D6: green; LED_0603_1608Metric; LCSC C12624
D7: red; LED_0603_1608Metric; LCSC C2286
D8: green PWR; LED_0603_1608Metric; LCSC C12624
FB1: 600R@100MHz; L_0603_1608Metric; LCSC C1002
J4: SWD; PinHeader_2x05_P1.27mm_Vertical; LCSC C22438120
J5: DBG_UART; PinHeader_1x03_P2.54mm_Vertical; LCSC C49257
J9: EXPANSION; PinHeader_2x05_P2.54mm_Vertical
J12: FRONT_LED; PinHeader_2x04_P2.54mm_Vertical
J13: MODE_SW; PinHeader_1x03_P2.54mm_Vertical
R8, R16, R17: 10k; R_0603_1608Metric; LCSC C25804
R9: 22k; R_0603_1608Metric; LCSC C31850
R10: 33k; R_0603_1608Metric; LCSC C4216
R11, R12, R13, R14: 1k; R_0603_1608Metric; LCSC C21190
R15, R18, R19, R20: 2.2k; R_0603_1608Metric; LCSC C4190
R21, R22, R23, R24, R25: 47k; R_0603_1608Metric; LCSC C25819
R34, R35, R36, R37: 330; R_0603_1608Metric; LCSC C23138
SW1: RESET; SW_SPST_TL3342; LCSC C2886898
SW2: BOOT; SW_SPST_TL3342; LCSC C2886898
SW3: BTN_A; SW_SPST_TL3342; LCSC C2886898
SW4: BTN_B; SW_SPST_TL3342; LCSC C2886898
U5: STM32H723ZGT6; LQFP-144_20x20mm_P0.5mm; MPN STM32H723ZGT6; LCSC C730146
U11: APS6404L-3SQR-SN; SOIC-8_3.9x4.9mm_P1.27mm; MPN APS6404L-3SQR-SN; LCSC C5333729
U15: CSNP32GCR01-AOW; SD_NAND_LGA-8_6x8mm_P1.27mm; MPN CSNP32GCR01-AOW; LCSC C2841139
Y1: 25MHz CL=12pF; Crystal_SMD_3225-4Pin_3.2x2.5mm; MPN YXC X322525MOB4SI (25MHz, CL 12pF, +-10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; LCSC C9006

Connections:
+3V3: C17.1, C18.1, C19.1, C20.1, C21.1, C22.1, C23.1, C24.1, C25.1, C26.1, C27.1, C28.1, C29.1, C30.1, C31.1, C32.1, C46.1, C47.1, C48.1, FB1.1, J4.1 (VTref), J9.1, J13.2, R15.1, R16.1, R17.1, R19.1, R20.1, R21.1, R22.1, R23.1, R24.1, R25.1, R34.1, SW2.1, U5.6 (VBAT), U5.17 (VDD), U5.30 (VDD), U5.39 (VDD), U5.52 (VDD), U5.62 (VDD), U5.72 (VDD), U5.84 (VDD), U5.95 (VDD33USB), U5.108 (VDD), U5.121 (VDD), U5.131 (VDD), U5.143 (PDR_ON), U5.144 (VDD), U11.8 (VDD), U15.8 (VCC); also elsewhere on the board
+5V: J9.2; also elsewhere on the board
/MCU_Core/BOARD_ID: R17.2, R18.1, U5.40 (PA4)
/MCU_Core/BOOT0: R8.1, SW2.2, U5.138 (BOOT0)
/MCU_Core/BTN_A: J9.7, SW3.1, U5.139 (PB8)
/MCU_Core/BTN_B: J9.8, SW4.1, U5.140 (PB9)
/MCU_Core/DBG_RX: J5.2, U5.78 (PD9)
/MCU_Core/DBG_TX: J5.1, U5.77 (PD8)
/MCU_Core/EXP_IO1: J9.5, J13.1, U5.141 (PE0)
/MCU_Core/EXP_IO2: J9.6, J13.3, U5.142 (PE1)
/MCU_Core/FRONT_ACT: J12.3, R35.2
/MCU_Core/FRONT_ERR: J12.7, R37.2
/MCU_Core/FRONT_FDD: J12.5, R36.2
/MCU_Core/FRONT_PWR: J12.1, R34.2
/MCU_Core/HSE_IN: C38.1, U5.23 (PH0), Y1.1
/MCU_Core/HSE_OUT: C39.1, U5.24 (PH1), Y1.3
/MCU_Core/I2C_SCL: J9.3, R19.2, U5.136 (PB6)
/MCU_Core/I2C_SDA: J9.4, R20.2, U5.137 (PB7)
/MCU_Core/LED_ACT: R11.1, R35.1, U5.56 (PG0)
/MCU_Core/LED_ACT_A: D4.2 (A), R11.2
/MCU_Core/LED_ERR: R14.1, R37.1, U5.88 (PG3)
/MCU_Core/LED_ERR_A: D7.2 (A), R14.2
/MCU_Core/LED_FDD: R12.1, R36.1, U5.57 (PG1)
/MCU_Core/LED_FDD_A: D5.2 (A), R12.2
/MCU_Core/LED_PWR_A: D8.2 (A), R15.2
/MCU_Core/LED_USB: R13.1, U5.87 (PG2)
/MCU_Core/LED_USB_A: D6.2 (A), R13.2
/MCU_Core/NRST: C37.1, J4.10 (~RESET), SW1.1, U5.25 (NRST)
/MCU_Core/PSRAM_CLK: U5.48 (PB2), U11.6 (SCLK)
/MCU_Core/PSRAM_CS: R16.2, U5.69 (PB10), U11.1 (~CE)
/MCU_Core/PSRAM_IO0: U5.80 (PD11), U11.5 (SI/SIO0)
/MCU_Core/PSRAM_IO1: U5.81 (PD12), U11.2 (SO/SIO1)
/MCU_Core/PSRAM_IO2: U5.74 (PB13), U11.3 (SIO2)
/MCU_Core/PSRAM_IO3: U5.82 (PD13), U11.7 (SIO3)
/MCU_Core/SD_CLK: U5.122 (PD6), U15.3 (CLK)
/MCU_Core/SD_CMD: R21.2, U5.123 (PD7), U15.5 (CMD)
/MCU_Core/SD_D0: R22.2, U5.124 (PG9), U15.6 (DAT0)
/MCU_Core/SD_D1: R23.2, U5.125 (PG10), U15.7 (DAT1)
/MCU_Core/SD_D2: R24.2, U5.126 (PG11), U15.1 (DAT2)
/MCU_Core/SD_D3: R25.2, U5.127 (PG12), U15.2 (DAT3)
/MCU_Core/SWCLK: J4.4 (SWCLK/TCK), U5.109 (PA14(JTCK)
/MCU_Core/SWDIO: J4.2 (SWDIO/TMS), U5.105 (PA13(JTMS)
/MCU_Core/SWO: J4.6 (SWO/TDO), U5.133 (PB3(JTDO)
/MCU_Core/VBUS_SENSE: R9.2, R10.1, U5.101 (PA9)
/MCU_Core/VCAP1: C35.1, U5.71 (VCAP)
/MCU_Core/VCAP2: C36.1, U5.106 (VCAP)
/MCU_Core/VDDA: C33.1, C34.1, FB1.2, U5.32 (VREF+), U5.33 (VDDA)
APL_EN1: U5.90 (PG5); also elsewhere on the board
APL_EN2: U5.73 (PB12); also elsewhere on the board
APL_PH0: U5.50 (PF12); also elsewhere on the board
APL_PH1: U5.53 (PF13); also elsewhere on the board
APL_PH2: U5.91 (PG6); also elsewhere on the board
APL_PH3: U5.55 (PF15); also elsewhere on the board
APL_RDDATA: U5.36 (PA2); also elsewhere on the board
APL_WRDATA: U5.43 (PA7); also elsewhere on the board
APL_WRPROT: U5.76 (PB15); also elsewhere on the board
APL_WRREQ: U5.75 (PB14); also elsewhere on the board
CC1: U5.34 (PA0); also elsewhere on the board
CC2: U5.37 (PA3); also elsewhere on the board
FDD5_EN: U5.1 (PE2); also elsewhere on the board
FDD12_EN: U5.2 (PE3); also elsewhere on the board
FDD_DENSITY: U5.68 (PE15); also elsewhere on the board
FDD_DIR: U5.65 (PE12); also elsewhere on the board
FDD_DRATE: U5.49 (PF11); also elsewhere on the board
FDD_DRVSEL_A: U5.60 (PE9); also elsewhere on the board
FDD_DRVSEL_B: U5.63 (PE10); also elsewhere on the board
FDD_DSKCHG: U5.12 (PF2); also elsewhere on the board
FDD_INDEX: U5.35 (PA1); also elsewhere on the board
FDD_MOTOR_A: U5.58 (PE7); also elsewhere on the board
FDD_MOTOR_B: U5.59 (PE8); also elsewhere on the board
FDD_RDATA: U5.41 (PA5); also elsewhere on the board
FDD_READY: U5.13 (PF3); also elsewhere on the board
FDD_SIDE: U5.66 (PE13); also elsewhere on the board
FDD_STEP: U5.64 (PE11); also elsewhere on the board
FDD_TRK0: U5.10 (PF0); also elsewhere on the board
FDD_WDATA: U5.42 (PA6); also elsewhere on the board
FDD_WGATE: U5.67 (PE14); also elsewhere on the board
FDD_WPROT: U5.11 (PF1); also elsewhere on the board
GND: C17.2, C18.2, C19.2, C20.2, C21.2, C22.2, C23.2, C24.2, C25.2, C26.2, C27.2, C28.2, C29.2, C30.2, C31.2, C32.2, C33.2, C34.2, C35.2, C36.2, C37.2, C38.2, C39.2, C46.2, C47.2, C48.2, D4.1 (K), D5.1 (K), D6.1 (K), D7.1 (K), D8.1 (K), J4.3 (GND), J4.5 (GND), J4.9 (GNDDetect), J5.3, J9.9, J9.10, J12.2, J12.4, J12.6, J12.8, R8.2, R10.2, R18.2, SW1.2, SW3.2, SW4.2, U5.16 (VSS), U5.31 (VSSA), U5.38 (VSS), U5.51 (VSS), U5.61 (VSS), U5.83 (VSS), U5.94 (VSS), U5.107 (VSS), U5.120 (VSS), U5.130 (VSS), U11.4 (VSS), U15.4 (VSS), Y1.2 (G), Y1.4 (G); also elsewhere on the board
IEC_ATN_IN: U5.14 (PF4); also elsewhere on the board
IEC_ATN_OUT: U5.114 (PD0); also elsewhere on the board
IEC_CLK_IN: U5.15 (PF5); also elsewhere on the board
IEC_CLK_OUT: U5.115 (PD1); also elsewhere on the board
IEC_DATA_IN: U5.18 (PF6); also elsewhere on the board
IEC_DATA_OUT: U5.116 (PD2); also elsewhere on the board
IEC_RESET_IN: U5.20 (PF8); also elsewhere on the board
IEC_RESET_OUT: U5.118 (PD4); also elsewhere on the board
IEC_SRQ_IN: U5.19 (PF7); also elsewhere on the board
IEC_SRQ_OUT: U5.117 (PD3); also elsewhere on the board
I_FDD5: U5.26 (PC0); also elsewhere on the board
I_FDD12: U5.27 (PC1); also elsewhere on the board
PWR_SRC: U5.89 (PG4); also elsewhere on the board
USB_DM: U5.103 (PA11); also elsewhere on the board
USB_DP: U5.104 (PA12); also elsewhere on the board
VBUS: R9.1; also elsewhere on the board
WLOCK: U5.3 (PE4); also elsewhere on the board

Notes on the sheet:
STM32H723ZGT6 CORE (LQFP144) Decoupling per ST AN5419: 100nF per VDD pin + 4.7uF bulk, VCAP 2x2.2uF (LDO mode), VDDA via ferrite with 1uF+100nF, VREF+ = VDDA. HSE 25 MHz, CL 12pF -> 2x 18pF (firmware PLL M=5 N=220 -> 550 MHz). FDD flux: RDATA=PA5 TIM2_CH1, INDEX=PA1 TIM2_CH2, WDATA=PA6 TIM3_CH1.
v0.6: J12 front panel LEDs, 2 pins per LED: 1/2 PWR (green), 3/4 ACT, 5/6 FDD, 7/8 ERR (odd pin = anode via 330R, even pin = GND).
v0.2: APS6404L 8 MB QSPI PSRAM on OCTOSPIM P1 (PB2 CLK, PB10 NCS, PD11/PD12/PB13/PD13 IO0-3). CE# pulled up so the RAM stays deselected while the MCU is in reset.
BOARD_ID divider on PA4 (10k/10k -> v0.5, 10k/4.7k -> v0.6, 10k/2.2k -> v0.7). J9 expansion: I2C1 (2.2k pull-ups), 2 GPIO, button lines, 3V3/5V. SW3/SW4 front buttons (active low, MCU pull-ups). v0.6: SD NAND U15 on SDMMC2 (soldered, 4 GB), 4 bit, 47k pull-ups on CMD/DAT.

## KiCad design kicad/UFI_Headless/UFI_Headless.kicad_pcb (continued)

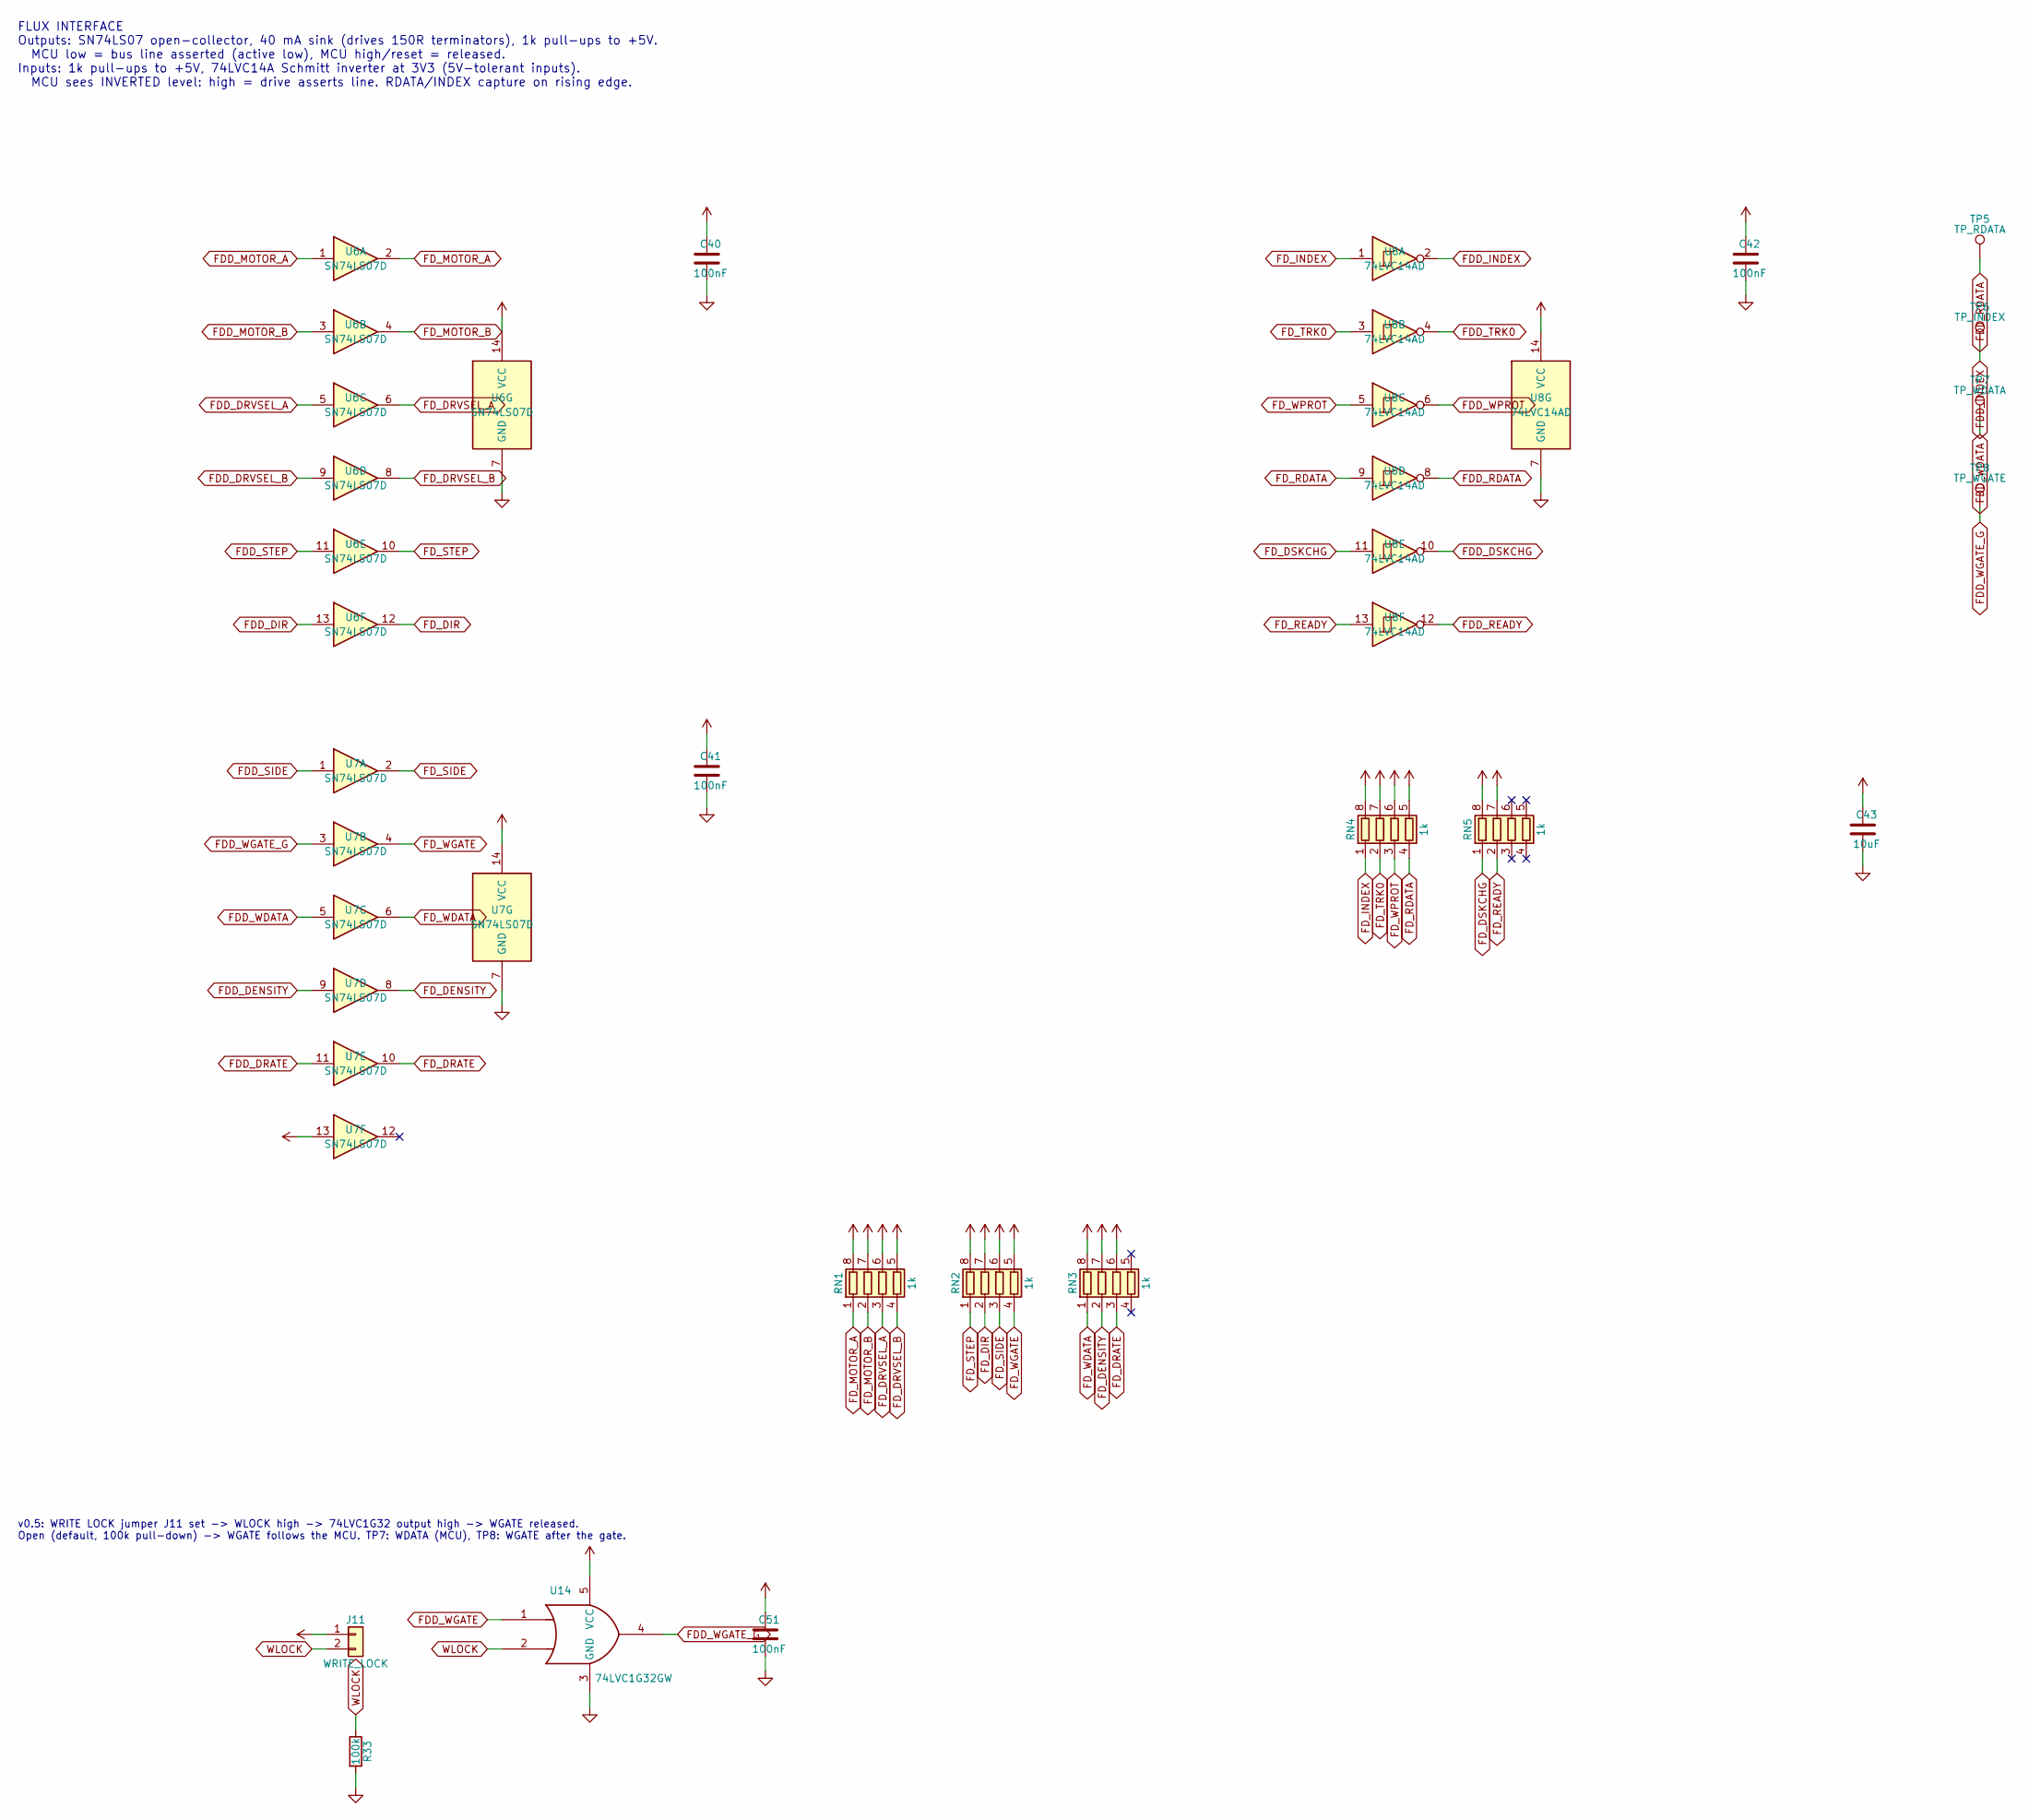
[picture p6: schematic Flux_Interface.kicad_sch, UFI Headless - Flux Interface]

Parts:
C40, C41, C42, C51: 100nF; C_0603_1608Metric; LCSC C14663
C43: 10uF; C_0805_2012Metric; LCSC C15850
J11: WRITE_LOCK; PinHeader_1x02_P2.54mm_Vertical
R33: 100k; R_0603_1608Metric; LCSC C25803
RN1, RN2, RN3, RN4, RN5: 1k; R_Array_Convex_4x0603; LCSC C20197
TP5: TP_RDATA; TestPoint_Pad_D1.5mm
TP6: TP_INDEX; TestPoint_Pad_D1.5mm
TP7: TP_WDATA; TestPoint_Pad_D1.5mm
TP8: TP_WGATE; TestPoint_Pad_D1.5mm
U6, U7: SN74LS07D; SOIC-14_3.9x8.7mm_P1.27mm; MPN SN74LS07DR (alt. SN7407DR); LCSC C371970
U8: 74LVC14AD; SOIC-14_3.9x8.7mm_P1.27mm; MPN SN74LVC14ADR; LCSC C133541
U14: 74LVC1G32GW; SOT-353_SC-70-5; MPN 74LVC1G32GW,125; LCSC C12516

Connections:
+3V3: C42.1, C51.1, J11.1, U8.14 (VCC), U14.5 (VCC); also elsewhere on the board
+5V: C40.1, C41.1, C43.1, RN1.5 (R4.2), RN1.6 (R3.2), RN1.7 (R2.2), RN1.8 (R1.2), RN2.5 (R4.2), RN2.6 (R3.2), RN2.7 (R2.2), RN2.8 (R1.2), RN3.6 (R3.2), RN3.7 (R2.2), RN3.8 (R1.2), RN4.5 (R4.2), RN4.6 (R3.2), RN4.7 (R2.2), RN4.8 (R1.2), RN5.7 (R2.2), RN5.8 (R1.2), U6.14 (VCC), U7.13, U7.14 (VCC); also elsewhere on the board
FDD_DENSITY: U7.9; also elsewhere on the board
FDD_DIR: U6.13; also elsewhere on the board
FDD_DRATE: U7.11; also elsewhere on the board
FDD_DRVSEL_A: U6.5; also elsewhere on the board
FDD_DRVSEL_B: U6.9; also elsewhere on the board
FDD_DSKCHG: U8.10; also elsewhere on the board
FDD_INDEX: TP6.1, U8.2; also elsewhere on the board
FDD_MOTOR_A: U6.1; also elsewhere on the board
FDD_MOTOR_B: U6.3; also elsewhere on the board
FDD_RDATA: TP5.1, U8.8; also elsewhere on the board
FDD_READY: U8.12; also elsewhere on the board
FDD_SIDE: U7.1; also elsewhere on the board
FDD_STEP: U6.11; also elsewhere on the board
FDD_TRK0: U8.4; also elsewhere on the board
FDD_WDATA: TP7.1, U7.5; also elsewhere on the board
FDD_WGATE: U14.1; also elsewhere on the board
FDD_WGATE_G: TP8.1, U7.3, U14.4
FDD_WPROT: U8.6; also elsewhere on the board
FD_DENSITY: RN3.2 (R2.1), U7.8; also elsewhere on the board
FD_DIR: RN2.2 (R2.1), U6.12; also elsewhere on the board
FD_DRATE: RN3.3 (R3.1), U7.10; also elsewhere on the board
FD_DRVSEL_A: RN1.3 (R3.1), U6.6; also elsewhere on the board
FD_DRVSEL_B: RN1.4 (R4.1), U6.8; also elsewhere on the board
FD_DSKCHG: RN5.1 (R1.1), U8.11; also elsewhere on the board
FD_INDEX: RN4.1 (R1.1), U8.1; also elsewhere on the board
FD_MOTOR_A: RN1.1 (R1.1), U6.2; also elsewhere on the board
FD_MOTOR_B: RN1.2 (R2.1), U6.4; also elsewhere on the board
FD_RDATA: RN4.4 (R4.1), U8.9; also elsewhere on the board
FD_READY: RN5.2 (R2.1), U8.13; also elsewhere on the board
FD_SIDE: RN2.3 (R3.1), U7.2; also elsewhere on the board
FD_STEP: RN2.1 (R1.1), U6.10; also elsewhere on the board
FD_TRK0: RN4.2 (R2.1), U8.3; also elsewhere on the board
FD_WDATA: RN3.1 (R1.1), U7.6; also elsewhere on the board
FD_WGATE: RN2.4 (R4.1), U7.4; also elsewhere on the board
FD_WPROT: RN4.3 (R3.1), U8.5; also elsewhere on the board
GND: C40.2, C41.2, C42.2, C43.2, C51.2, R33.2, U6.7 (GND), U7.7 (GND), U8.7 (GND), U14.3 (GND); also elsewhere on the board
WLOCK: J11.2, R33.1, U14.2; also elsewhere on the board

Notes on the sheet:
FLUX INTERFACE Outputs: SN74LS07 open-collector, 40 mA sink (drives 150R terminators), 1k pull-ups to +5V. MCU low = bus line asserted (active low), MCU high/reset = released. Inputs: 1k pull-ups to +5V, 74LVC14A Schmitt inverter at 3V3 (5V-tolerant inputs). MCU sees INVERTED level: high = drive as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
v0.5: WRITE LOCK jumper J11 set -> WLOCK high -> 74LVC1G32 output high -> WGATE released. Open (default, 100k pull-down) -> WGATE follows the MCU. TP7: WDATA (MCU), TP8: WGATE after the gate.

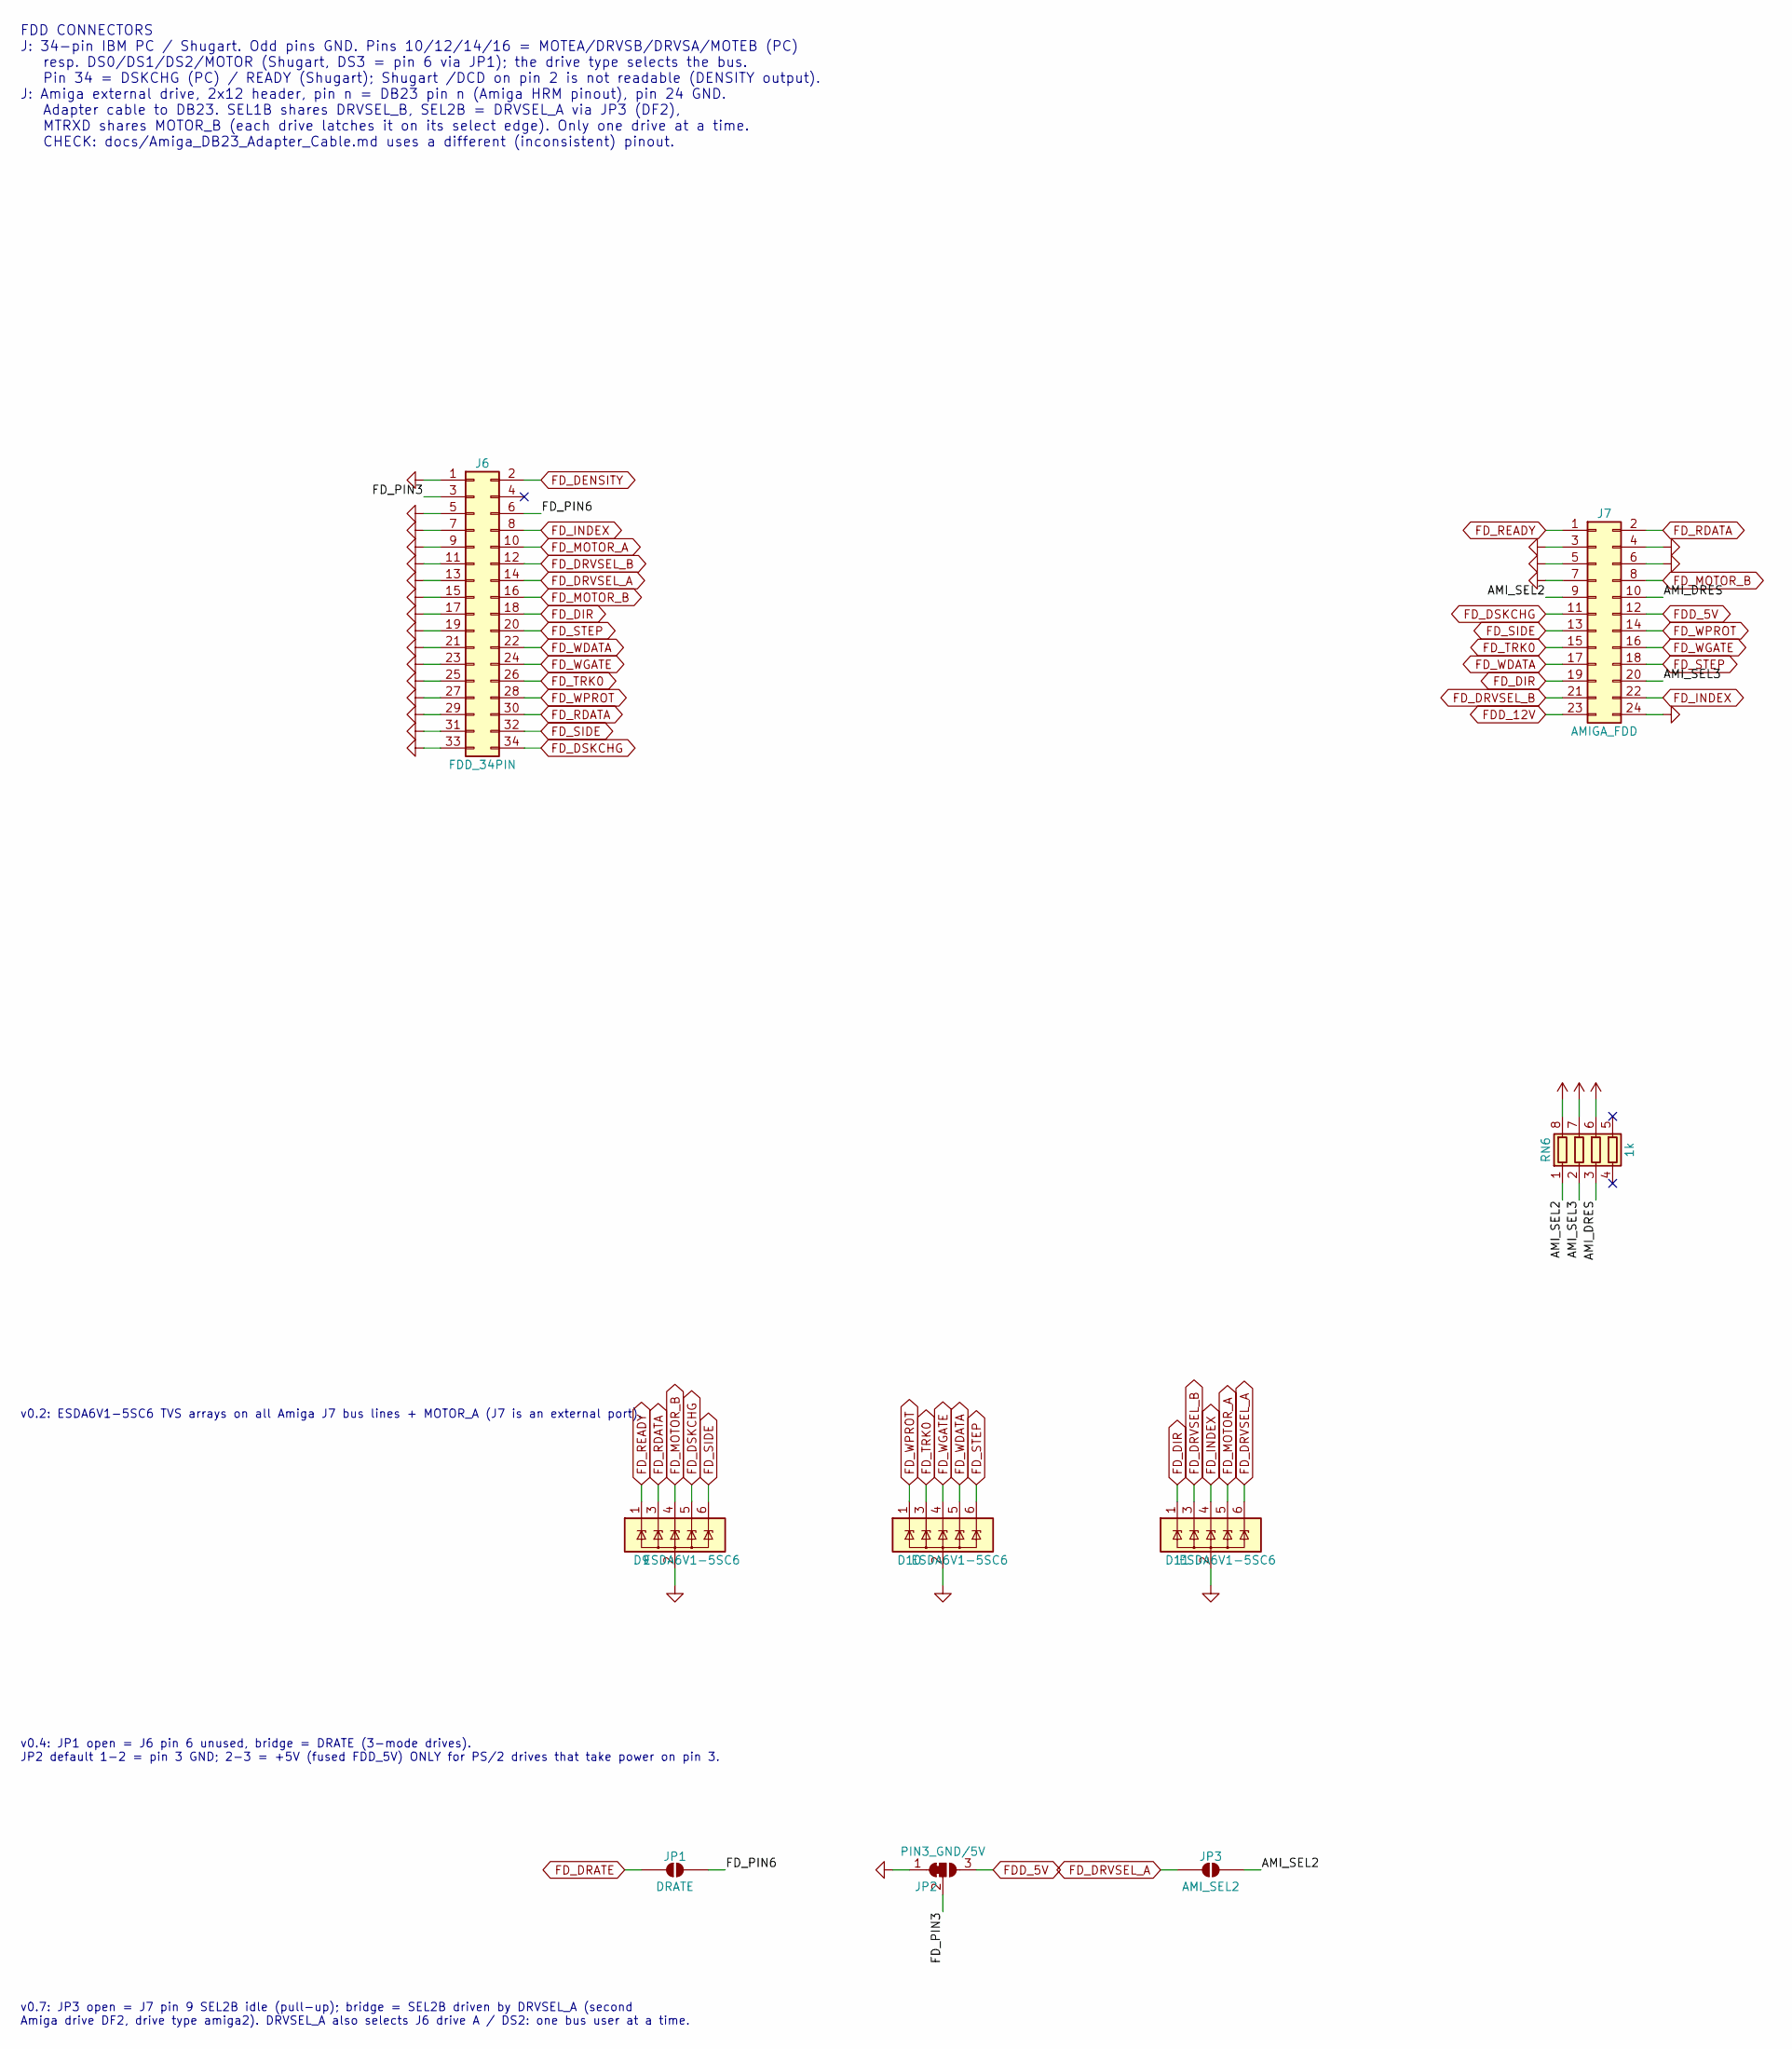
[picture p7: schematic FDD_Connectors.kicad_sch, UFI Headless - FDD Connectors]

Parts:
D9, D10, D11: ESDA6V1-5SC6; SOT-23-6; MPN ESDA6V1-5SC6; LCSC C6650
J6: FDD_34PIN; IDC-Header_2x17_P2.54mm_Vertical; LCSC C20920
J7: AMIGA_FDD; IDC-Header_2x12_P2.54mm_Vertical
JP1: DRATE; SolderJumper-2_P1.3mm_Open_RoundedPad1.0x1.5mm
JP2: PIN3_GND/5V; SolderJumper-3_P1.3mm_Bridged12_RoundedPad1.0x1.5mm
JP3: AMI_SEL2; SolderJumper-2_P1.3mm_Open_RoundedPad1.0x1.5mm
RN6: 1k; R_Array_Convex_4x0603; LCSC C20197

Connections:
+5V: RN6.6 (R3.2), RN6.7 (R2.2), RN6.8 (R1.2); also elsewhere on the board
/FDD_Connectors/AMI_DRES: J7.10, RN6.3 (R3.1)
/FDD_Connectors/AMI_SEL2: J7.9, JP3.2 (B), RN6.1 (R1.1)
/FDD_Connectors/AMI_SEL3: J7.20, RN6.2 (R2.1)
/FDD_Connectors/FD_PIN3: J6.3, JP2.2 (C)
/FDD_Connectors/FD_PIN6: J6.6, JP1.2 (B)
FDD_5V: J7.12, JP2.3 (B); also elsewhere on the board
FDD_12V: J7.23; also elsewhere on the board
FD_DENSITY: J6.2; also elsewhere on the board
FD_DIR: D11.1 (IO1), J6.18, J7.19; also elsewhere on the board
FD_DRATE: JP1.1 (A); also elsewhere on the board
FD_DRVSEL_A: D11.6 (IO5), J6.14, JP3.1 (A); also elsewhere on the board
FD_DRVSEL_B: D11.3 (IO2), J6.12, J7.21; also elsewhere on the board
FD_DSKCHG: D9.5 (IO4), J6.34, J7.11; also elsewhere on the board
FD_INDEX: D11.4 (IO3), J6.8, J7.22; also elsewhere on the board
FD_MOTOR_A: D11.5 (IO4), J6.10; also elsewhere on the board
FD_MOTOR_B: D9.4 (IO3), J6.16, J7.8; also elsewhere on the board
FD_RDATA: D9.3 (IO2), J6.30, J7.2; also elsewhere on the board
FD_READY: D9.1 (IO1), J7.1; also elsewhere on the board
FD_SIDE: D9.6 (IO5), J6.32, J7.13; also elsewhere on the board
FD_STEP: D10.6 (IO5), J6.20, J7.18; also elsewhere on the board
FD_TRK0: D10.3 (IO2), J6.26, J7.15; also elsewhere on the board
FD_WDATA: D10.5 (IO4), J6.22, J7.17; also elsewhere on the board
FD_WGATE: D10.4 (IO3), J6.24, J7.16; also elsewhere on the board
FD_WPROT: D10.1 (IO1), J6.28, J7.14; also elsewhere on the board
GND: D9.2 (GND), D10.2 (GND), D11.2 (GND), J6.1, J6.5, J6.7, J6.9, J6.11, J6.13, J6.15, J6.17, J6.19, J6.21, J6.23, J6.25, J6.27, J6.29, J6.31, J6.33, J7.3, J7.4, J7.5, J7.6, J7.7, J7.24, JP2.1 (A); also elsewhere on the board

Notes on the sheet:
FDD CONNECTORS J: 34-pin IBM PC / Shugart. Odd pins GND. Pins 10/12/14/16 = MOTEA/DRVSB/DRVSA/MOTEB (PC) resp. DS0/DS1/DS2/MOTOR (Shugart, DS3 = pin 6 via JP1); the drive type selects the bus. Pin 34 = DSKCHG (PC) / READY (Shugart); Shugart /DCD on pin 2 is not readable (DENSITY output). J: Amiga e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
v0.2: ESDA6V1-5SC6 TVS arrays on all Amiga J7 bus lines + MOTOR_A (J7 is an external port).
v0.4: JP1 open = J6 pin 6 unused, bridge = DRATE (3-mode drives). JP2 default 1-2 = pin 3 GND; 2-3 = +5V (fused FDD_5V) ONLY for PS/2 drives that take power on pin 3.
v0.7: JP3 open = J7 pin 9 SEL2B idle (pull-up); bridge = SEL2B driven by DRVSEL_A (second Amiga drive DF2, drive type amiga2). DRVSEL_A also selects J6 drive A / DS2: one bus user at a time.

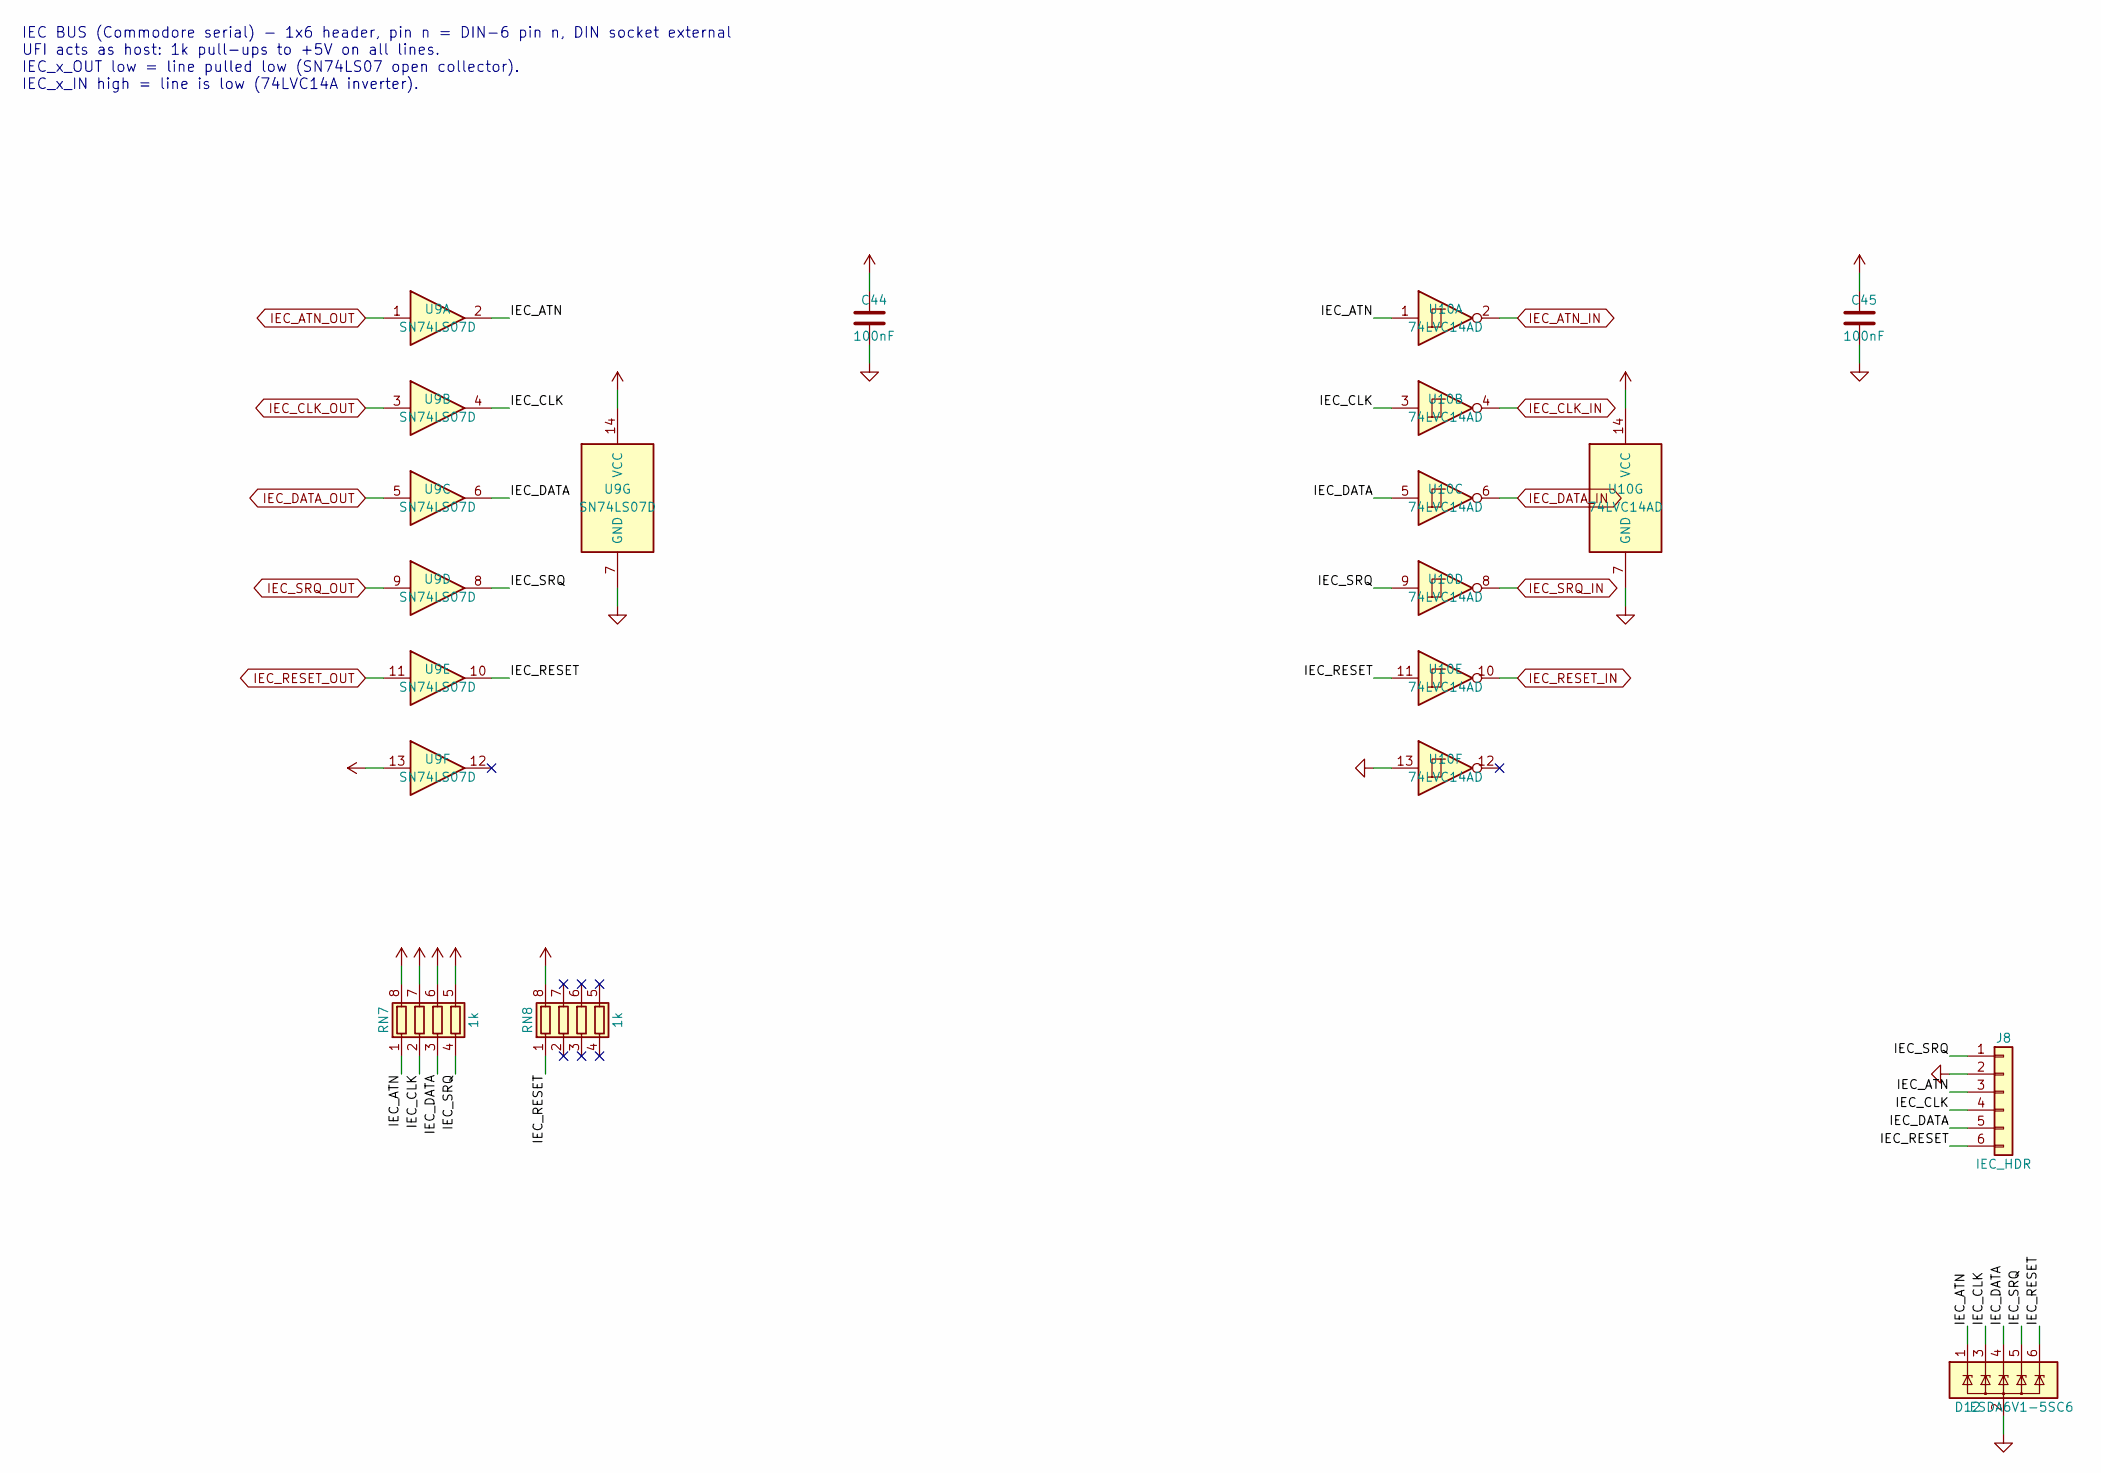
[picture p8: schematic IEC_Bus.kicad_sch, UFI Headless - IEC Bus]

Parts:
C44, C45: 100nF; C_0603_1608Metric; LCSC C14663
D12: ESDA6V1-5SC6; SOT-23-6; MPN ESDA6V1-5SC6; LCSC C6650
J8: IEC_HDR; PinHeader_1x06_P2.54mm_Vertical; LCSC C37208
RN7, RN8: 1k; R_Array_Convex_4x0603; LCSC C20197
U9: SN74LS07D; SOIC-14_3.9x8.7mm_P1.27mm; MPN SN74LS07DR (alt. SN7407DR); LCSC C371970
U10: 74LVC14AD; SOIC-14_3.9x8.7mm_P1.27mm; MPN SN74LVC14ADR; LCSC C133541

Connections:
+3V3: C45.1, U10.14 (VCC); also elsewhere on the board
+5V: C44.1, RN7.5 (R4.2), RN7.6 (R3.2), RN7.7 (R2.2), RN7.8 (R1.2), RN8.8 (R1.2), U9.13, U9.14 (VCC); also elsewhere on the board
/IEC_Bus/IEC_ATN: D12.1 (IO1), J8.3, RN7.1 (R1.1), U9.2, U10.1
/IEC_Bus/IEC_CLK: D12.3 (IO2), J8.4, RN7.2 (R2.1), U9.4, U10.3
/IEC_Bus/IEC_DATA: D12.4 (IO3), J8.5, RN7.3 (R3.1), U9.6, U10.5
/IEC_Bus/IEC_RESET: D12.6 (IO5), J8.6, RN8.1 (R1.1), U9.10, U10.11
/IEC_Bus/IEC_SRQ: D12.5 (IO4), J8.1, RN7.4 (R4.1), U9.8, U10.9
GND: C44.2, C45.2, D12.2 (GND), J8.2, U9.7 (GND), U10.7 (GND), U10.13; also elsewhere on the board
IEC_ATN_IN: U10.2; also elsewhere on the board
IEC_ATN_OUT: U9.1; also elsewhere on the board
IEC_CLK_IN: U10.4; also elsewhere on the board
IEC_CLK_OUT: U9.3; also elsewhere on the board
IEC_DATA_IN: U10.6; also elsewhere on the board
IEC_DATA_OUT: U9.5; also elsewhere on the board
IEC_RESET_IN: U10.10; also elsewhere on the board
IEC_RESET_OUT: U9.11; also elsewhere on the board
IEC_SRQ_IN: U10.8; also elsewhere on the board
IEC_SRQ_OUT: U9.9; also elsewhere on the board

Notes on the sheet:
IEC BUS (Commodore serial) - 1x6 header, pin n = DIN-6 pin n, DIN socket external UFI acts as host: 1k pull-ups to +5V on all lines. IEC_x_OUT low = line pulled low (SN74LS07 open collector). IEC_x_IN high = line is low (74LVC14A inverter).

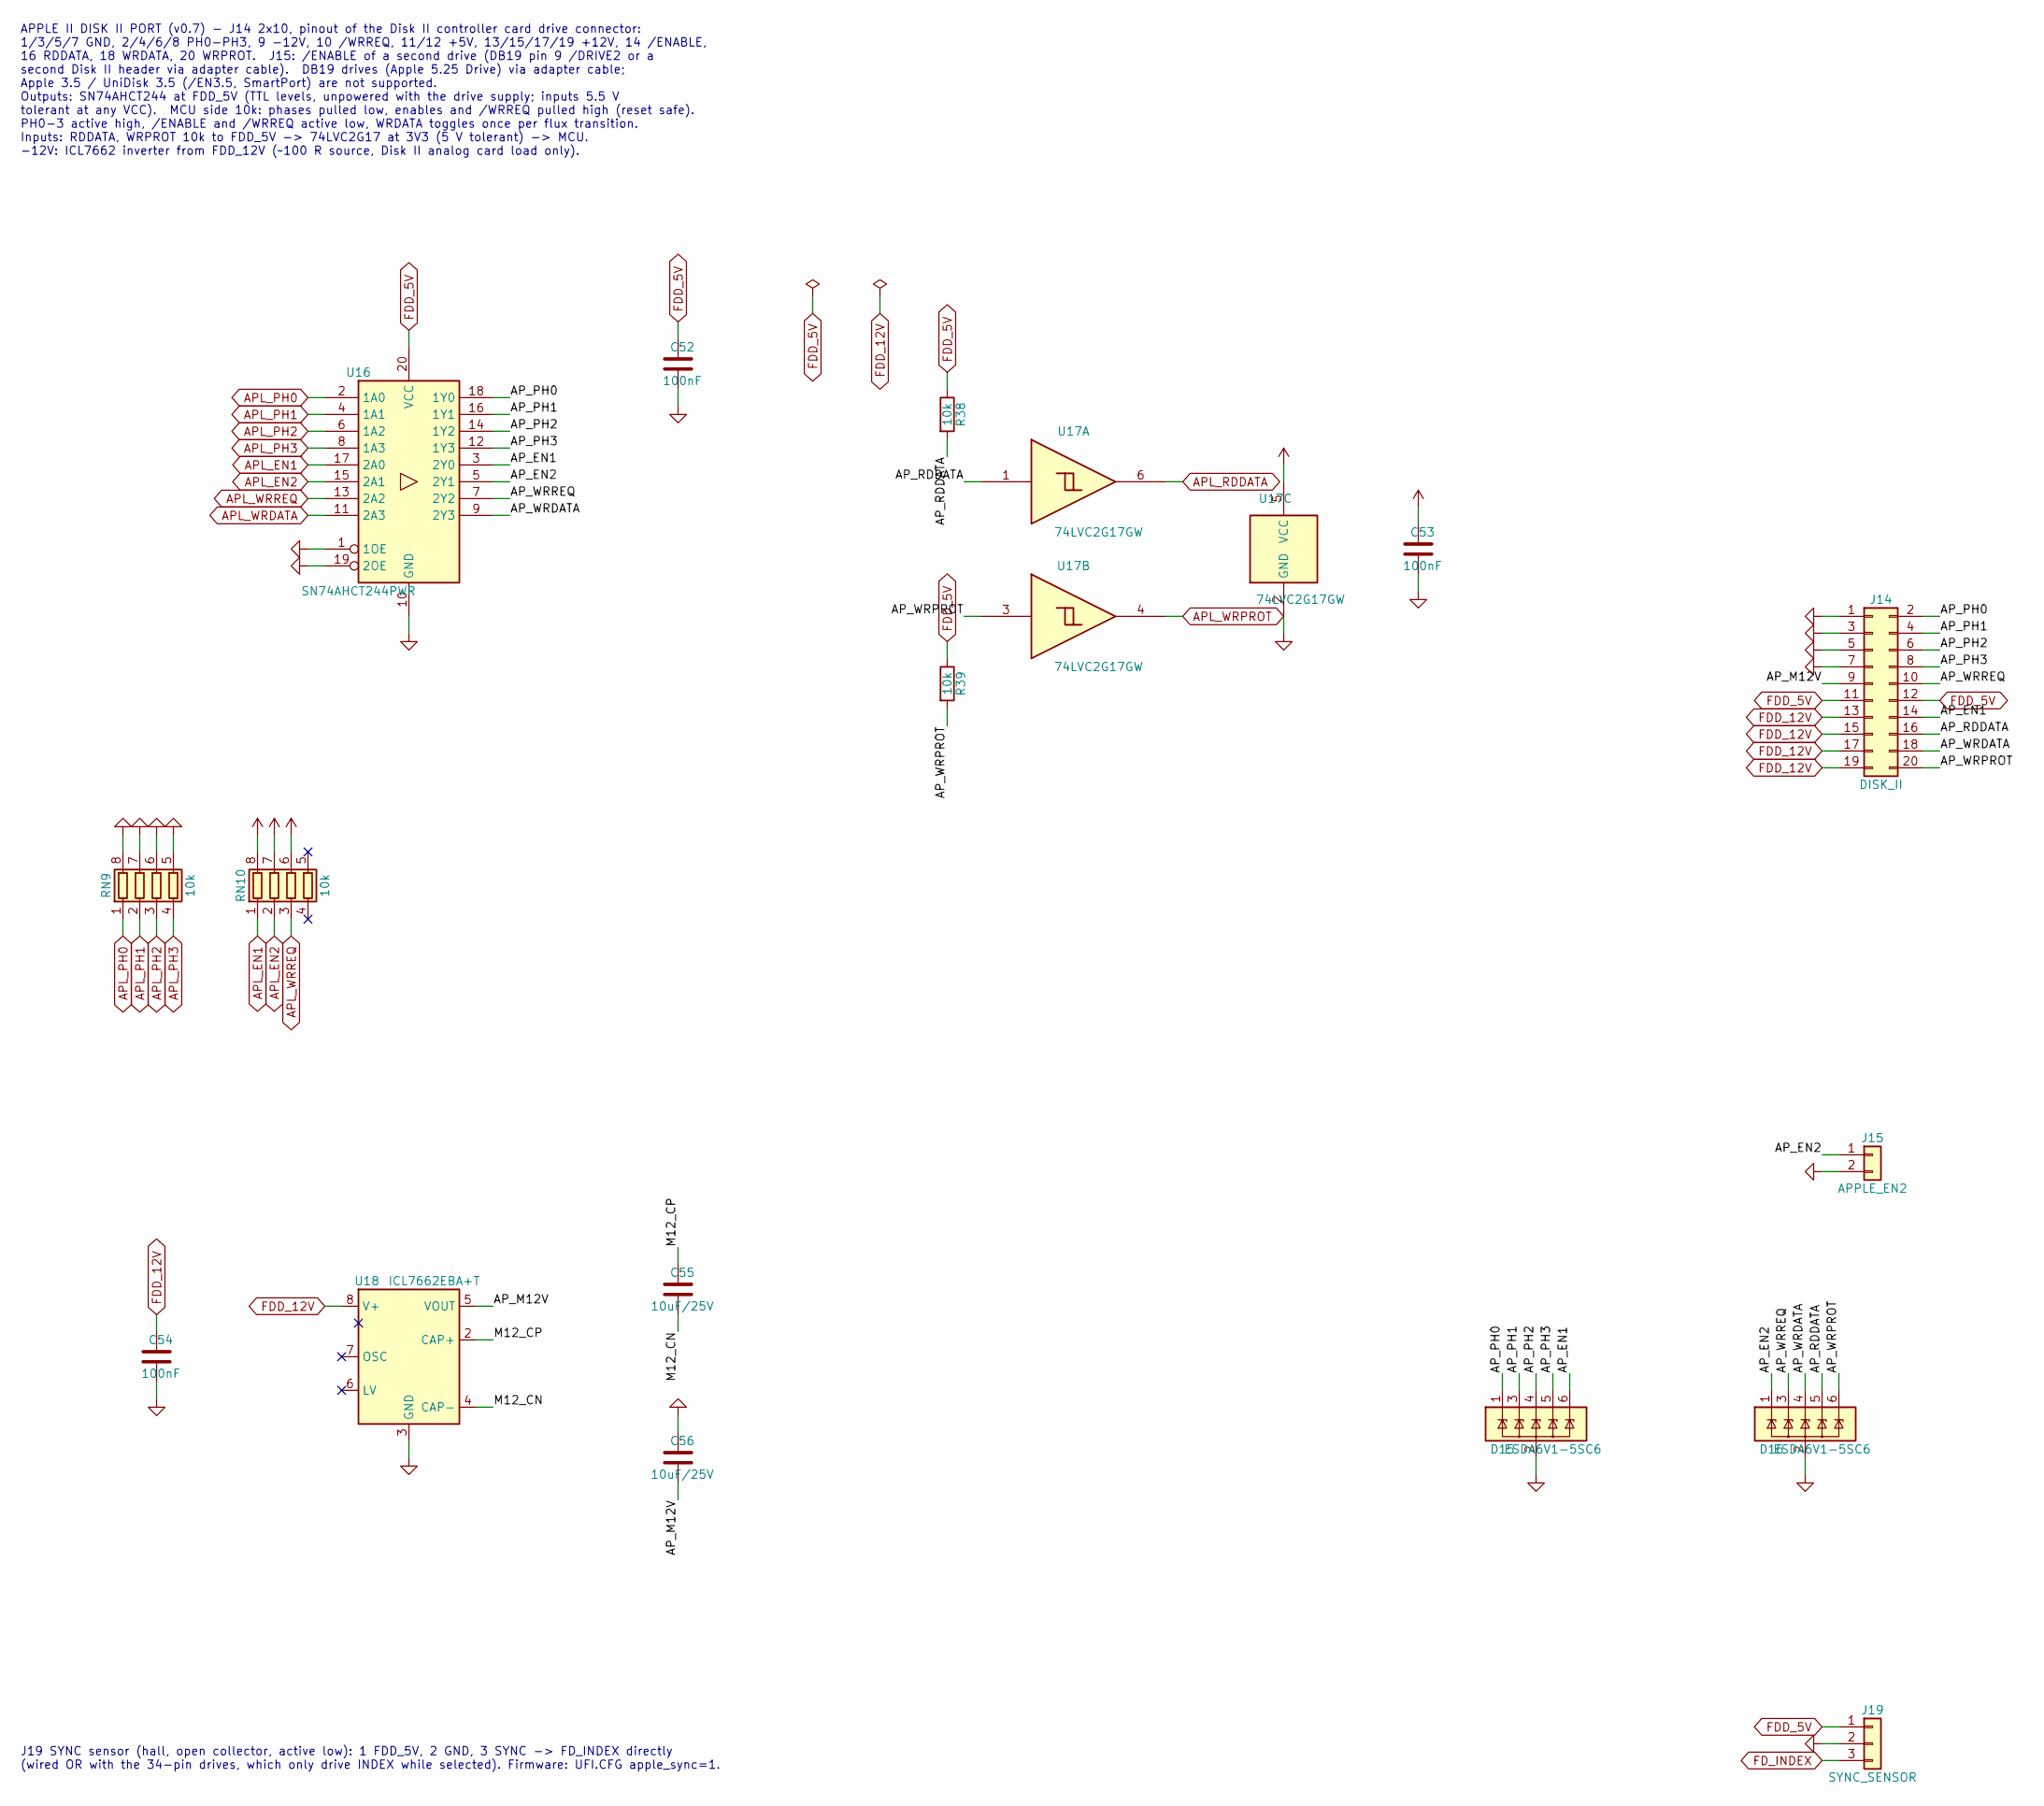
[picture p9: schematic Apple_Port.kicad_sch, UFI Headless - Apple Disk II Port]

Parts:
C52, C53, C54: 100nF; C_0603_1608Metric; LCSC C14663
C55, C56: 10uF/25V; C_1206_3216Metric; LCSC C14860
D15, D16: ESDA6V1-5SC6; SOT-23-6; MPN ESDA6V1-5SC6; LCSC C6650
J14: DISK_II; IDC-Header_2x10_P2.54mm_Vertical_UFI; LCSC C2977593
J15: APPLE_EN2; PinHeader_1x02_P2.54mm_Vertical
J19: SYNC_SENSOR; PinHeader_1x03_P2.54mm_Vertical; LCSC C49257
R38, R39: 10k; R_0603_1608Metric; LCSC C25804
RN9, RN10: 10k; R_Array_Convex_4x0603; LCSC C29718
U16: SN74AHCT244PWR; TSSOP-20_4.4x6.5mm_P0.65mm; MPN SN74AHCT244PWR; LCSC C484743
U17: 74LVC2G17GW; SOT-363_SC-70-6; MPN 74LVC2G17GW,125; LCSC C19829576
U18: ICL7662EBA+T; SOIC-8_3.9x4.9mm_P1.27mm; MPN ICL7662EBA+T; LCSC C28595

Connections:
+3V3: C53.1, RN10.6 (R3.2), RN10.7 (R2.2), RN10.8 (R1.2), U17.5 (VCC); also elsewhere on the board
/Apple_Port/AP_EN1: D15.6 (IO5), J14.14, U16.3 (2Y0)
/Apple_Port/AP_EN2: D16.1 (IO1), J15.1, U16.5 (2Y1)
/Apple_Port/AP_M12V: C56.2, J14.9, U18.5 (VOUT)
/Apple_Port/AP_PH0: D15.1 (IO1), J14.2, U16.18 (1Y0)
/Apple_Port/AP_PH1: D15.3 (IO2), J14.4, U16.16 (1Y1)
/Apple_Port/AP_PH2: D15.4 (IO3), J14.6, U16.14 (1Y2)
/Apple_Port/AP_PH3: D15.5 (IO4), J14.8, U16.12 (1Y3)
/Apple_Port/AP_RDDATA: D16.5 (IO4), J14.16, R38.2, U17.1
/Apple_Port/AP_WRDATA: D16.4 (IO3), J14.18, U16.9 (2Y3)
/Apple_Port/AP_WRPROT: D16.6 (IO5), J14.20, R39.2, U17.3
/Apple_Port/AP_WRREQ: D16.3 (IO2), J14.10, U16.7 (2Y2)
/Apple_Port/M12_CN: C55.2, U18.4 (CAP-)
/Apple_Port/M12_CP: C55.1, U18.2 (CAP+)
APL_EN1: RN10.1 (R1.1), U16.17 (2A0); also elsewhere on the board
APL_EN2: RN10.2 (R2.1), U16.15 (2A1); also elsewhere on the board
APL_PH0: RN9.1 (R1.1), U16.2 (1A0); also elsewhere on the board
APL_PH1: RN9.2 (R2.1), U16.4 (1A1); also elsewhere on the board
APL_PH2: RN9.3 (R3.1), U16.6 (1A2); also elsewhere on the board
APL_PH3: RN9.4 (R4.1), U16.8 (1A3); also elsewhere on the board
APL_RDDATA: U17.6; also elsewhere on the board
APL_WRDATA: U16.11 (2A3); also elsewhere on the board
APL_WRPROT: U17.4; also elsewhere on the board
APL_WRREQ: RN10.3 (R3.1), U16.13 (2A2); also elsewhere on the board
FDD_5V: C52.1, J14.11, J14.12, J19.1, R38.1, R39.1, U16.20 (VCC); also elsewhere on the board
FDD_12V: C54.1, J14.13, J14.15, J14.17, J14.19, U18.8 (V+); also elsewhere on the board
FD_INDEX: J19.3; also elsewhere on the board
GND: C52.2, C53.2, C54.2, C56.1, D15.2 (GND), D16.2 (GND), J14.1, J14.3, J14.5, J14.7, J15.2, J19.2, RN9.5 (R4.2), RN9.6 (R3.2), RN9.7 (R2.2), RN9.8 (R1.2), U16.1 (1OE), U16.10 (GND), U16.19 (2OE), U17.2 (GND), U18.3 (GND); also elsewhere on the board

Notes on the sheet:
APPLE II DISK II PORT (v0.7) - J14 2x10, pinout of the Disk II controller card drive connector: 1/3/5/7 GND, 2/4/6/8 PH0-PH3, 9 -12V, 10 /WRREQ, 11/12 +5V, 13/15/17/19 +12V, 14 /ENABLE, 16 RDDATA, 18 WRDATA, 20 WRPROT. J15: /ENABLE of a second drive (DB19 pin 9 /DRIVE2 or a second Disk II header vi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
J19 SYNC sensor (hall, open collector, active low): 1 FDD_5V, 2 GND, 3 SYNC -> FD_INDEX directly (wired OR with the 34-pin drives, which only drive INDEX while selected). Firmware: UFI.CFG apple_sync=1.

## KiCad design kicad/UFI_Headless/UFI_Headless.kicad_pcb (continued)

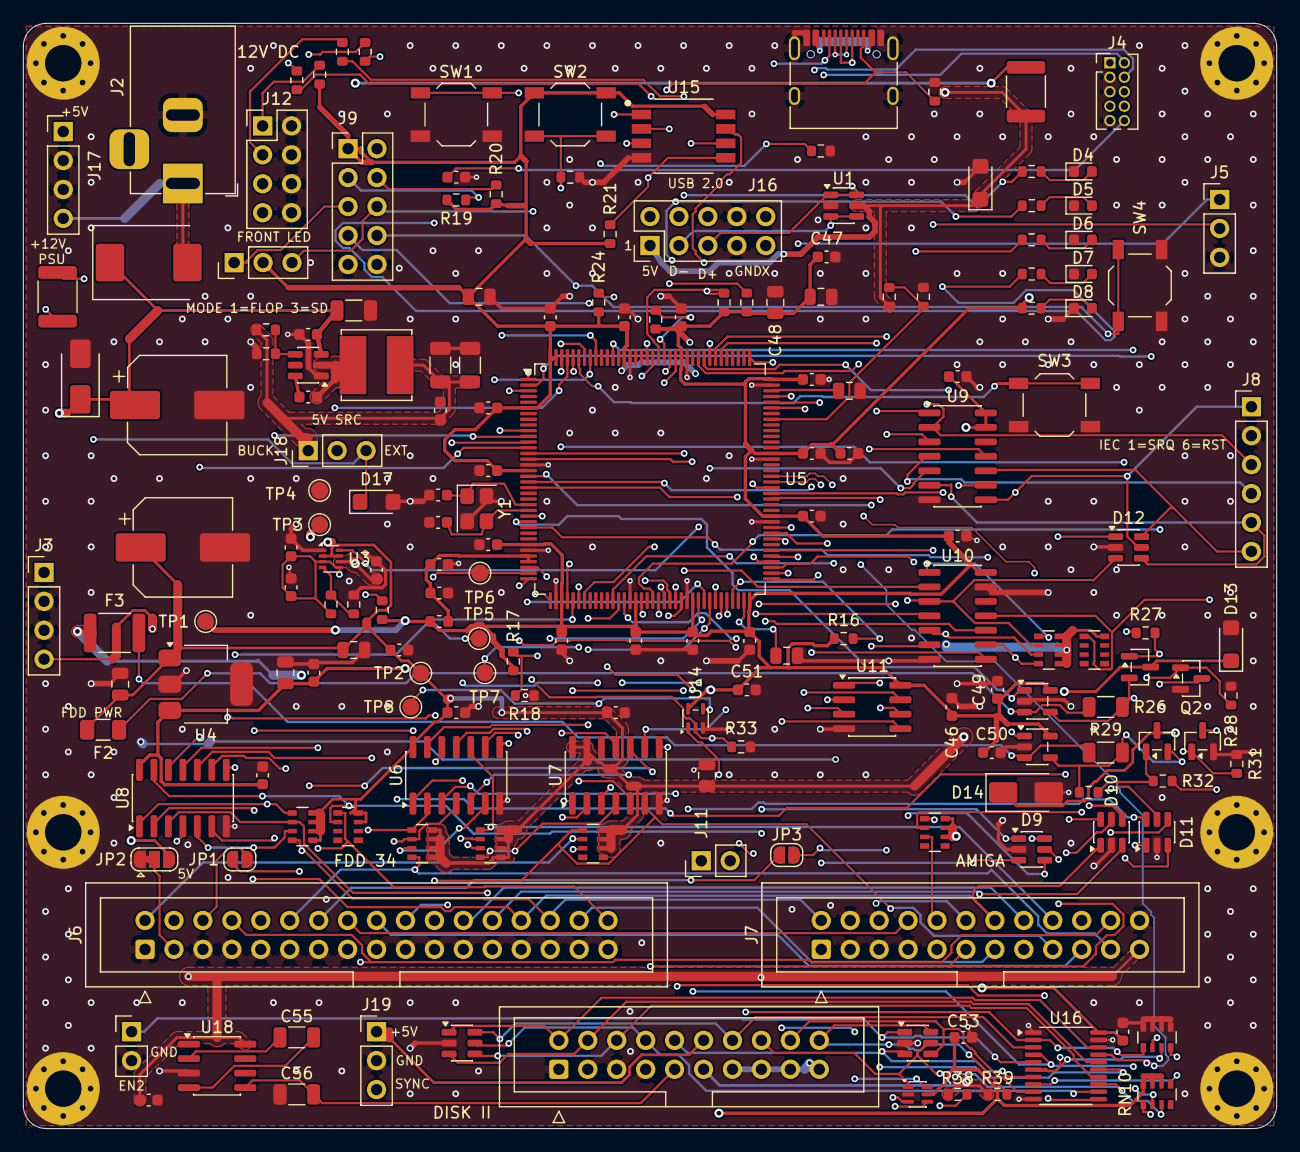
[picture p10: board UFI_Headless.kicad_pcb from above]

Board: 4 copper layers, 110.0 x 97.0 mm, 190 parts (0 on the bottom side), 157 nets.

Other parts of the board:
H1, H2, H3, H4, H5, H6: M3; MountingHole_3.2mm_M3_Pad_Via

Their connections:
GND: H1.1, H2.1, H3.1, H4.1, H5.1, H6.1; also elsewhere on the board

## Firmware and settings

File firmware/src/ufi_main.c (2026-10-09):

/**
 * UFI Flux Engine - STM32H723 Firmware
 * Main Implementation: init, capture orchestration, main loop.
 *
 * Board pins: board.h / board_headless.c; drive control: ufi_drive.c;
 * IEC bus: ufi_iec.c; flux engine: ufi_flux.c.
 */

#include "ufi_firmware.h"

/* ============================================================================
 * GLOBALE VARIABLEN (extern referenziert in ufi_flux.c, ufi_write.c)
 * ============================================================================ */

capture_context_t g_capture;

/* ============================================================================
 * SYSTEM-BOOTLOADER (USB-DFU im ROM)
 * ============================================================================ */

/* STM32H72x/H73x system memory bootloader (ST AN2606) */
#define SYSTEM_BOOTLOADER_ADDR  0x1FF09800UL
#define BOOTLOADER_MAGIC        0xB007DF00UL

/* DTCM is not cached and not cleared by the startup code (.dtcm is NOLOAD), so the
 * value survives NVIC_SystemReset() */
__attribute__((section(".dtcm"))) static volatile uint32_t g_boot_magic;

void ufi_request_bootloader(void)
{
    g_boot_magic = BOOTLOADER_MAGIC;
    __DSB();
    NVIC_SystemReset();
}

/* Called first thing in main(): jump to the ROM bootloader if it was requested */
static void ufi_check_bootloader(void)
{
    if (g_boot_magic != BOOTLOADER_MAGIC) {
        return;
    }
    g_boot_magic = 0;

    __disable_irq();
    SysTick->CTRL = 0;
    SCB_DisableICache();
    SCB_DisableDCache();
    for (uint32_t i = 0; i < 8; i++) {          /* all NVIC lines off and cleared */
        NVIC->ICER[i] = 0xFFFFFFFFUL;
        NVIC->ICPR[i] = 0xFFFFFFFFUL;
    }
    SCB->VTOR = SYSTEM_BOOTLOADER_ADDR;
    __set_MSP(*(volatile uint32_t*)SYSTEM_BOOTLOADER_ADDR);
    __enable_irq();
    void (*boot)(void) = (void (*)(void))(*(volatile uint32_t*)(SYSTEM_BOOTLOADER_ADDR + 4u));
    boot();
    while (1) {
    }
}

/* ============================================================================
 * INITIALISIERUNG
 * ============================================================================ */

void ufi_init(void)
{
    HAL_Init();
    SystemClock_Config();       /* 550 MHz */
    UFI_DWT_INIT();             /* cycle counter for us delays (Fix #6) */
    UFI_WATCHDOG_INIT();        /* Fix #9 */

    board_gpio_init();          /* all pins in their released / idle state */
    ufi_drive_init();
    ufi_iec_init();
    ufi_flux_init();            /* TIM2 + DMA, PSRAM self-test */
    ufi_write_init();
    /* Buttons held at power-up (v0.5): A = ROM USB-DFU bootloader (recovery even when the
     * USB firmware is broken), B = safe mode: drive supplies stay off (BOARD_STATUS bit6) */
    HAL_Delay(5);               /* button pull-ups settle */
    if (HAL_GPIO_ReadPin(PIN_BTN_A.port, PIN_BTN_A.pin) == GPIO_PIN_RESET) {
        ufi_request_bootloader();
    }
    const bool safe_mode = HAL_GPIO_ReadPin(PIN_BTN_B.port, PIN_BTN_B.pin) == GPIO_PIN_RESET;
    ufi_board_init(!safe_mode); /* drive supplies on (5 V, then 12 V) unless safe mode */
    if (safe_mode) {
        led_set(&PIN_LED_ERR, true);
    }
    ufi_usb_init();
    ufi_sd_init();              /* v0.6 SD NAND; failure shows in SD_INFO / dump error 1 */
    ufi_config_load();          /* UFI.CFG: stand-alone drive (a/b/amiga/ds0-ds3), dump settings */
    ufi_mode_init();            /* mode switch on J13: flux / USB floppy / SD drive */

    /* PSRAM fitted but failed its self-test: 3 ERR blinks (flux store falls back to SRAM,
     * GET_INFO reports the result) */
    if (BOARD_HAS_PSRAM && !ufi_flux_store_is_psram()) {
        for (int i = 0; i < 3; i++) {
            led_set(&PIN_LED_ERR, true);
            HAL_Delay(150);
            led_set(&PIN_LED_ERR, false);
            HAL_Delay(150);
        }
    }

    g_capture.state = CAPTURE_IDLE;
}

/* ============================================================================
 * FLUX CAPTURE
 * ============================================================================ */

int ufi_capture_start(uint8_t track, uint8_t side, uint8_t revolutions, uint32_t period_ticks)
{
    return ufi_capture_start_q(track, side, revolutions, period_ticks, 0);
}

int ufi_capture_start_q(uint8_t track, uint8_t side, uint8_t revolutions, uint32_t period_ticks,
                        uint8_t quarter)
{
    if (g_capture.state == CAPTURE_WAITING_INDEX || g_capture.state == CAPTURE_RUNNING ||
        ufi_stream_active()) {
        return UFI_ERR_BUSY;
    }
    if (ufi_drive_get_current() == DRIVE_NONE) {
        return UFI_ERR_NO_DRIVE;
    }
    const int sret = ufi_drive_seek_q(track, quarter);
    if (sret != 0) {
        return sret == UFI_ERR_BAD_ARGS ? UFI_ERR_BAD_ARGS : UFI_ERR_SEEK_FAIL;
    }
    ufi_drive_select_side(side);

    g_capture.current_track = track;
    g_capture.current_side = side;

    /* Apple Disk II: RDDATA input; without a sync sensor (J19, UFI.CFG apple_sync=1) there
     * is no index pulse -> revolutions are 200 ms slices */
    const bool apple = ufi_drive_is_apple();
    ufi_flux_select_apple(apple);
    if (apple && period_ticks == 0 && !ufi_config_apple_sync()) {
        period_ticks = FLUX_TIMER_FREQ / 5u;
    }

    int ret = ufi_flux_capture_start(revolutions, period_ticks);
    if (ret == UFI_OK) {
        led_set(&PIN_LED_ERR, false);
        led_set(&PIN_LED_FDD, true);
    }
    return ret;
}

int ufi_capture_abort(void)
{
    ufi_stream_abort();
    ufi_flux_capture_stop();
    led_set(&PIN_LED_FDD, false);
    return UFI_OK;
}

capture_state_t ufi_capture_get_state(void)
{
    return ufi_flux_poll();
}

flux_revolution_t* ufi_capture_get_data(uint8_t revolution)
{
    return ufi_flux_get_revolution(revolution);
}

/* ============================================================================
 * HAUPTSCHLEIFE
 * ============================================================================ */

static void send_capture(void)
{
    const uint8_t n = ufi_flux_get_revolution_count();
    for (uint8_t i = 0; i < n; i++) {
        flux_revolution_t* rev = ufi_flux_get_revolution(i);
        flux_packet_header_t header = {
            .track = g_capture.current_track,
            .side = g_capture.current_side,
            .revolution = i,
            .flags = (uint8_t)(0x01 | (g_capture.error_code == 1 ? 0x02 : 0x00)),
            .index_time = rev->index_time,
            .sample_count = rev->count,
        };
        if (ufi_usb_send_flux(&header, rev->samples) != UFI_OK) {
            return;                     /* host gone: no READ_DONE either */
        }
    }
    ufi_usb_send_read_done(g_capture.error_code == 1 ? UFI_ERR_BUFFER_FULL : UFI_OK, n);
}

void ufi_main_loop(void)
{
    uint32_t last_blink = 0;

    while (1) {
        UFI_WATCHDOG_FEED();

        ufi_usb_process_command();
        ufi_write_process();
        ufi_write_service();
        ufi_sched_service();            /* head steps on a schedule during read / write */
        ufi_board_service();            /* overcurrent, USB loss, motor timeout */

        ufi_buttons_service();          /* A hold = dump, B = abort / USB mass storage */
        ufi_mode_service();             /* mode switch, mode blink code */
        ufi_usb_poll();                 /* USB floppy mode: USB stack runs here */
        ufi_floppy_service();           /* USB floppy mode: write back idle tracks */

        const capture_state_t cs = ufi_capture_get_state();   /* also runs the index timeout */
        if (ufi_dump_active()) {
            ufi_dump_service();             /* stand-alone dump owns the capture */
        } else if (ufi_stream_active()) {
            ufi_stream_service();           /* READ_TRACK: sends while the disk turns */
        } else switch (cs) {
            case CAPTURE_COMPLETE:
                send_capture();
                g_capture.state = CAPTURE_IDLE;
                led_set(&PIN_LED_FDD, false);
                break;
            case CAPTURE_ERROR:
                ufi_usb_send_read_done(g_capture.error_code == 2 ? UFI_ERR_DMA :
                                       g_capture.error_code == 3 ? UFI_ERR_NO_INDEX : UFI_ERR_BUFFER_FULL, 0);
                g_capture.state = CAPTURE_IDLE;
                led_set(&PIN_LED_FDD, false);
                led_set(&PIN_LED_ERR, true);
                break;
            default:
                break;
        }

        /* Activity LED blinks while reading or writing (Fix #12) */
        if (g_capture.state == CAPTURE_RUNNING || ufi_write_get_state() == WRITE_ACTIVE) {
            uint32_t now = HAL_GetTick();
            if (now - last_blink > 100) {
                HAL_GPIO_TogglePin(PIN_LED_ACT.port, PIN_LED_ACT.pin);
                last_blink = now;
            }
        }
    }
}

/* ============================================================================
 * MAIN
 * ============================================================================ */

int main(void)
{
    ufi_check_bootloader();
    ufi_init();
    ufi_main_loop();
    return 0;
}

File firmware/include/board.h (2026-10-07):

/**
 * UFI Flux Engine - Board Definition: UFI Headless (STM32H723ZGT6, LQFP144)
 *
 * Single source of truth for pin assignment and signal polarity.
 * Schematic: kicad/UFI_Headless (README "GPIO-Belegung").
 *
 * Polarity on this board:
 *  - Outputs (FDD_*, IEC_*_OUT) drive SN74LS07 open-collector buffers:
 *    MCU low  = bus line asserted (low), MCU high = released.
 *  - Inputs (FDD_INDEX/TRK0/WPROT/RDATA/DSKCHG/READY, IEC_*_IN) pass through
 *    74LVC14A Schmitt inverters: MCU high = bus line asserted (low).
 *    Flux/index capture therefore triggers on the RISING edge.
 */

#ifndef BOARD_H
#define BOARD_H

#include "stm32h7xx_hal.h"
#include <stdbool.h>
#include <stdint.h>

#define BOARD_NAME              "UFI Headless"
#define BOARD_HAS_APPLE         1       /* Apple Disk II port J14 from v0.7 (checked at run time) */

typedef struct {
    GPIO_TypeDef* port;
    uint16_t pin;
} gpio_pin_t;

/* ---- FDD outputs (34-pin J6 + Amiga J7), GPIOE ------------------------- */
extern const gpio_pin_t PIN_FDD_MOTOR_A;    /* PE7  */
extern const gpio_pin_t PIN_FDD_MOTOR_B;    /* PE8  (Amiga MTRXD) */
extern const gpio_pin_t PIN_FDD_DRV_SEL_A;  /* PE9  */
extern const gpio_pin_t PIN_FDD_DRV_SEL_B;  /* PE10 (Amiga SEL1B) */
extern const gpio_pin_t PIN_FDD_STEP;       /* PE11 */
extern const gpio_pin_t PIN_FDD_DIR;        /* PE12 */
extern const gpio_pin_t PIN_FDD_SIDE_SEL;   /* PE13 */
extern const gpio_pin_t PIN_FDD_WGATE;      /* PE14 */
extern const gpio_pin_t PIN_FDD_DENSITY;    /* PE15 */
extern const gpio_pin_t PIN_FDD_DRATE;      /* PF11, J6 pin 6 via solder jumper JP1 (v0.4) */
extern const gpio_pin_t PIN_FDD_WDATA;      /* PA6, TIM3_CH1 (AF2) write pulses */

/* ---- FDD inputs ---------------------------------------------------------- */
extern const gpio_pin_t PIN_FDD_RDATA;      /* PA5, TIM2_CH1 (AF1) input capture */
extern const gpio_pin_t PIN_FDD_INDEX;      /* PA1, TIM2_CH2 (AF1) input capture */
extern const gpio_pin_t PIN_FDD_TRACK0;     /* PF0 */
extern const gpio_pin_t PIN_FDD_WPROT;      /* PF1 */
extern const gpio_pin_t PIN_FDD_DKCHG;      /* PF2 */
extern const gpio_pin_t PIN_FDD_READY;      /* PF3 */

#define FDD_RDATA_AF            GPIO_AF1_TIM2
#define FDD_INDEX_AF            GPIO_AF1_TIM2
#define FDD_WDATA_AF            GPIO_AF2_TIM3   /* TIM3_CH1 */
#define FLUX_RDATA_CHANNEL      TIM_CHANNEL_1
#define FLUX_INDEX_CHANNEL      TIM_CHANNEL_2

/* ---- Apple Disk II port J14 (board v0.7) ----------------------------------
 * Push-pull GPIOs into an SN74AHCT244 (non-inverting, 5 V TTL): PHx high = phase on,
 * EN1/EN2/WRREQ low = asserted.  Inputs through a 74LVC2G17 (non-inverting): WRPROT
 * high = protected.  RDDATA on TIM2_CH3 (same counter as RDATA), WRDATA = TIM3_CH2 in
 * toggle mode (Disk II writes a level change per flux transition). */
extern const gpio_pin_t PIN_APL_PH0;        /* PF12 */
extern const gpio_pin_t PIN_APL_PH1;        /* PF13 */
extern const gpio_pin_t PIN_APL_PH2;        /* PG6 */
extern const gpio_pin_t PIN_APL_PH3;        /* PF15 */
extern const gpio_pin_t PIN_APL_EN1;        /* PG5, /ENABLE drive 1 (J14 pin 14) */
extern const gpio_pin_t PIN_APL_EN2;        /* PB12, /ENABLE drive 2 (J15) */
extern const gpio_pin_t PIN_APL_WRREQ;      /* PB14 */
extern const gpio_pin_t PIN_APL_WRPROT;     /* PB15 */
extern const gpio_pin_t PIN_APL_RDDATA;     /* PA2, TIM2_CH3 (AF1) */
extern const gpio_pin_t PIN_APL_WRDATA;     /* PA7, TIM3_CH2 (AF2) */
#define APL_RDDATA_AF           GPIO_AF1_TIM2
#define APL_WRDATA_AF           GPIO_AF2_TIM3

/* ---- IEC bus: separate driver outputs and receiver inputs ---------------- */
extern const gpio_pin_t PIN_IEC_ATN_OUT;    /* PD0 */
extern const gpio_pin_t PIN_IEC_CLK_OUT;    /* PD1 */
extern const gpio_pin_t PIN_IEC_DATA_OUT;   /* PD2 */
extern const gpio_pin_t PIN_IEC_SRQ_OUT;    /* PD3 */
extern const gpio_pin_t PIN_IEC_RESET_OUT;  /* PD4 */
extern const gpio_pin_t PIN_IEC_ATN_IN;     /* PF4 */
extern const gpio_pin_t PIN_IEC_CLK_IN;     /* PF5 */
extern const gpio_pin_t PIN_IEC_DATA_IN;    /* PF6 */
extern const gpio_pin_t PIN_IEC_SRQ_IN;     /* PF7 */
extern const gpio_pin_t PIN_IEC_RESET_IN;   /* PF8 */

/* ---- Status, LEDs (high = on; power LED is hard-wired to 3V3) ------------ */
extern const gpio_pin_t PIN_LED_ACT;        /* PG0 */
extern const gpio_pin_t PIN_LED_FDD;        /* PG1 */
extern const gpio_pin_t PIN_LED_USB;        /* PG2 */
extern const gpio_pin_t PIN_LED_ERR;        /* PG3 */
extern const gpio_pin_t PIN_PWR_SRC;        /* PG4, TPS2116 status input */
extern const gpio_pin_t PIN_VBUS_SENSE;     /* PA9, 22k/33k divider */
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

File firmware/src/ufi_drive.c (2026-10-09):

/**
 * UFI Flux Engine - Drive Control Module
 *
 * Shugart/PC (34-pin J6) and Amiga (DB23 header J7) drives on the shared FDD bus.
 * Pins and polarity come from board.h: bus_out(pin, true) asserts a line (low on the
 * cable), bus_in(pin) is true while the drive asserts it.
 *
 * Amiga J7 wiring: MTRXD = MOTOR_B, SEL1B = DRV_SEL_B, SEL2B = DRV_SEL_A (v0.7, only
 * with JP3 bridged).  Amiga drives latch MTRXD on the falling edge of their select line,
 * so the motor is switched via a select pulse and each drive keeps its own motor state.
 */

#include "ufi_firmware.h"

/* ============================================================================
 * GLOBALE VARIABLEN
 * ============================================================================ */

static drive_type_t g_current_drive = DRIVE_NONE;
static drive_status_t g_drive_status[DRIVE_TYPE_COUNT];

// Timing-Konstanten (µs)
// Timing (host-tunable per drive via UFI_CMD_DRIVE_TIMING, defaults = PC/Amiga safe values)
static drive_timing_t g_timing = {
    .step_pulse_us = 10, .step_rate_us = 3000, .settle_us = 15000, .dir_change_us = 0,
    .side_settle_us = 200, .spinup_ms = 500, .select_settle_us = 10000,
    .motor_off_s = 30, .double_step = 0, .precomp_ns = PRECOMP_AUTO,
};
#define STEP_PULSE_US       (g_timing.step_pulse_us)
#define STEP_RATE_US        (g_timing.step_rate_us)
#define SETTLE_TIME_US      (g_timing.settle_us)
#define MOTOR_SPINUP_MS     (g_timing.spinup_ms)
#define DIR_SETUP_US        1
#define SELECT_SETTLE_US    (g_timing.select_settle_us)
static int g_last_dir;              /* +1 / -1, for the direction-change settle */

static void delay_us(uint32_t us)
{
    uint32_t start = DWT->CYCCNT;
    uint32_t cycles = us * (SystemCoreClock / 1000000);
    while ((DWT->CYCCNT - start) < cycles);
}

/* ============================================================================
 * APPLE DISK II (board v0.7: J14 = drive 1, J15 = /ENABLE of drive 2)
 * Four-phase stepper, one phase step = half a track, track n sits at phase (2n) & 3.
 * Positions are kept in quarter tracks (1.14): even quarters = one phase, odd quarters =
 * the two neighbouring phases energised together (head between the poles, phases stay on).
 * No track 0 sensor: recalibrate = 80 half steps outwards against the stop, ending on
 * phase 0 (as the Apple RWTS does).  /ENABLE runs the spindle and powers the stepper.
 * ============================================================================ */

#define APL_HALFSTEP_US     4000u       /* per half track (RWTS: ~2.5-3 ms at full speed) */
#define APL_OVERLAP_US      1000u       /* next phase on before the previous goes off */
#define APL_SETTLE_US       25000u
#define APL_MAX_TRACK       39

static const gpio_pin_t* const apl_ph[4] = {&PIN_APL_PH0, &PIN_APL_PH1, &PIN_APL_PH2, &PIN_APL_PH3};
static int16_t apl_qt[2] = {-1, -1};    /* quarter-track position per drive, -1 = unknown */
#define APL_MAX_QT          (4 * APL_MAX_TRACK)

static bool is_apple(drive_type_t t)
{
    return t == DRIVE_APPLE_II || t == DRIVE_APPLE2;
}

static const gpio_pin_t* apl_en(drive_type_t t)
{
    return t == DRIVE_APPLE2 ? &PIN_APL_EN2 : &PIN_APL_EN1;
}

static void apl_phase(int p, bool on)
{
    HAL_GPIO_WritePin(apl_ph[p & 3]->port, apl_ph[p & 3]->pin, on ? GPIO_PIN_SET : GPIO_PIN_RESET);
}

static void apl_release(void)
{
    for (int p = 0; p < 4; p++) {
        apl_phase(p, false);
    }
    for (int d = 0; d < 2; d++) {
        if (apl_qt[d] > 0 && (apl_qt[d] & 1)) {
            apl_qt[d] = -1;                 /* unpowered on a quarter: head snaps to a pole */
        }
    }
    HAL_GPIO_WritePin(PIN_APL_EN1.port, PIN_APL_EN1.pin, GPIO_PIN_SET);
    HAL_GPIO_WritePin(PIN_APL_EN2.port, PIN_APL_EN2.pin, GPIO_PIN_SET);
    HAL_GPIO_WritePin(PIN_APL_WRREQ.port, PIN_APL_WRREQ.pin, GPIO_PIN_SET);
}

/* Move the current Apple drive to quarter track `target` (from qt, which may be assumed) */
static void apl_move_qt(int qt, int target)
{
    int h = qt / 2;                         /* half track; an odd qt sits between h and h+1 */
    if (qt & 1) {
        apl_phase(h + 1, false);            /* back onto the pole of h first */
        delay_us(APL_HALFSTEP_US);
    }
    const int th = target / 2;
    while (h != th) {
        const int next = h + (th > h ? 1 : -1);
        apl_phase(next, true);
        delay_us(APL_OVERLAP_US);
        apl_phase(h, false);
        delay_us(APL_HALFSTEP_US);
        h = next;
    }
    if (target & 1) {
        apl_phase(th, true);                /* both poles: the head settles in between and */
        apl_phase(th + 1, true);            /* the phases stay energised while it is there */
        delay_us(APL_SETTLE_US);
    } else {
        delay_us(APL_SETTLE_US);
        apl_phase(th, false);               /* stepper unpowered between seeks: no heating */
    }
    apl_qt[g_current_drive == DRIVE_APPLE2] = (int16_t)target;
    g_drive_status[g_current_drive].current_track = (uint8_t)(target / 4);
}

static int apl_recalibrate(void)
{
    apl_move_qt(4 * (APL_MAX_TRACK + 1), 0);    /* assume the far end: hits the stop on the way */
    g_drive_status[g_current_drive].track0 = true;
    return UFI_OK;
}

static int apl_seek_qt(int target)
{
    if (target < 0 || target > APL_MAX_QT) {
        return UFI_ERR_SEEK_FAIL;
    }
    const int qt = apl_qt[g_current_drive == DRIVE_APPLE2];
    if (qt < 0) {
        apl_recalibrate();
        apl_move_qt(0, target);
    } else {
        apl_move_qt(qt, target);
    }
    return UFI_OK;
}

static int apl_seek(uint8_t track)
{
    return apl_seek_qt(4 * track);
}

int ufi_drive_apple_step(int direction)
{
    const int qt = apl_qt[g_current_drive == DRIVE_APPLE2];
    if (qt < 0) {
        return apl_recalibrate();
    }
    int target = qt + 4 * (direction > 0 ? 1 : -1);
    if (target < 0) target = 0;
    if (target > APL_MAX_QT) target = APL_MAX_QT;
    apl_move_qt(qt, target);
    return UFI_OK;
}

/* Seek with a quarter-track offset (Apple only; quarter 0 = plain seek on any drive) */
int ufi_drive_seek_q(uint8_t track, uint8_t quarter)
{
    if (quarter == 0) {
        return ufi_drive_seek(track);
    }
    if (g_current_drive == DRIVE_NONE || g_current_drive == DRIVE_IEC) {
        return UFI_ERR_NO_DRIVE;
    }
    if (!is_apple(g_current_drive) || quarter > 3u) {
        return UFI_ERR_BAD_ARGS;
    }
    return apl_seek_qt(4 * track + quarter);
}

/* ============================================================================
 * INITIALISIERUNG
 * ============================================================================ */

void ufi_drive_init(void)
{
    /* GPIO modes/levels are set by board_gpio_init(); all lines released */
    for (int i = 0; i < DRIVE_TYPE_COUNT; i++) {
        g_drive_status[i] = (drive_status_t){0};
        g_drive_status[i].type = DRIVE_NONE;
    }
    g_current_drive = DRIVE_NONE;
}
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

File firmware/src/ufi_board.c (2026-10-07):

/**
 * UFI Flux Engine - board v0.5 extras and safety
 *
 * Drive supplies: FDD_5V / FDD_12V are switched by P-FETs (PE2/PE3 high = on; the 100k
 * pull-downs keep them off while the MCU is in reset) and measured through 0.1R shunts by
 * INA180A1 amplifiers (20 V/V -> 2 mV per mA) on ADC1.  A rail drawing more than
 * OVERCURRENT_MA for OVERCURRENT_SAMPLES samples in a row is switched off and flagged
 * until the host switches it on again (BOARD_STATUS).
 *
 * Safety: USB unconfigured/suspended for USB_LOST_MS (cable pulled, host asleep) ->
 * transfers aborted, motor off, drive deselected, write lines released.  A motor that
 * stays idle for drive_timing_t.motor_off_s is switched off.
 *
 * WRITE LOCK jumper (J11): blocks WGATE in hardware (74LVC1G32), WLOCK lets the firmware
 * refuse writes with UFI_ERR_WRITE_PROT instead of writing into the void.
 */

#include "ufi_firmware.h"
#include "usbd_core.h"

extern USBD_HandleTypeDef hUsbDevice;
extern capture_context_t g_capture;

#define SAMPLE_MS               10u
#define OVERCURRENT_MA          1500u   /* polyfuses hold 1.1 A; INA180 saturates ~1.6 A */
#define OVERCURRENT_SAMPLES     5u      /* 50 ms: motor start-up peaks pass */
#define USB_LOST_MS             300u
#define RAIL_STAGGER_MS         50u     /* 5 V first, then 12 V */

static uint8_t power_mask;
static bool safe_mode;                  /* button B at start-up: supplies stay off */
static uint8_t trip_mask;
static uint8_t oc_count[2];
static uint16_t rail_ma[2];
static uint32_t last_sample_ms, last_activity_ms, usb_ok_ms;
static bool usb_seen, usb_lost;

static const gpio_pin_t* const rail_en[2] = {&PIN_FDD5_EN, &PIN_FDD12_EN};
static const uint32_t rail_adc[2] = {ADC_CH_I_FDD5, ADC_CH_I_FDD12};

/* ============================================================================
 * DRIVE SUPPLIES
 * ============================================================================ */

void ufi_board_power(uint8_t mask)
{
    mask &= 0x03u;
    trip_mask &= (uint8_t)~mask;            /* switching a rail on clears its trip */
    for (int r = 0; r < 2; r++) {
        const bool on = (mask >> r) & 1u;
        HAL_GPIO_WritePin(rail_en[r]->port, rail_en[r]->pin, on ? GPIO_PIN_SET : GPIO_PIN_RESET);
        oc_count[r] = 0;
    }
    power_mask = mask;
}

void ufi_board_init(bool power_on)
{
    last_activity_ms = HAL_GetTick();
    safe_mode = !power_on;
    if (safe_mode) {
        ufi_board_power(0x00);              /* e.g. a shorted drive: host switches on */
        return;
    }
    ufi_board_power(0x01);
    HAL_Delay(RAIL_STAGGER_MS);
    ufi_board_power(0x03);
}

static void sample_rails(void)
{
    for (int r = 0; r < 2; r++) {
        rail_ma[r] = (uint16_t)(ufi_adc_mv(rail_adc[r]) / 2u);
        if (!((power_mask >> r) & 1u)) {
            oc_count[r] = 0;
            continue;
        }
        if (rail_ma[r] > OVERCURRENT_MA) {
            if (++oc_count[r] >= OVERCURRENT_SAMPLES) {
                HAL_GPIO_WritePin(rail_en[r]->port, rail_en[r]->pin, GPIO_PIN_RESET);
                power_mask &= (uint8_t)~(1u << r);
                trip_mask |= (uint8_t)(1u << r);
                led_set(&PIN_LED_ERR, true);
                const board_status_t s = ufi_board_status();
                ufi_v2_event(UFI_V2_EVT_POWER, &s, sizeof(s));
            }
        } else {
            oc_count[r] = 0;
        }
    }
}

/* ============================================================================
 * STATUS
 * ============================================================================ */

bool ufi_board_write_locked(void)
{
    return HAL_GPIO_ReadPin(PIN_WLOCK.port, PIN_WLOCK.pin) == GPIO_PIN_SET;
}

board_status_t ufi_board_status(void)
{
    sample_rails();
    board_status_t s = {0};
    s.power = power_mask;
    s.flags = (uint8_t)((ufi_board_write_locked() ? 0x01u : 0u) | (uint8_t)(trip_mask << 1) |
                        (ufi_sd_present() ? 0x08u : 0u) |
                        (HAL_GPIO_ReadPin(PIN_BTN_A.port, PIN_BTN_A.pin) == GPIO_PIN_RESET ? 0x10u : 0u) |
                        (HAL_GPIO_ReadPin(PIN_BTN_B.port, PIN_BTN_B.pin) == GPIO_PIN_RESET ? 0x20u : 0u) |
                        (safe_mode ? 0x40u : 0u));
    s.i5_ma = rail_ma[0];
    s.i12_ma = rail_ma[1];
    s.board_id_mv = ufi_adc_mv(ADC_CH_BOARD_ID);
    return s;
}

/* v0.7: Apple Disk II port fitted (board ID divider 10k/2.2k); read once */
bool ufi_board_has_apple(void)
{
    static int8_t has = -1;
    if (has < 0) {
        const uint16_t id = ufi_adc_mv(ADC_CH_BOARD_ID);
        has = (id + 200u > BOARD_ID_V07_MV && id < BOARD_ID_V07_MV + 200u) ? 1 : 0;
    }
    return has == 1;
}

/* ============================================================================
 * SAFETY SERVICE (main loop)
 * ============================================================================ */

void ufi_board_activity(void)
{
    last_activity_ms = HAL_GetTick();
}
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

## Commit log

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2026-10-05 UFI Headless: 4-layer layout v0.1, LCSC sourcing, fab outputs
    - build_pcb.py: footprints from the schematic netlist (KIID-linked), placement,
    pre-routed USB-C fan-out and MCU VSS stubs, In1 GND plane
    - make_pcb.sh: Freerouting 2.4.1 routing, violation cleanup, supply widening,
    GND/3V3 pours, stitching vias; DRC 0 errors, schematic parity clean
    - LCSC part numbers via JLCPCB API; crystal X322525MOB4SI (CL 12pF, 2x 18pF)
    - fertigung/: Gerber, Excellon, BOM/CPL (KiCad + JLC format)
    [FDD_Connectors.kicad_sch, Flux_Interface.kicad_sch, IEC_Bus.kicad_sch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]
2026-10-05 UFI Headless: finish PCB v0.1 (layout review fixes, supply pours, docs)
    - Buck: U2 rotated, input cap 1.8 mm from VIN, SW node 2.8 mm straight to L1,
    FB divider at pin 4 (pre-routed, locked)
    - Crystal: HSE_IN/HSE_OUT 9 mm each, no vias (pre-routed, locked)
    - power_pours.py: copper pours following supply routes (+5V/+12V/VBUS ~0.85-1.8 mm)
    - One-off hand repairs after autorouting (IEC_RESET, PWR_SRC, GND anchors)
    - Amiga J7 pinout verified against the Amiga HRM (Appendix E)
    - DRC: 0 errors, 0 unconnected, schematic parity clean; fab outputs regenerated
    [UFI_Headless-B_Cu.gbl, UFI_Headless-B_Mask.gbs, UFI_Headless-B_Paste.gbp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]
2026-10-05 docs: correct Amiga DB-23 floppy pinout per Amiga HRM Appendix E
    - pins 3-23 were wrong (GND on 12/15/20/23 etc.); now per HRM "External Disk
    Interface Specification" incl. SEL2B/DRESB/SEL3B handling
    - adapter needs a DB-23 female (drive cables end in a male plug)
    - flag duplicated RDATA/SEL pins in the Modular J4 header table
2026-10-05 UFI Headless: replace on-board DIN-6 with 1x6 IEC header (DIN socket external)
    J8 is now a 2.54 mm 1x6 pin header (pin n = DIN-6 pin n, LCSC C37208).
    Footprint swapped on the routed board, IEC nets re-routed, IEC_SRQ
    U9-U10 hand-routed on In2. DRC: 0 errors, 0 unconnected, parity clean.
    Firmware unaffected (MCU pins unchanged). Fab outputs and renders regenerated.
    [IEC_Bus.kicad_sch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]
2026-10-05 UFI Headless: via annular ring >= 0.125 mm
    237 vias were below the 0.125 mm AR-check threshold (Freerouting 0.6/0.4,
    dogbones/USB D- 0.48/0.25). Drills shrunk to 0.35 / 0.23 mm instead of growing
    pads, so copper clearances are unchanged. DRC rules now enforce
    min_via_annular_width 0.125, min through-hole 0.2; finish_pcb.py applies the
    same normalisation. DRC: 0 errors, 0 unconnected, parity clean.
    [UFI_Headless-B_Cu.gbl, UFI_Headless-B_Mask.gbs, UFI_Headless-B_Paste.gbp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]
2026-10-05 UFI Headless: no via-in-pad at USB-C, JLC rotation offsets + viewer checklist
    - VBUS vias moved out of the J1 A4/A9 pads (0.5/0.25, inwards: the NPTH
    pegs sit right below the pads); CC2 re-routed left of the A9 via.
    Board-wide check: 0 vias touching SMD pads -> plain tented vias suffice.
    - scripts/jlc_cpl.py: JLC CPL with kicad-jlcpcb-tools package rotation
    offsets and fertigung/JLC_Rotation_Check.md (pin-1 location of the 22
    polarised parts) for the JLC placement viewer.
    DRC: 0 errors, 0 unconnected, parity clean.
    [UFI_Headless-B_Cu.gbl, UFI_Headless-B_Mask.gbs, UFI_Headless-B_Paste.gbp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]
2026-10-05 firmware: adapt to UFI Headless board, fix build
    - board.h / board_headless.c: single pin table + polarity helpers
    (LS07 outputs: low = asserted, LVC14 inputs: high = asserted)
    - flux: RDATA TIM2_CH1 (PA5) + INDEX TIM2_CH2 (PA1), rising edge, shared
    time base; DMA writes linearly into a 224 KB AXI SRAM store (DMA1 cannot
    reach DTCM), revolutions are slices with timestamp-exact boundaries,
    D-cache maintenance around DMA
    - drive: GPIOE/GPIOF pins, Amiga motor via select latch, Apple code kept
    behind BOARD_HAS_APPLE (0 on this board)
    - IEC: separate driver outputs (PD0-4) and receiver inputs (PF4-8)
    - write: shared flux store, index timestamp instead of timer reset
    - USB: stream flux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
    [board.h, board_headless.c, ufi_debug.c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]
2026-10-06 firmware: IEC protocol fixes, TIM3+DMA write path, USB reply/write data
    - IEC: working timeouts (old loops wrapped the counter and never timed
    out), wait for listener ready-for-data, proper EOI handshake and
    turnaround, OPEN/CLOSE secondaries (0xF0/0xE0 were sent as 0x60),
    block read opens buffer channel "#" before U1
    - write: WDATA pulses from TIM3_CH1 (PA6) in down-counting PWM, ARR fed
    by DMA1_Stream1 per flux interval, same 275 MHz tick as capture;
    in-place u16 packing with precompensation, write-protect check,
    WGATE drops after the last pulse
    - USB: replies sent blocking from static memory (stack buffers were
    freed while still transmitting); OUT data reaches the write buff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
    [board.h, ufi_iec.c, ufi_main.c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]
2026-10-06 firmware: 8 MB QSPI PSRAM as flux store (board v0.2)
    - ufi_psram.c: APS6404L on OCTOSPI1 (PB2/PB10/PD11/PD12/PB13/PD13),
    68.75 MHz, reset + ID check, QPI, memory-mapped read/write at
    0x90000000 (1 KB CS boundary, 8 us refresh), MPU region, pattern test
    - flux store = PSRAM (2M samples, up to 20 revolutions) with the 224 KB
    AXI buffer as fallback when no PSRAM answers
    - capture DMA in double-buffer mode, 128 KB chunks (NDTR is 16 bit),
    ISR re-points the idle buffer, scratch target after the last chunk,
    position accounting safe against a pending transfer-complete
    [board.h, ufi_flux.c, ufi_psram.c]
2026-10-06 UFI Headless v0.2: 8 MB PSRAM, ESD, drive polyfuses, test points
    Schematic (new parts get fixed references above the v0.1 maxima, so all
    existing references and PCB links stay unchanged):
    - U11 APS6404L 8 MB QSPI PSRAM on OCTOSPIM P1 (PB2/PB10/PD11/PD12/PB13/
    PD13), C46, CE# pull-up R16
    - D9-D11 ESDA6V1-5SC6 on the 13 Amiga J7 bus lines + MOTOR_A, D12 on IEC
    - F2/F3 polyfuses: drive supplies FDD_5V/FDD_12V for J3 and J7 pins 12/23
    - TP1-TP6 (3V3, 5V, 12V, GND, RDATA, INDEX), excluded from BOM/CPL
    Layout (incremental ECO on the reviewed board):
    - scripts/add_parts.py: re-net pads, collision-aware placement, rip up only
    what is in the way; make_pcb.sh 'eco' step
    - fixes found on the way: s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
    [FDD_Connectors.kicad_sch, Flux_Interface.kicad_sch, IEC_Bus.kicad_sch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]
2026-10-06 firmware: BOOTLOADER command really enters the ROM USB-DFU bootloader
    The magic word was written before the reset but never checked at start-up,
    so 0xFF only rebooted. Now: reply, set a .noinit DTCM flag, reset; main()
    checks it before HAL_Init, disables caches/SysTick/NVIC and jumps to the
    STM32H72x system bootloader at 0x1FF09800 (AN2606).
    [ufi_main.c, ufi_usb.c]
2026-10-06 firmware: self-describing device messages for the host tool
    Every device message now starts with ufi_response_header_t:
    - {0x2E FLUX, 0, 12} + flux_packet_header_t + samples, per revolution
    - {0x2D READ_DONE, status, 1} + [revolutions] ends every capture, also on
    capture errors (the host used to wait forever)
    - GET_STATUS sends a packed 10-byte drive_status_wire_t instead of the
    padded in-memory struct
    [ufi_main.c, ufi_usb.c]
2026-10-06 software/ufi_host: PC host tool for the UFI Flux Engine
    CLI over the USB CDC port (pyserial, auto-detect 1209:4F54): info,
    status, drive control, read/read-disk to SCP, write/write-disk from SCP
    (+verify), erase, abort, IEC, selftest, rpm, reset, bootloader.
    - protocol.py: framing per firmware ec98588, buffered stream reader,
    FLUX/READ_DONE events, error code table from ufi_fixes.h
    - scp.py: SuperCard Pro read/write, 275 MHz <-> 25 ns conversion on
    absolute time (no drift)
    - tests: byte-level fake device (11 tests, no hardware needed)
    Replaces the device I/O of software/cm5/ufi_processor.py, which no longer
    matches the protocol (length-prefixed framing, 16-byte flux header,
    pyusb on the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
    [cli.py, protocol.py, scp.py]
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2026-10-06 UFI Headless v0.3: USB-C source current detection
    - schematic: CC1/CC2 (Rd 5.1k) also to PA0/PA3 (ADC1 INP16/INP15); ECO
    routed on the reviewed board, DRC 0 errors / 0 warnings, parity clean
    - firmware: USB_POWER (0x19) measures CC voltages, reports the allowed
    source current (0.5 / 1.5 / 3 A per Type-C vRd ranges)
    - host tool: ufi usb-power
    - manual_routes: D+ fallback skipped when any D+ via is near its start
    (Freerouting's own via sits 0.25 mm away; it was re-added every run)
    - README: CC pins, Atari SIO option on existing UART pins (PD1/PF6/PD0)
    [MCU_Core.kicad_sch, Power.kicad_sch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]
2026-10-06 firmware: precomp per data rate, safer recalibrate, 10 us step pulse
    - write precompensation from the data itself: shortest MFM interval ~1 us
    -> ED 42 ns, else 125 ns (82077 FDC defaults, via Monster FDC review)
    - recalibrate in three phases: out to TRK0, 6 steps in (TRK0 must release),
    out again; detects a stuck TRK0 sensor (concept from FloppyControl, GPL -
    re-implemented)
    - default step pulse 10 us instead of 3 us (spec minimum), still tunable
    - USB_POWER (CC voltage) committed with v0.3 board
    [ufi_drive.c, ufi_write.c]
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2026-10-06 firmware + host: stream READ_TRACK while the disk turns, ~2 bytes per transition
    READ_TRACK (0x20) now encodes the DMA-stored timestamps in the main loop
    while the capture runs and sends them as UFI_EVT_FLUX_STREAM (0x2C)
    messages, double-buffered so USB and encoding overlap. Lossless delta
    code at full 275 MHz resolution (1/2/5-byte deltas, in-band index
    markers): ~2.0 bytes per flux transition instead of 4, and the transfer
    no longer waits for the end of the capture. READ_TRACK_RAW (0x21) keeps
    the old format; host read_track uses the stream, read_track_raw the old
    path. Verified bit-exact against a host build of ufi_stream.c with
    simulated DMA, timer wrap, index on a transition, overfl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
    [protocol.py, ufi_flux.c, ufi_main.c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]
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2026-10-07 UFI Headless v0.5: switched/measured drive supplies, write lock, microSD, expansion
    Hardware (A1-A9): FDD_5V/FDD_12V high-side P-FET switches (off in reset)
    with 0.1R + INA180A1 current sense, TVS at both outputs; WRITE LOCK
    jumper J11 gates WGATE through 74LVC1G32 (TP8 now shows the gated
    signal); expansion header J9 (I2C1, 2 GPIO, button lines, 3V3/5V),
    buttons SW3/SW4; microSD J10 on SDMMC2 with the card slot facing the
    top edge; board ID divider on PA4; test points TP7/TP8. 12V reverse
    protection already existed; 8-inch 50-pin port left out (board size).
    ECO placed 37 parts; Freerouting plus hand routes for the rest.
    New scripts/eco/ tools (maze router, route check, cluster/occupancy
    ma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
    [FDD_Connectors.kicad_sch, Flux_Interface.kicad_sch, IEC_Bus.kicad_sch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]
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2026-10-07 Remove the abandoned CM5/modular design, keep UFI Headless only
    Deleted: old boards and sheets (UFI, Modular, Compact, Mainboard, CM5,
    GB/GBA, MIG), shared footprint/symbol libraries (unused by Headless),
    production files, modules/, CM5/MIG software and 29 concept documents.
    Kept: kicad/UFI_Headless, firmware, software/ufi_host and the Amiga DB23
    cable doc. README rewritten for the headless device; Headless no longer
    references the removed footprint library. ERC 0 / DRC 0 unchanged.
    Everything removed stays available in the git history.
    [CM5_Interface.kicad_sch, FDD_Connectors.kicad_sch, Flux_Interface.kicad_sch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]
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2026-10-07 ci: build the firmware on every push (STM32CubeH7 v1.11.0 sparse, GCC arm-none-eabi)
    Fails on any compiler warning in our own sources; uploads .bin/.hex/.elf.
2026-10-07 v0.6: soldered SD NAND replaces the microSD slot; stand-alone dump + USB drive mode
    Board (closed enclosure, no card access):
    - J10 microSD removed; U15 SD NAND CSNP32GCR01-AOW (4 GB, C2841139) on the same
    SDMMC2 lines, project footprint fits MKDV8GIL-AST (1 GB) as well
    - PG13 card detect dropped; board ID R18 4.7k (1055 mV = v0.6)
    - project symbol/footprint library lib/, kisch.py + add_parts.py look there first
    - ECO re-route; ERC 0, DRC 0 incl. warnings, 0 unconnected, parity clean, no via-in-pad
    - new eco tools remove_part.py, set_value.py; fab outputs regenerated
    Firmware 1.3:
    - ufi_sd.c: block access + FatFs R0.12c disk glue (Cube middleware, ffconf.h)
    - ufi_dump.c: button A >= 1 s /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
    [FDD_Connectors.kicad_sch, Flux_Interface.kicad_sch, IEC_Bus.kicad_sch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]
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2026-10-07 Firmware 1.6: Shugart bus pin 34 = READY, no disk change line
    Checked J6 against pinouts.ru 'Floppy Diskdrive pinout': the PC pinout matches pin for
    pin; on the Shugart bus pin 34 is READY (not DSKCHG) and pin 2 is the drive's /DCD
    output (ours is DENSITY, both open collector, not readable).
    - DS0-DS3: ufi_drive_disk_changed() = false, ufi_drive_ready() reads pin 34
    - USB floppy on the Shugart bus: no disk without READY (motor on), cached tracks are
    dropped when the motor stops (a swap goes unseen), detection retry 30 s
    - floppy simulation passes for PC and Shugart bus
    - README / schematic note: Shugart pin differences and the missing change detection
    [FDD_Connectors.kicad_sch]
2026-10-07 Firmware 1.7: USB floppy formats DMF, ED, Atari ST, Commodore 1581, Amiga 880K
    - ufi_mfm.c: dense IBM tracks (gap 3 shrinks, IAM dropped when needed), ID side swap
    (1581), Amiga trackdisk decoder/encoder (odd/even longs, XOR checksums)
    - ufi_floppy.c: detection over IBM 500k/250k/300k/1M + Amiga 250k; DMF 1.68M, ED 2.88M
    (read only: write pulse too long for 1 Mbit), Atari ST 9/10 sectors up to 83 cyl and
    11 sectors (read only), 1581 800K, Amiga 880K; read-only formats report write protect;
    sector masks 64 bit (36 sectors)
    - host simulation: codec round trip for 9 formats (+-15 % jitter, +-3 % speed), floppy
    layer end to end for 8 formats (ST 11 only via the shared decoder, not simu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
    [ufi_floppy.c, ufi_usb.c]
2026-10-07 Firmware 1.8: dump quality report (DUMPnnnn.LOG, weak tracks re-read) and disk-to-disk copy
    - format probed on track 0.0 (IBM 500k/250k/300k/1M, Amiga); every track decoded,
    tracks with missing sectors read up to 3 times; log: good/expected sectors, rpm,
    reads per track, bad track count
    - copy: UFI.CFG button_a=copy, copy_from/copy_to (a, b, amiga, ds0-ds3); revolution 0
    of the source written to the destination, read-back verify (same good sectors for a
    known format, else flux count within 5 %); COPY_START 0x54, status via DUMP_STATUS
    - dump simulation: SCP still byte-identical, log written
    - docs: UFI.CFG keys, bring-up steps 7.2c/7.2d, protocol
    [ufi_dump.c, ufi_usb.c]
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2026-10-07 Firmware 1.10: Greaseweazle-compatible protocol (UFI.CFG protocol=gw)
    - ufi_gw.c: Greaseweazle command set over CDC (independent implementation after the public
    domain cdc_acm_protocol.h): GET_INFO, SEEK, HEAD, SET/GET_PARAMS, MOTOR, READ/WRITE/ERASE_FLUX,
    GET_FLUX_STATUS, SELECT/DESELECT, SET_BUS_TYPE (IBM PC A/B, Shugart 0-3), SET/GET_PIN, RESET,
    watchdog; clear comms via SET_LINE_CODING 10000 baud; flow-controlled 8 KB receive ring
    - ufi_stream.c: same streamed capture in the Greaseweazle flux code at 68.75 MHz (275 MHz / 4,
    drift-free), first index included, 0-terminated
    - own USB ID 1209:4F57, product 'UFI Flux Engine (gw-compat)' (found by gw without --device);
    mode switch mi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
    [ufi_dump.c, ufi_gw.c, ufi_mode.c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]
2026-10-07 v0.7: Apple Disk II port (J14/J15), board 110 x 97 mm; firmware 1.11: drives apple/apple2
    Board
    - Apple_Port sheet: J14 2x10 (Disk II controller pinout), SN74AHCT244 outputs at FDD_5V
    (phases, /ENABLE 1+2, /WRREQ, WRDATA), 74LVC2G17 inputs (RDDATA, WRPROT), ICL7662 -12V
    from FDD_12V, reset-safe 10k arrays, ESD on all port lines, J15 = /ENABLE drive 2
    - MCU: RDDATA PA2 (TIM2_CH3), WRDATA PA7 (TIM3_CH2), PH0/1/3 PF12/13/15, PH2 PG6,
    EN1 PG5, EN2 PB12, WRREQ PB14, WRPROT PB15; board ID 10k/2.2k = v0.7
    - outline +12 mm (eco/extend_outline.py), mounting holes H5/H6, ECO + Freerouting, hand
    routes for EN1/PH2 (PB11/PF14 unreachable), FDD_12V to J14/U18, D16 GND via;
    J14 uses a project co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
    [Apple_Port.kicad_sch, MCU_Core.kicad_sch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]
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2026-10-07 v0.7 silkscreen: J16 pin 1, 5V D- D+ GND and key marker X; J19 and J15 pin labels
    add_silk_label.py replaces same-text labels only near the target.
    [UFI_Headless-B_Cu.gbl, UFI_Headless-B_Mask.gbs, UFI_Headless-B_Paste.gbp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]
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2026-10-09 Firmware 1.14: internal index simulation (INDEX_SIM mode bit1 replaces the drive's INDEX line in capture/write/erase; UFI.CFG index_sim_mode); ufi index-sim --internal; docs/USB_Protokoll.md
    [cli.py, protocol2.py, ufi_diag.c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]
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2026-10-10 Firmware 1.14: SELFTEST 0x07 (timer, USB SOF ppm, PSRAM, SD, rails, board id, USB-C, drive lines, IEC loopback, index loop, SELFTEST.LOG) and fault record (faults reset at once, CRASH.LOG + reset cau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
2026-10-11 Firmware 1.15 (audit F02b): long tracks stream through a two-half DMA ring in SRAM2 (circular DMA, HT/TC refill from the packed track, exact stop counted against the DMA counter, underrun -> error wi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
2026-10-11 Firmware 1.16: decoded sector images straight to the SD NAND (UFI.CFG format=img|adf, DUMP_START byte 5, ufi dump --format): sectors of the format probed on track 0 as DUMPnnnn.IMG/.ADF, missing sect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
2026-10-11 Firmware 1.16: IEC block write through the drive's DOS (B-P + U2, DOS code returned), IEC_BLOCK 0x35 (U1 read / U2 write), IEC_MEM op 4 = DOS status line; host ufi iec-write/iec-read/iec-status with 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
2026-10-11 Firmware 1.16: write an image from the SD NAND onto the disk without a PC (UFI.CFG button_a=write + write_file, WRITE_START 0x64, ufi sd-write): SCP flux (revolution 0, host rounding, clamp), IMG/IMA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
2026-10-11 Firmware 1.17: verify level 3 compared only the first 512 bytes of every sector (1024-byte sectors half unchecked, 128/256-byte sectors with stale bytes); CRC-32 now over 128 << N with the size code 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
2026-10-11 Firmware 1.17: HxC HFE v1 (B7) - dump format=hfe (UFI.CFG / DUMP_START byte 5 = 3): revolution 0 of every track through the MFM decoder's clock recovery into one bit per cell, bit rate and encoding f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
2026-10-11 Host: HFE v1 images (hfe.py, same integer arithmetic as the firmware, so dump and host conversion of one flux set are byte-identical): ufi read/read-disk -o x.hfe (--bitrate, --encoding; rate guessed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
2026-10-11 C64 PSU Guard v0.1: separate protection board between a PC power supply and the 4-pin DIN power input of a 1541-II / 1581 - per rail AO3401A reverse-polarity blocking, TVS, TPS25921A eFuse (5 V: 1.2 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
2026-10-16 Tests: fuzz the whole v2 dispatcher behind generated driver stubs, measure native coverage
    run_fuzz.py --target v2: ufi_v2.c compiled as a whole on the host (tests/hal_stub/ supplies
    the HAL/USB declarations) with the real job, resource, cancel, capability, media, write-codec
    and quality modules; fuzz_stubs.py generates every other callee from the header prototypes
    (oracle-driven error codes, flags, states and counts; zeroed buffers for pointers; zero
    structs). fuzz_v2.c feeds CRC-correct request/DATA frames, raw bytes, operation ends, events
    and comms clears, optionally with Greaseweazle owning the drive, and checks every emitted
    frame. 2.1 M runs / 61 s without a finding; the two early rep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
2026-10-16 Tests: fuzz the stand-alone SD module through an in-memory FatFs, static analysis over 34 modules
    run_fuzz.py --target sd: ufi_dump.c as a whole with the real image/MFM/HFE/verify/quality modules
    and 43 generated stubs. fuzz_sd.c implements the FatFs API (tests/hal_stub/ff.h) on the fuzz input:
    read files return the input zero padded to the size the image kind needs, write files are bounded
    sinks, rare FatFs errors come from the oracle, f_mkfs asserts. Captures are synthesised from the
    input, half of them as valid IBM-MFM tracks from the firmware's own encoder. One input runs an SD
    write (SCP, HFE v1/v3, ADF, IMG, D64, D81), the UFI.CFG parser plus the host file API, or a dump or
    copy to SD,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
2026-10-17 Firmware 1.18-dev: named timing presets via ANALYSIS_JOB [18, id] (1 factory, 2 conservative = KryoFlux 3.00 defaults: step 8 ms, settle 40 ms, 38 ms on direction reversal, 1 ms side, 800 ms spin-up,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
2026-10-17 Tests: fuzz the drive control module as a whole (run_fuzz.py --target drive) against a per-drive head model with TRK00 sensor faults, checking seek/recalibrate positions, profile round trips and the 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
2026-10-17 Firmware 1.18-dev: format 7 = Apple II 5.25-inch 16-sector 6-and-2 GCR decoder (D5 AA 96 address field with 4-and-4 volume/track/sector/XOR checksum, D5 AA AD data field with 342 nibbles, running XOR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
2026-10-17 Firmware 1.18-dev: format 7 decoder options via ANALYSIS_JOB op 33 (address/data prologue, address/data epilogue, flags: keep bad address checksum, ignore epilogues, any track/sector, data without ch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
2026-10-17 Host: ufi apple-gcr [FIELD=VALUE|reset] and apple_gcr_options() for the format 7 decoder options (hex marks, named flags, sector flag names); fake device and test; README
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2026-10-17 Firmware 1.18-dev: decoder tolerance flags for every format via ANALYSIS_JOB op 34 (keep bad header, ignore epilogues, any track, data without checksum, data without header; same bits as the Apple op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
2026-10-17 Firmware 1.18-dev: Apple II nibble statistics via ANALYSIS_JOB op 35 (178 bytes) - the format 7 decoder frames nibbles in its search state and counts per revolution nibbles, 10-bit self-sync nibbles,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
2026-10-17 Firmware 1.18-dev: Apple II 13-sector 5-and-3 data fields (op 33 flag 0x20, 410 nibbles, documented low-bit/high-bit layout, fixed 32-symbol alphabet), loadable 6-and-2 symbol table via ANALYSIS_JOB 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
2026-10-17 Firmware 1.18-dev: session write lock via ANALYSIS_JOB op 37 ([37] reads lock and jumper state, [37, 1] engages until MCU reset, no disengage over USB), new status 22 SOFT_WRITE_LOCK distinct from wr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
2026-10-17 Firmware 1.18-dev: per-sector verify report via ANALYSIS_JOB op 40 - the read-back matcher keeps a state per reference sector (missing / ok / CRC error / different content, best result across the dec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
2026-10-17 Firmware 1.18-dev: speed check before writing via ANALYSIS_JOB op 41 - tolerance in per mille of the source index period (0 = off, max 500, BUSY while busy) and the last measurement in the reply; a n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
2026-10-18 Firmware 1.18-dev: analysis job flag RESEEK 0x40 - before every retry capture (attempt 2 and later) the job seeks one track outward (inward at track 0, same quarter) and the capture's own seek settle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
2026-10-18 Firmware 1.18-dev: write precompensation per write and per zone - the selection moves from the codec into ufi_write_precomp_select() and counts the physical track (double_step: logical n at 2n; the b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
2026-10-18 Firmware 1.18-dev: track survey as a board-side job, ANALYSIS_JOB op 46 - [46, 1, first, last, sides mask, flags] seeks every track and side of the range, reads one revolution each and classifies it 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
2026-10-18 Firmware 1.18-dev: weak-cell markers in the extended WRITE, flags2 bit 3 - item 7 (gaps > 238 us without artificial pulses) already lives in the extended path, item 6 builds on it: flags2 bit 3 follo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
2026-10-24 KiCad v0.7 rework, schematic stages A1-A3: automatic 5 V source selection, discrete FDD termination, front-panel header - Power: J18 (5V_SEL jumper) removed, U19 TPS2116DRL selects external 5 V (J17,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
2026-10-24 Host: bare-board bring-up sequence python -m ufi_host.bringup - identification, DESCRIBE/FEATURES, DIAGNOSTICS, board status and supplies, SD info, firmware self-test with the expectations of a board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
2026-10-24 KiCad v0.7 rework, A3 follow-up from the owner's review: front-cable protection and I2C pads - D18-D21 changed from SMF3.3CA to PESD3V3L1BA (SOD-323, bidirectional, low leakage; the SMF3.3CA leaks up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
